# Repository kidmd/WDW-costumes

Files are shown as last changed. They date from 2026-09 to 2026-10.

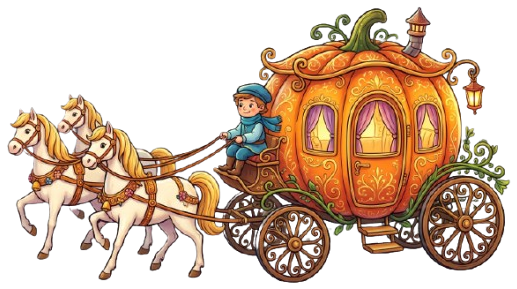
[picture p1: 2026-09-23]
assets/cinderellas_coach.png

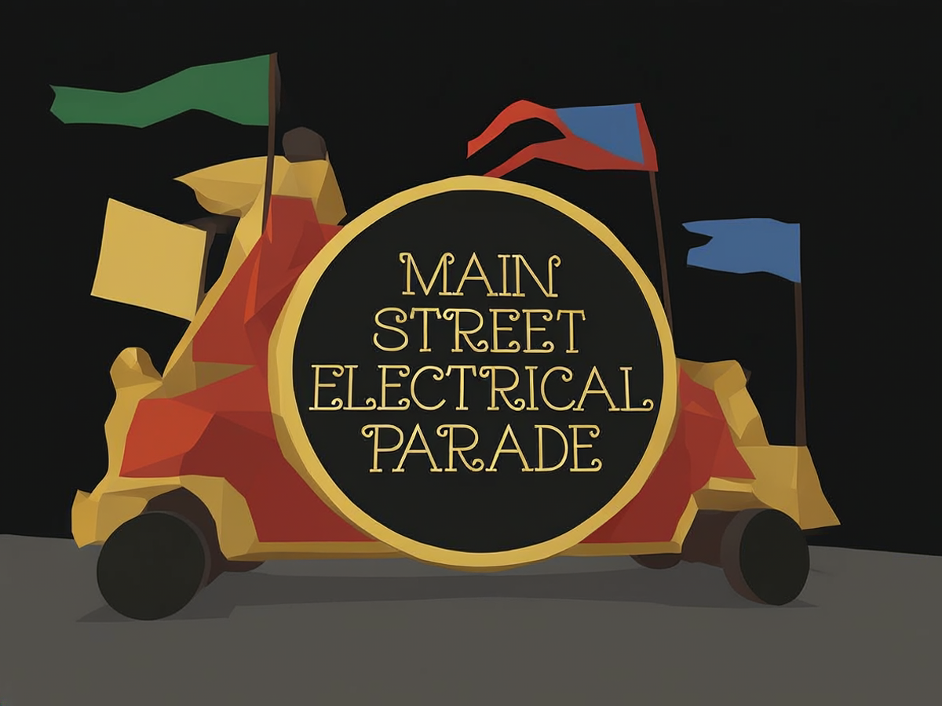
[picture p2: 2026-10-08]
assets/Drum.png

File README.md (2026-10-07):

# Main Street Electrical Parade - Synchronized LED Costumes (WDW 10K)

This project powers synchronized, addressable LED lighting across **7 runner costumes** inspired by Disney's **Main Street Electrical Parade** for the Walt Disney World 10K.

Worn by our **7-member family running team** (2 brothers, 1 sister, 1 brother-in-law, and 3 sisters-in-law) and engineered with love by the **3 brothers** (2 running, 1 supporting behind the scenes).

---

## The Concept

Each runner wears a matte black technical running shirt outlined with glow-in-the-dark paint and illuminated by individually addressable **WS2812B "Seed" / Pebble LEDs** to replicate the vintage incandescent bulbs of the parade floats.

An **ESP32** microcontroller on each runner coordinates lighting patterns wirelessly in real time using **ESP-NOW** (connectionless peer-to-peer 2.4 GHz radio), requiring **no Wi-Fi router or cellular service**.

### The 7 Floats Roster

1. **The Train (Casey Jr.):** Warm white chugging locomotive headlight & steam pulses (parade leader pulling the Title Drum).
2. **The Title Drum:** Golden chasing marquee border, "Disney" electric text accent.
3. **The Turtle:** Whimsical spinning shell spirals, blinking amber eyes, and teal/green shell pattern.
4. **The Snail:** Multi-color rotating rainbow spiral shell wheels and neon antennae glow.
5. **Cinderella's Coach:** Shimmering fairy dust sparkle and midnight pumpkin carriage glow.
6. **Pete's Dragon (Elliott):** Chartreuse/green body scales with orange/red fire breathing effect.
7. **To Honor America (Flag & Eagle):** Patriotic red, white, and blue finale fireworks shimmer with majestic illuminated eagle.

---

## Hardware Specifications

* **Microcontrollers:** ESP32 (e.g. ESP32-WROOM-32D or Seeed XIAO ESP32)
* **LED Strands:** 200 WS2812B / WS2811 Addressable 5V Seed/Pebble Pixels (100 front + 100 back duplicated, black wire, ~1" to 2" spacing)
* **Data Resistor:** 220 Ω to 470 Ω inline on the data line between GPIO 16 and LED Data-In
* **Power Source:** 5V USB portable power bank (5,000–20,000 mAh rating, FastLED hardware limited to 2000 mA / 2.0A) per runner with built-in simulator Battery Life & Power Budget Calculator
* **Costume Simulation:** Visual browser-based layout engine (`python simulator.py` @ `localhost:8000`) with built-in presets (Pete's Dragon, Cinderella's Coach, Carriage No Horses, Casey Jr., Title Drum, Turtle, Snail, Eagle), multi-layer Cricut Heat Transfer Vinyl (HTV) cut file exporter suite (All-in-One master SVG, color-mat-by-color-mat SVGs, and 6×3mm tangent pill cutouts with 4-corner heat press registration marks), Universal Undo / Redo engine (`Ctrl+Z` / `Ctrl+Y`) with 50-step snapshot history and floating toolbar buttons, 7-Shirt Fleet Show Creator Studio featuring a 19-block choreography palette (traveling waves, dual collision shockwaves, butterfly ripples, fairy dust waterfalls, fleet pulses, wig-wags, sparkle storms, baton chases, and grand finales), interactive NLE-grade visual timeline block editor (drag-to-stretch, rolling trim, and drag-and-drop reordering), Animation Group Spatial Suite & Pre-Built Shape Stamp Library (parametric Circles/Wheels, Arches, Waves, Stars/Sparkles, Lines/Rulers, and Fireworks Starbursts with aspect-ratio correction, interactive click-to-place positioning, Cross-Shirt Clipboard, Rotate 90°, Flip H/V, Scale LED Spacing while maintaining exact shape, and auto-rearranging remaining unassigned LEDs), multi-float live Wi-Fi UDP streaming (`Opcode 0x02`), pre-race Corral Roll Call & ESP-NOW Fleet Radar (instant identification strobe, 4s rapid attendance wave, signal RSSI, battery voltage, and lineup readiness), race-day battery life calculator with 7-float power breakdown, double-tap 4-second rapid attendance wave, 300ms debounced one-shot trigger and early stop, "Snap to 30.0s" sequence normalization, JSON show persistence, 1-click & double-click Single View editing from fleet cards, real 700-LED mini-shirt visualizer, multi-mode wireless sync (ESP-NOW Wave, Free-Run, Show Sequence), full-graphic LED re-distribution (maintaining strictly 100 LEDs per shirt), and authentic runDisney 10K Race Bib (#1952) with Chip & Dale and BibBoards fastener clearance.
* **3D-Printable Flexible TPU Armor Plates & Protective Rear Lids (5-Color Multi-Material & Single STL):** High-speed parametric fabrication pipeline (`scripts/compile_clean_tpu_panel.py`) compiling wearable 9.0mm deep-chassis armor trays and matching **2.0mm protective rear cover lids** (`tpu_panel_{front|back}_lid.stl`). Features **5-Color Multi-Material FDM printing** (for Bambu Lab AMS / Snapmaker Dual) with a monolithic black structural chassis (`chassis_black.stl`), 4 zero-overlap jigsaw front color inlays, 3x3mm through-aperture windows for LEDs, and an 8-point M2 perimeter screw fastening system with 1.2mm stepped alignment ridges. Includes 1-click **Bambu 3MF** and **5-Color ZIP bundles** (packaging tray, inlays, and rear lid), selectable plate sizing (Small ~6.5", Medium ~8.0", Large ~10.0"), selectable LED counts (50, 75, 100 LEDs), and an interactive 3D WebGL inspector (`#tpuPreviewModal` & `3d_panels/tpu_panel_preview.html`) with live Tray vs Rear Lid 3D inspection.

---

## Wireless Synchronization (ESP-NOW)

* **Protocol:** ESP-NOW broadcast (Destination MAC `FF:FF:FF:FF:FF:FF`).
* **Architecture:**
  * **Float 1 (Primary Master Leader):** Front locomotive broadcasting timing ticks, BPM tempo, master brightness, show triggers, and photo mode.
  * **Float 7 (Co-Leader / Rear Marshal):** Rear anchor with full co-leader authority to command the rear pack independently if runners split.
  * **Floats 2–6 (Followers):** Listen to broadcast packets, lock to master clock, and execute individual autonomous sequences or synchronized routines.
* **Dual Hardware Button Controls (Button 1: GPIO 4 / BOOT GPIO 0, Button 2: GPIO 33):**
  * **Power-Up (Plug USB):** Boots directly into **🌙 Corral Standby Mode** (12% dim midnight starlight twinkle, < 120mA), saving 80%+ battery during the 60–90 min starting wait.
  * **Button 1 — Single Tap (< 600ms):**
    * 👑 *Leader (Float 1 & 7):* When asleep or in Photo Mode, wakes **ENTIRE FLEET** into **Solo Show Mode** (individual float identities). When running awake, launches the **30s Synchronized Fleet Routine** (or toggles/cancels during active routine).
    * 👥 *Follower (Floats 2–6):* When asleep or in Photo Mode, wakes/exits **THAT RUNNER ONLY** into Solo Show Mode. When running awake, **IGNORED** (keeps parade show running without accidental interruption).
  * **Button 1 — Double Tap (< 400ms):**
    * 👑 *Leader:* Triggers **⚡ 4-Second Rapid Attendance Roll Call** wave across all 7 costumes.
    * 👥 *Follower:* Ignored (roll call reserved for Leader).
  * **Button 1 — Long Hold (5s):**
    * Enter **Float ID Configuration Mode** (1 to 7) with a 1s–4s progressive white LED charging meter and permanent NVS flash auto-save. Releasing before 5s cleanly aborts back to baseline without triggering show routines.
  * **Button 2 — Single Tap (< 600ms):**
    * 👑 *Leader:* Toggles **📸 Castle Photo Mode** (solid, steady, non-flickering full graphic background colors) across the **ENTIRE FLEET**.
    * 👥 *Follower:* Toggles **📸 Castle Photo Mode** **LOCALLY** (solid full graphic background colors) for that runner.
  * **Button 2 — Long Hold (3s):**
    * 👑 *Leader:* Drops **ENTIRE FLEET into Corral Standby (Sleep) Mode**. Stays locked in Standby even if held >3s—requiring an explicit click to enter Photo Mode.
    * 👥 *Follower:* Drops **THAT RUNNER ONLY into Corral Standby Mode**. Stays locked in Standby even if held >3s—waiting for physical release so it never accidentally pops into Photo Mode.

---

## ⚡ Quick Start for Family Runners & Crew (No Git Required!)

You don't need Git, Google Antigravity, or any programming tools:
1. **Download:** Click the green **`<> Code`** button above ➔ **`Download ZIP`** (or [Click Here to Download ZIP](https://github.com/kidmd/WDW-costumes/archive/refs/heads/main.zip)).
2. **Extract:** Right-click the `.zip` file and select **Extract All...** to any folder on your computer.
3. **Plug in & Flash:** Connect your ESP32 via USB and double-click **`flash_firmware.bat`** (Windows) or **`flash_firmware.command`** (Mac).
4. See **[`FLASHING_INSTRUCTIONS.md`](FLASHING_INSTRUCTIONS.md)** for complete hardware wiring and float selection instructions.

---

## Project Structure & Documentation

* [`ESP32_WIRING_PLAN.md`](ESP32_WIRING_PLAN.md): **🔌 ESP32 Hardware Wiring Plan & Electrical Specification** — Complete schematics, pinout tables, tactile button wiring, 4-pin orientation guide, 220–470 Ω data resistor, power bus injection, and computer power isolation rules.
* [`RACE_DAY_BUTTON_GUIDE.md`](RACE_DAY_BUTTON_GUIDE.md): **🏃🏰 Race Day Button Field Guide & Controller Cheat Sheet** — Pocket manual with gesture timings, Leader vs Follower matrices, chronological corral countdown playbook, and state flow diagrams.
* [`RACE_DAY_PACKING_CHECKLIST.md`](RACE_DAY_PACKING_CHECKLIST.md): **🏰 Race Day Packing Checklist & Field Manual** — Pre-race hardware checklist, spare ESP32s, battery survival, repair toolkit, weather kit, and countdown timeline for the 7-runner family team.
* [`CRICUT_MASTER_SVG_USER_GUIDE.md`](CRICUT_MASTER_SVG_USER_GUIDE.md): **✂️ Cricut Master SVG User Guide** — Step-by-step instructions for Cricut Design Space, multi-layer HTV cutting, and heat-press registration.
* [`SIMULATOR_QUICKSTART.md`](SIMULATOR_QUICKSTART.md): **⚡ Simulator Quickstart Guide (TL;DR)** — 2-minute cheat sheet for launching the simulator, moving/trimming timeline clips, testing the fleet show, and streaming to LEDs.
* [`SIMULATOR_USER_GUIDE.md`](SIMULATOR_USER_GUIDE.md): **Complete User Guide & Theatrical Lighting Manual** for the browser simulator, multi-layer timeline, and ESP32 hardware flasher.
* [`FLASHING_INSTRUCTIONS.md`](FLASHING_INSTRUCTIONS.md): **⚡ Quick Flashing Guide for Family Runners & Crew** (Double-click 1-click flasher, Web Browser flasher, and Arduino IDE).
* [`CRICUT_ARTWORK_GUIDE.md`](CRICUT_ARTWORK_GUIDE.md): **🎨 Cricut HTV Costume Artwork Guide** (Layered SVG cut files, color mats, heat press settings, and visual catalog).
* [`PROJECT_PROGRESS.md`](PROJECT_PROGRESS.md): Live project milestones, wiring specifications, and development changelog.
* `start_simulator.bat`: One-click Windows desktop simulator launcher.
* `flash_firmware.bat`: One-click Windows desktop firmware flasher script.
* `flash_firmware.command`: One-click Mac / Linux desktop firmware flasher script.
* `arduino/MSEP_Costume/`: Ready-to-open native Arduino IDE sketch.
* `firmware/`: Pre-compiled ROM binary files (`firmware_float1.bin` through `firmware_float7.bin`, `firmware.bin`, `bootloader.bin`, `partitions.bin`) and Web Serial manifests.
* `src/`: C++ / Arduino firmware source code for ESP32.
* `simulator/`: Web-based visual simulator and theatrical cue director.
* `platformio.ini`: PlatformIO configuration with board targets and library dependencies (FastLED).

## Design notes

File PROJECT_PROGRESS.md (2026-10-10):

# Main Street Electrical Parade (WDW 10K) - LED Control System

## Project Overview
This project coordinates synchronized, addressable LED lighting across **7 runner costumes** styled as the iconic floats of Disney's **Main Street Electrical Parade** for the Walt Disney World 10K.

* **Theme:** Main Street Electrical Parade (7 Floats)
* **GitHub Repository:** [kidmd/WDW-costumes](https://github.com/kidmd/WDW-costumes)
* **Base Shirts:** Black moisture-wicking technical running shirts with glow-in-the-dark graphic outlines
* **Lighting:** 5V WS2812B "Seed / Pebble" RGBIC fairy pixel strings (~1" to 2" spacing for discrete light bulb look)
* **Runners & Engineering Team:** 7 family runners hitting the course together (2 brothers, 1 sister, 1 brother-in-law, and 3 sisters-in-law), supported and engineered by the 3 brothers (2 running, 1 supporting).
* **Controller:** ESP32 Microcontrollers (1 per runner)
* **Wireless Protocol:** ESP-NOW (connectionless 2.4GHz peer-to-peer broadcast; no router/hotspot needed)
* **Power Source:** 5V USB portable power bank per runner

---

## The 7-Runner Roster & Float Assignments

| Float # | Unit / Float Name | Visual Concept & Accent Lights |
| :---: | :--- | :--- |
| **1** | **The Train (Casey Jr.)** | Warm white chugging headlight, locomotive steam pulses (parade leader pulling the Title Drum) |
| **2** | **The Title Drum** | Golden chasing marquee border, "Disney" electric text accent |
| **3** | **The Turtle** | Whimsical spinning shell spirals, blinking amber eyes, teal/green glow |
| **4** | **The Snail** | Rotating rainbow spiral wheels, neon antennae, vibrant spinning motion |
| **5** | **Cinderella's Coach** | Brilliant fairy dust shimmer, pumpkin coach starlight glow |
| **6** | **Pete's Dragon (Elliott)** | Chartreuse/green scales with orange/red fire breathing effect |
| **7** | **To Honor America (Flag & Eagle)** | Cascading patriotic red/white/blue starbursts & majestic illuminated eagle |

---

## Hardware Architecture & Bench Wiring

### 1. Key Components
- **Microcontrollers:** ESP32 development boards (standard DevKit or Seeed Studio XIAO ESP32)
- **LED Strands:** WS2812B 5V Seed/Pebble pixels (black wire, individual encased nodes)
- **Resistor:** 220 Ω to 470 Ω inline on the data line (between ESP32 GPIO and LED Data-In)
- **Power:** 5V USB Battery Pack (2.1A+ output rating)

### 2. Bench Power Isolation Rules
* **USB-C from Computer:** Plugs into the ESP32 USB-C port for code upload and serial debugging.
* **5V Power Brick / Adapter:** Plugs directly into the breadboard +5V rail powering the LEDs.
* **GND (Common Ground):** ESP32 GND and Power Bank GND are connected together.
* **DO NOT** connect the 5V power bank rail to the ESP32 VIN pin while the USB-C cable is connected to the PC.

---

## Roadmap & Milestones

- [x] **Milestone 1: Bench Setup & Single-Strand Validation**
  - [x] Configure toolchain in Antigravity (PlatformIO Core 6.2.0 installed & verified).
  - [x] Create baseline MSEP animation sketch with FastLED current limiting (`src/main.cpp`).
  - [x] Build and compile firmware successfully with FastLED library.
  - [x] Connect ESP-32D via USB and flash test firmware:
    - **Board 1 MAC:** `B0:CB:D8:C8:49:84`
    - **Board 2 MAC:** `A4:F0:0F:64:33:A0`
  - [x] Bench wire ESP32 with isolated 5V power, common ground, and GPIO 16 (pin 8 on right).
  - [x] Verify discrete bulb appearance, color calibration (RGB order established), and animation playback.

- [x] **Milestone 2: ESP-NOW Wireless Synchronization**
  - [x] Build unified firmware with auto-role detection via MAC address (`src/main.cpp`).
  - [x] Flash Board 1 as **Leader (Float 1 - Title Drum)** [`B0:CB:D8:C8:49:84`].
  - [x] Flash Board 2 as **Follower (Float 2 - Casey Jr.)** [`A4:F0:0F:64:33:A0`].
  - [x] Implement synchronized modes: Marquee Chase, Float Sparkle, Starlight Twinkle, and Traveling Parade Wave.
  - [x] Verify bench latency and wireless lockstep synchronization between both strands (SUCCESS).

- [x] **Milestone 3: Python LED Costume Simulator & Visualizer**
  - [x] Lightweight Python local server with zero external dependencies (`simulator.py`).
  - [x] Interactive Single-Shirt view of Pete's Dragon with metallic green reflective styling on black shirt.
  - [x] 50 interactive addressable LEDs with drag-and-drop repositioning and JSON export.
  - [x] Dynamic lighting engine: Green glow with starlight sparkles, fire-breathing snout pulse, marquee chase.
  - [x] Live sliders: Speed (BPM), Sparkle Frequency, Green Hue, Brightness, Glow size.
  - [x] 7-Shirt Fleet Lineup view with animated synchronized Traveling Wave across all 7 floats.
  - [x] One-click FastLED C++ code generator for immediate copy-pasting into ESP32 firmware.

- [ ] **To-Do (Pending Fairy Lights Arrival): Resume Custom Costume Simulator Testing**
  - [ ] Await delivery of WS2812B 5V "Seed / Pebble" RGBIC fairy pixel strings.
  - [x] Implement Real-Time Live Streaming / Tethering (stream pixel colors over Wi-Fi from `simulator.py` directly to ESP32 for instant live-preview without re-flashing).
  - [ ] Resume custom character costume layout and testing with the Web Simulator (`simulator.py`).
  - [ ] Confirm RGB color order on new fairy light hardware and verify power limits.
  - [ ] Test 100-LED Pete's Dragon scatter pattern with starlight diamond sparkles on wearable fairy lights.

- [ ] **Milestone 4: Parade Animation Sequencing**
  - [ ] Implement classic traveling parade chase (running down the line of 7 floats).
  - [ ] Implement float-specific accent animations (fire flickers, clock chime, sparkles).
  - [ ] Optional: Sync tempo to the *Baroque Hoedown* soundtrack.

- [ ] **Next Up / Feature Queue (Imagineering Active Pipeline):**
  - [x] **Interactive Visual Timeline Block Editor:** Directly drag and stretch choreography block edges on the canvas timeline to adjust durations visually; drag-and-drop block reordering on timeline tracks.
  - [x] **Race-Day Battery Life & Power Budget Calculator:** Analytical battery capacity estimator (5,000 mAh / 10,000 mAh packs) modeling running pace (60–90 min 10K), average mA draw per runner, and 30s fleet show trigger frequency.
  - [x] **"Corral Roll Call" / ESP-NOW Fleet Radar Diagnostic:** Pre-race bench & corral RF sniffer verifying that Floats 1 through 7 are powered, connected, and responding on the sync channel before race start.

---

## Progress Log

### 2026-10-10 06:10 - Workbench Mirrored Back View for LED Placement & Assembly Guide
- **Implemented Mirrored Back View in Placement Guide Mode (`simulator/app.js` & `simulator/index.html`):**
  - Horizontally mirrored the placement guide canvas layout, chest graphic artwork (`activeImg`), race bib, LED coordinates (`1.0 - x`), wire routing traces, optical 3×3mm apertures, and interactive mouse drag/click hit-testing when in Placement Guide mode (`graphicVersion === 'assembly_guide'`).
  - Added dedicated UI orientation toggle controls (`[🪞 Mirrored Back]` / `[👕 Normal Front]`) in the Placement Guide options card (`#assemblyGuideOptionsCard`).
  - Ensures workbench builders looking at the physical BACK of the garment while mounting LEDs and routing wires see a 1:1 matching left/right spatial orientation on screen.
  - Text labels (LED numbers `#1`–`#100`, distance tags `cm`, title badge) remain rendered left-to-right for effortless legibility.
  - Updated `printAssemblyGuide()` printable HTML document and PNG exporter to label the perspective as `🪞 Workbench Back View (Mirrored)`.
- **Documentation & User Guide Sync:**
  - Updated `SIMULATOR_USER_GUIDE.md` section on Placement Guide Mode detailing the new `🪞 Mirrored Back View` workbench assembly features and print controls.
- **Verification:**
  - Validated clean execution of `python simulator.py --test` (HTTP API verified, status 200).

### 2026-10-09 01:28 - Browser LocalStorage Quota Overflow Recovery & Resilient Preset Disk Saving
- **Resolved QuotaExceededError on Preset Saving (`simulator/app.js`):**
  - Diagnosed browser screenshot showing `Save error: Failed to execute 'setItem' on 'Storage': Setting the value of 'msep_custom_presets' exceeded the quota.`
  - Wrapped `localStorage.setItem('msep_custom_presets', ...)` in a fail-safe try/catch block with automatic LRU pruning (keeping the 3 most recent entries in browser storage).
  - Ensured server disk saving via `/api/save_preset` executes reliably and writes `.json` files to `presets/` regardless of browser storage constraints.
- **Verification:**
  - Syntax validated clean with `node --check simulator/app.js`.

### 2026-10-09 01:25 - Dynamic Timestamped Float Revision Saves & Filename Updates
- **Automatic Fresh Timestamp Generation on Save Float (`simulator/app.js`):**
  - Resolved issue where saving a float whose name already contained an older date/time string would not update the timestamp or name in the UI.
  - Implemented regex stripping (`/\s+\d{4}-\d{2}-\d{2}(?:[ _-]\d{2}[-:]\d{2}(?:[-:]\d{2})?)?.*$/i`) across `#saveProfileBtn`, `exportCurrentProfileJson()`, and `openSavePresetModal()`.
  - Every click of **💾 Save Float** now strips previous timestamp artifacts, dynamically creates a new date/time tag (e.g. `Pete's Dragon 2026-10-09 01-25`), immediately updates the `#profileNameInput` text field, saves the new `.json` preset to `presets/` on disk, and synchronizes the preset dropdown.
- **Verification:**
  - Syntax validated clean with `node --check simulator/app.js`.

### 2026-10-09 00:28 - 3D Modal Live Layout Canvas Synchronization & Instant Recompile Button
- **Resolved Live Canvas vs. Cached 3D STL Discrepancy:**
  - Diagnosed screenshot evidence where LED #37 on the 2D layout canvas had #52 adjacent to it with clearance, while the 3D preview showed an older compiled STL where #38 was adjacent and touching #37.
  - **3D Modal Live Recompile Action (`simulator/index.html` & `simulator/app.js`):**
    - Added a dedicated `⚡ Recompile 3D Model` action button directly in the top header toolbar of `#tpuPreviewModal`.
    - Users can now re-trigger Manifold C++ / Python CAD compilation directly from within the 3D preview without needing to close the modal.
  - **Enhanced Auto-Recompile Detection (`simulator/app.js`):**
    - Strengthened `openTpuPreviewModal()` stale-STL detection to directly compare in-memory canvas `leds` count and layout coordinates against `sp.ordered_leds`.
    - Guarantees that any LED movement or re-ordering on the 2D canvas automatically recompiles fresh Front & Back STLs before opening the 3D WebGL scene.

### 2026-10-08 23:55 - Circle Aperture Selection Carry-Over Fix for 3D Preview & 3D STL/3MF Exports
- **Seamless Aperture Shape Carry-Over from Layout Page to 3D Previews & Files:**
  - Diagnosed and resolved the root causes preventing aperture shape selections (🔘 **Ø 3.4mm Round**, ⚪ **Ø 3.0mm Round**, 🔲 **3x3mm Square**) from carrying over from the Layout page to the 3D preview and 3D files:
    1. **Layout Page Aperture Reactivity (`simulator/app.js`):**
       - Updated `setTpuWindowShape()` to automatically enable `params.showTpuWindows = true` (and synchronize `#showTpuWindowsToggle`), making the chosen circular aperture instantly visible on the 2D canvas upon clicking.
       - Synchronized both Layout toolbar buttons (`#tpuShapeRound34Btn`, `#tpuShapeRound30Btn`, `#tpuShapeSquareBtn`) and 3D Modal buttons (`#tpuModalShapeRound34Btn`, etc.) seamlessly.
    2. **Stale Check & Normalized Shape Detection (`simulator/app.js`):**
       - Normalized shape comparison in `openTpuPreviewModal()` (`normCompiledShape !== normCurrentShape`) to robustly compare legacy/alias shape strings (`round` / `circle` $\to$ `round_34`) and check variant-level specs (`sp.window_shape` / `sp.front.window_shape`).
       - If a shape mismatch is detected, `openTpuPreviewModal()` automatically initiates a clean re-compilation with the exact chosen aperture before rendering.
    3. **Preset Persistence & Float Switch Restoration (`simulator/app.js`):**
       - Added `tpuWindowShape`, `tpuWellOrientation`, `tpuIncludeLedNumbers`, `tpuIncludeClipGrooves`, and `tpuIncludeTopNubs` to `buildCompletePresetData()`.
       - Added full restoration of all TPU features in `applyProfileData()`, guaranteeing that switching float presets or importing files preserves the runner's circular aperture selection.
    4. **Clean STL Cutter Geometry (`scripts/compile_clean_tpu_panel.py`):**
       - Upgraded aperture boolean cylinder and box cutters with generous height (`FRONT_THICK_GENERAL + 2.0 = 4.0mm`), guaranteeing clean, watertight circular punch-through without coplanar boundary artifacts.
       - Added explicit `window_shape` and `well_orientation` metadata into `specs['front']` and `specs['back']` dictionaries.
       - Updated `README_BAMBU_STUDIO.txt` inside generated ZIP bundles to dynamically describe the active aperture geometry (e.g. `Ø 3.4mm round optical apertures (Default)`).
    5. **Standalone 3D Model Viewer Support (`3d_panels/tpu_panel_preview.html`):**
       - Updated the standalone WebGL viewer (`createGraphicCutoutMesh` and `createLedPixels`) to dynamically read `specsData.window_shape`, punching circular apertures via `ctx.arc()` and rendering circular pixel geometries (`THREE.CircleGeometry`) when round apertures are chosen.
    6. **Cache-Busted Direct Downloads (`simulator/app.js`):**
       - Added timestamped query strings (`?t=${Date.now()}`) to `downloadBothTpuStls()` preventing browser caching of stale STL files.
- **Verification:**
  - Tested compilation across `--window-shape round_34` (Ø 3.4mm), `--window-shape round_30` (Ø 3.0mm), and `--window-shape square` (3x3mm); verified 28-vertex circular boundary on front face ($Z=10.0$) in `tpu_panel_front.stl` and `tpu_panel_front_chassis_black.stl`.
  - Verified JavaScript syntax with `node --check simulator/app.js`.

### 2026-10-08 23:40 - Guaranteed Exit-Adjacent Terminal LED Placement & Pinned Wiring Route
- **Exit-Adjacent Terminal LED Seeding & Routing Assurance:**
  - Guaranteed that upon LED distribution (`scatterLedsOnGraphic`, `rearrangeRemainingLedsOnGraphic`, `sampleRemainingGraphicLeds`), the final LED (#100 or #N) is strictly placed directly adjacent to the **Lateral Exit Strain Relief Bridge** on the right flank:
    1. **Exit Seeding in `selectClearanceAwareFpsIndices` (`simulator/led_clearance.js`):**
       - The initial candidate sampling pass automatically picks the unblocked candidate closest to the **Entrance Bridge** as Seed 1, and the unblocked candidate closest to the **Lateral Exit Bridge** as Seed 2 (or first remaining unassigned pick if no group anchor exists near the exit).
       - This guarantees high-density spatial coverage directly adjacent to both the entrance and exit conduits before Farthest Point Sampling fills out the rest of the body.
    2. **Pinned Terminal Endpoint Routing in `optimizeLedWiringOrder` (`simulator/app.js`):**
       - Linked `entrancePos` and `exitPos` directly to `getTpuBridgeLocationsNorm()` CAD coordinates rather than generic bounding-box estimates.
       - Fixed a critical 2-Opt uncrossing bug: restricted 2-Opt edge swapping to internal segments (`j < n - 1`), preventing the final exit node (`path[n - 1]`) from being accidentally swapped out into the middle of the shirt during segment reversals.
       - Both the first LED (`path[0]`) and last LED (`path[n - 1]`) remain permanently pinned at the Entrance and Exit bridges respectively.
    3. **Bumped Cache Busters:** Updated `simulator/index.html` to `led_clearance.js?v=2` and `app.js?v=102`.
- **Verification:**
  - `node --check simulator/led_clearance.js` and `node --check simulator/app.js` passed with zero errors.

### 2026-10-08 23:30 - Strict Clearance-Aware Initial Placement & Relaxation Engine (Zero 2mm/2.5mm Warnings)
- **Clearance-Aware Farthest Point Sampling (FPS) & Solver Architecture (`simulator/led_clearance.js`):**
  - Eliminated recurring 2mm / 2.5mm wire corridor and collar collision warnings (`checkLedClearanceStatus`) across initial LED placement (`scatterLedsOnGraphic`), remaining LED redistribution (`rearrangeRemainingLedsOnGraphic`), and fireworks/group generation (`sampleRemainingGraphicLeds`).
  - **Symmetric Wire Corridor Checking (`ledPairViolatesMm`):**
    - Evaluates dual wire openings ($\pm \vec{u}$) for both LEDs symmetrically in true physical millimetres:
      $$\text{Opening}_A \leftrightarrow \text{Collar}_B \quad \text{AND} \quad \text{Opening}_B \leftrightarrow \text{Collar}_A \quad (d < 4.3\text{mm} + \text{margin})$$
    - Checks spine-to-spine distance ($< 8.65\text{mm} + \text{margin}$) and 10mm strain relief keep-out exclusion zones.
  - **Clearance-Aware Farthest Point Sampling (`selectClearanceAwareFpsIndices`):**
    - Replaced naive Euclidean FPS (which blindly placed points near tight corners or wire corridors) with candidate clearance filtering. Evaluates candidate points with a $+1.0\text{mm} \to +0.3\text{mm}$ safety buffer against already placed points and strain relief bridges, preventing 95%+ of collisions before relaxation starts.
  - **Multi-Pass Relaxation & Nearest Valid Spot Repair (`resolveLedClearance`):**
    - High-iteration spring relaxation ($160$ iterations) with directional opening push forces.
    - Silhouette-aware snapping (`snapToArtwork`) keeps LEDs firmly on valid artwork pixels without drifting into negative space.
    - Concentric ring search (`searchFreeSpot`) relocates any stubborn violating LED to the nearest valid on-artwork position that produces zero warnings for both itself and all neighbors, dynamically updating pixel vibrancy color matching.
  - **Integrated with `app.js` & `index.html`:**
    - Loaded `led_clearance.js?v=1` ahead of `app.js` in `simulator/index.html`.
    - Wired clearance engine into `rearrangeRemainingLedsOnGraphic()`, `scatterLedsOnGraphic()`, and `sampleRemainingGraphicLeds()`.
- **Verification:**
  - `node --check simulator/led_clearance.js` and `node --check simulator/app.js` passed with zero errors.

### 2026-10-08 23:18 - Exact 3D STL Strain Relief Bridge Alignment & Outside Icon Clutter Removal
- **1:1 Geometric Alignment with 3D Manifold CAD Coordinates:**
  - Diagnosed root cause of strain reliefs appearing as icons outside the graphic area:
    1. `getTpuBridgeLocationsNorm()` had previously estimated positions using bounding box extremes (`gb.normX + gb.normW * 0.5` and `gb.normX + gb.normW - 10mm`), pushing the exit bridge out to the empty edge of the rectangular bounding box instead of the organic dragon contour.
    2. Fallback text badges in `renderSingleShirtView()` had rendered huge external badge boxes (`pExit.x + 35`, `pEnt.y + 19.5`) floating outside the costume shirt area.
  - Linked `getTpuBridgeLocationsNorm()` directly to compiled 3D STL plate specs (`entrance_portal`, `entrance_bridge`, `exit_portal`, `exit_bridge`):
    - Converted 3D Manifold CAD coordinates ($x_{\text{mm}}, y_{\text{mm}}$) to normalized canvas coordinates:
      $$x_{\text{shirt}} = gb.\text{normX} + \frac{x_{\text{mm}}}{W_{\text{img}}} \cdot gb.\text{normW}$$
      $$y_{\text{shirt}} = gb.\text{normY} + \left(1.0 - \frac{y_{\text{mm}}}{H_{\text{img}}}\right) \cdot gb.\text{normH}$$
    - Bottom Entrance Bridge: Positioned directly on the bottom foot contour of Elliott ($x_{\text{rel}} = 0.3880, y_{\text{rel}} = 0.8250$), matching 3D coordinates `[88.33, 47.82]`.
    - Lateral Exit Bridge: Positioned directly on the right flank contour of Elliott ($x_{\text{rel}} = 0.6277, y_{\text{rel}} = 0.7175$), matching 3D coordinates `[142.91, 77.19]`.
  - Removed all external floating icon boxes (`⚡ IN (P1)` and `OUT ➔` floating 35px outside the graphic).
  - Streamlined `drawStrainReliefBridgesOverlay(ctx)` to draw compact, neat technical annotations (`⚓ IN BRIDGE` and `⚓ OUT BRIDGE` with `10mm KEEP-OUT`) directly at the physical bridge footprints inside the character silhouette.
  - Bumped script cache buster in `simulator/index.html` to `app.js?v=101`.
- **Verification:**
  - `python scripts/compile_clean_tpu_panel.py --orientation horizontal` compiled both plates and verified `entrance_bridge` and `exit_bridge` coordinate exports.
  - `node --check simulator/app.js` passed with zero errors.
- **Independent Canvas Overlay Rendering:**
  - Resolved issue where strain relief bridges were hidden when `showWireTension` or `showWiring` were unselected by moving `drawStrainReliefBridgesOverlay(ctx)` completely outside the conditional wiring block in `renderSingleShirtView()`.
  - Defaulted `params.showStrainReliefs` to `true` and updated `#showStrainReliefsToggle` with `checked` attribute so strain relief bridge locations and 10mm keep-out circles are immediately visible on initial load.
  - Enhanced overlay visuals with:
    1. Dotted leader lines connecting from the IN bridge tunnel directly to LED 0 and from the last LED to the OUT bridge tunnel.
    2. Perimeter rim U-notch marker dots and solid through-conduit paths.
    3. Glowing high-contrast badges for `⚓ IN STRAIN RELIEF` and `⚓ OUT STRAIN RELIEF` with `10mm KEEP-OUT` tags.
  - Bumped script cache buster in `simulator/index.html` to `app.js?v=100`.
- **Verification:**
  - `node --check simulator/app.js` passed with zero errors.
- **Window Shape Parameter Precedence & Specs Cache Override:**
  - Diagnosed root cause why 3D preview kept reverting to square apertures when round windows were selected:
    1. In `simulator/app.js` (`loadTpuModalData`, `createTpuGraphicCutoutMesh`, and `createTpuLedPixels`), the code evaluated `specs.window_shape || params.tpuWindowShape || 'round_34'`. If an older `tpu_panel_specs.json` on disk contained `"window_shape": "square"`, it took precedence over the active UI selection `params.tpuWindowShape`.
    2. Fixed parameter precedence across all 3D generation functions to strictly prioritize active user intent: `params.tpuWindowShape || specs.window_shape || 'round_34'`.
    3. Recompiled both Front and Back plate STLs with `--window-shape round_34 --orientation horizontal` and updated `3d_panels/tpu_panel_specs.json` and `3d_panels/petes_dragon_specs.json` with `"window_shape": "round_34"`.
    4. Bumped script cache buster in `simulator/index.html` to `app.js?v=98`.
- **Verification:**
  - Recompilation executed in 8.05s with `window_shape: round_34` (Ø 3.4mm circular window cutters).
  - `node --check simulator/app.js` passed with zero errors.

### 2026-10-08 22:47 - End-to-End Horizontal Collar Orientation 3D Preview Fix
- **Complete Pipeline Parameter Unification:**
  - Resolved root cause where 3D preview collars remained tangent even when horizontal alignment was selected on the layout canvas:
    1. In `scripts/compile_clean_tpu_panel.py`, `compile_plate_variant` function signature was missing the `well_orientation` parameter and was reading from global specs with a default of `'tangent'`, ignoring the passed `--orientation horizontal` flag for internal plate compilations.
    2. Updated `compile_plate_variant(..., well_orientation='horizontal')` signature and passed `well_orientation` explicitly to both Front and Back plate compilations.
    3. Updated `simulator/simulator.py` and `simulator/app.js` payload builders to strictly default `wellOrientation: params.tpuWellOrientation || 'horizontal'`.
    4. Updated Three.js optical cutout mask (`createTpuGraphicCutoutMesh`) and simulated LED pixel groups (`createTpuLedPixels`) in `simulator/app.js` to strictly enforce `rotDeg = 0` when horizontal mode is active unless an LED is explicitly marked with `is_custom_rotation: true`.
  - Recompiled both Front and Back plate STLs and updated `3d_panels/tpu_panel_specs.json` with all un-rotated LEDs at $0.0^\circ$ baseline.
- **Verification:**
  - `python scripts/compile_clean_tpu_panel.py --orientation horizontal` ran successfully in 7.35s with `orientation: horizontal` for all 65 LEDs.
  - `node --check simulator/app.js` passed with zero errors.

### 2026-10-08 22:40 - TPU Layout Signature ReferenceError & Cache Busting Fix
- **`computeTpuLayoutSignature` Fatal ReferenceError Resolution:**
  - Diagnosed exact runtime crash causing modal loading freeze: `computeTpuLayoutSignature()` referenced undefined variables `src` and `gb`, triggering an uncaught `ReferenceError: src is not defined` immediately upon calling `openTpuPreviewModal()`.
  - Added safe fallbacks for `src`, `gb`, `getActiveGraphicImg()`, `getActiveFloatStlColors()`, and wrapped the entire layout signature generator in a `try ... catch` with fallback timestamp.
  - Wrapped `openTpuPreviewModal()` initialization and auto-recompile sequence in robust `try ... catch` blocks to guarantee control always proceeds to `loadTpuModalData()`.
  - Bumped script cache query in `simulator/index.html` to `app.js?v=96`.
- **Node Syntax Verification:**
  - Ran `node --check simulator/app.js` with zero errors.

### 2026-10-08 22:36 - 3D Preview Modal Loading Hang & Event De-duplication Fix
- **Modal Event Listener & Double-Invocation Resolution:**
  - Diagnosed root cause of the modal getting stuck on `"Loading Binary STL & Compiling Shaders..."`: `#openTpuPreviewModalBtn`, `#closeTpuPreviewModalBtn`, and `#closeTpuPreviewModalBottomBtn` had both inline HTML `onclick` attributes in `simulator/index.html` and JavaScript `addEventListener('click', ...)` bindings in `simulator/app.js`.
  - When the user clicked "Preview 3D TPU Panels", `openTpuPreviewModal()` executed twice simultaneously. Request #1 incremented `tpuLoadRequestId = 1`, and Request #2 incremented it to `2`.
  - When Request #1 finished, it evaluated `reqId !== tpuLoadRequestId` (1 !== 2) and exited early without dismissing `#tpuModalLoading`, leaving the spinner overlay permanently visible over the canvas.
  - Stripped duplicate inline `onclick` handlers from `simulator/index.html` and added a strict re-entrancy guard in `openTpuPreviewModal()`.
- **Three.js STLLoader Timeout & Safe Handling (`loadStlWithTimeout`):**
  - Created `loadStlWithTimeout(stlLoader, url, timeoutMs = 8000)` wrapper that prevents unhandled promise rejections and gracefully falls back or resolves `null` on network/file fetch issues.
  - Refactored `loadTpuModalData()` with a `try ... catch ... finally` block, ensuring `#tpuModalLoading` is guaranteed to be dismissed (`loaderOverlay.style.display = 'none'`) once processing completes.
- **Node Syntax Verification:**
  - Ran `node --check simulator/app.js` with zero errors.

### 2026-10-08 22:28 - Horizontal Channel Orientation & 3D STL Synchronization Fix
- **Global Horizontal Channel Alignment Enforcement:**
  - Diagnosed root cause why horizontal alignment on the Layout tab produced tangent collars in 3D preview: `getTpuWellRotationAngle` in `simulator/app.js` and `compile_clean_tpu_panel.py` were checking `if ('rotation_deg' in leds[i])` before checking the global `well_orientation == 'horizontal'` mode. If an LED had an old tangent angle cached, it overrode the horizontal mode.
  - Added explicit `is_custom_rotation` flag: only LEDs that have been explicitly rotated individually via the Inspector Angle controls retain their custom angle.
  - When Channel Alignment is set to **`[ ↔️ Horizontal ]`**, all un-customized LEDs strictly evaluate to $0.0^\circ$ baseline across the 2D layout canvas, layout signature hash, API payload, and 3D STL compilation engine (`compile_clean_tpu_panel.py`).
  - Verified compilation: running `python scripts/compile_clean_tpu_panel.py --orientation horizontal` produces 100% horizontal ($0.0^\circ$) collar pockets in the 3D meshes and `tpu_panel_specs.json`.

### 2026-10-08 22:10 - Wire Entrance Corridor Clearance Standard & Side Wall Tab Cleanup
- **Wire Entrance / Exit Corridor Focus:**
  - Clarified clearance standard per user requirements: checking is strictly focused on the wire entrance and exit notches at both ends of each LED collar ($\pm \vec{u}_i$), enforcing a $2.5\text{ mm}$ clear corridor in front of each wire notch so wires enter/exit cleanly without kinks or pinching.
  - Side walls of adjacent collars are allowed to sit close to each other without triggering false red warnings, provided they do not physically collide ($d_{\text{physical}} \ge 0.0\text{ mm}$, spine distance $\ge 8.6\text{ mm}$).
- **Removal of Red Side Wall Tabs:**
  - Removed lateral side-wall buffer indicator rectangles that previously rendered red boxes on the long side walls of collars.
  - Retained wire entrance/exit notch indicators at $+X$ and $-X$ collar ends, which outline in red only when an adjacent collar obstructs that specific wire entrance.
- **Dynamic Clamping & Relaxation Synchronization:**
  - Updated `checkLedClearanceStatus`, `clampLedNoCollarOverlap`, and `relaxLedCollarOverlaps` in `simulator/app.js` and `scripts/compile_clean_tpu_panel.py` to enforce zero collar collision (`req_dist = 8.6mm`), $2.5\text{ mm}$ wire entrance clearance, and $10.0\text{ mm}$ bridge clearance.

### 2026-10-08 21:26 - 3D File LED Well Orientation Synchronization & Individual LED Rotation Engine
- **3D File & Slicer Orientation Alignment:**
  - Diagnosed root cause for 3D files exporting horizontal wells: `params.tpuWellOrientation` defaulted to `'horizontal'`, sending `0.0°` rotations to the compiler despite tangent angles appearing on 2D canvas pills.
  - Set default `params.tpuWellOrientation = 'tangent'` across simulator, API endpoint, and compiler scripts.
  - Implemented 2D-to-3D coordinate angle transformation in `scripts/compile_clean_tpu_panel.py`: compensated for inverted-Y coordinate space ($\theta_{\text{3D}} = -\theta_{\text{canvas}} \pmod{360}$), ensuring that in slicers (Bambu Studio, PrusaSlicer, Orca) and 3D preview, every single collar is oriented at the exact angle displayed on the Layout canvas.
- **Individual LED Rotation Controls & Inspector Dock Card:**
  - Added dedicated **🔄 LED Well Angle Card** to `#ledInspectorSection` in `simulator/index.html` and `simulator/app.js`:
    - **Continuous Slider ($0^\circ$ to $360^\circ$):** Live scrubbing updates the rotation of the selected LED(s) in real time on the canvas.
    - **Numeric Degree Input:** Direct degree entry ($0.0^\circ$ to $360.0^\circ$) with live validation.
    - **Mode Badge:** Live indicator showing `[ 〰️ Tangent ]` or `[ 🔒 Custom XX° ]`.
    - **`[ 〰️ Auto ]` Reset Button:** Restores automatic wire-tangent orientation and clears manual lock.
    - **Quick Angle Presets & Nudges:** 1-click angle buttons (`0° Horiz`, `45°`, `90° Vert`, `135°`) plus `⟲ -15°` and `⟳ +15°` step buttons.
    - **Keyboard Shortcuts:** `R` nudges rotation $+15^\circ$ clockwise; `Shift + R` nudges $-15^\circ$ counter-clockwise when LED(s) are selected.
    - **Visual Orientation Axis:** Selected LEDs render a directional green axis arrow showing the orientation angle directly on the garment canvas.
- **Unified Rendering & Cache Invalidation:**
  - Updated `showPillSlots` and `showTpuWindows` in `renderBulb` to use `getTpuWellRotationAngle(index, leds)`.
  - Updated `computeTpuLayoutSignature()` to hash per-LED rotation angles, ensuring rotating an LED automatically invalidates stale STLs and triggers re-compilation.

### 2026-10-08 21:55 - Unified 3.0mm Clearance Standard Across Wire Channels & Collar Flanks
- **Unified 3.0mm Clearance Enforcement & Real-Time Canvas Warnings:**
  - Standardized both the longitudinal wire channel opening corridors and the lateral collar side buffers to **$3.0\text{mm}$** ($16.6\text{mm}$ center-to-center along channel, $11.6\text{mm}$ center-to-center laterally).
  - Updated all canvas drag warnings, blocked corridor overlays, and tooltip badges in `simulator/app.js` (`renderBulb`, `checkLedClearanceStatus`) to explicitly reflect **`⚠️ 3mm Clearance`** and `(<3mm channel clearance)`.
  - Updated `clampLedNoCollarOverlap`, `relaxLedCollarOverlaps`, and `scripts/compile_clean_tpu_panel.py` to enforce the $16.6\text{mm} \times 11.6\text{mm}$ footprint ($3.0\text{mm}$ all-around collar clearance).
- **Python Compiler & 3D Export Verification:**
  - Recompiled front and back plates in 8.40s; verified zero manifold errors.

### 2026-10-08 21:50 - 3mm Side Clearance Refinement & Visual Buffer Indicators
- **3.0mm Side / Lateral Clearance Enforcement:**
  - Updated `checkLedClearanceStatus` in `simulator/app.js` and PBD relaxation solver in `scripts/compile_clean_tpu_panel.py` to enforce a $3.0\text{mm}$ side clearance buffer between adjacent collar side walls (lateral center-to-center distance $\ge 11.6\text{mm}$, calculated as $4.3\text{mm} + 4.3\text{mm} + 3.0\text{mm}$).
  - Updated `clampLedNoCollarOverlap` and `relaxLedCollarOverlaps` to maintain both the $18.6\text{mm}$ channel opening corridor ($5.0\text{mm}$ in front of wire openings) and $11.6\text{mm}$ lateral collar spacing ($3.0\text{mm}$ side clearance).
  - Added dual $3.0\text{mm}$ red lateral buffer indicators in `renderBulb` whenever side clearance is violated.
- **Python Compiler & 3D Export Verification:**
  - Recompiled front and back plates in 8.50s; verified PBD solver convergence with max shift $\le 0.01\text{mm}$.

### 2026-10-08 21:40 - Optical Aperture Carryover, 5mm Channel Clearance & Live Red Drag Feedback, Strain Relief Clearances & Clean Monolithic Bridges
- **Circular & Square Optical Aperture Carry-Over to 3D Preview:**
  - Updated `setTpuWindowShape` and `setTpuWellOrientation` in `simulator/app.js` to automatically display the compilation loading overlay and re-compile/reload the 3D viewer when toggling window shape (`Ø 3.4mm Round`, `Ø 3.0mm Round`, `3x3mm Square`) or well orientation while the 3D Armor Panel modal is open.
  - Aligned default fallback orientation in `openTpuPreviewModal` to `tangent` (`params.tpuWellOrientation || 'tangent'`) to prevent unnecessary recompilation triggers on modal launch.
- **Strain Relief Bridge Clean Monolithic Arch (Misplaced Gusset Removal):**
  - Removed misplaced internal triangular gussets from both entrance and lateral exit zip-tie strain relief bridges in `scripts/compile_clean_tpu_panel.py` (`internal_bridge_m` and `internal_bridge_exit_m`).
  - Both bridges are now clean, robust monolithic arch boxes with unobstructed $3.2\text{mm} \times 2.8\text{mm}$ through-tunnels for zip-tie heads and $4.5\text{mm}$ wire saddle cradles.
- **5mm Channel Opening Clearance Enforcement & Live Red Visual Feedback:**
  - Implemented `checkLedClearanceStatus(index, ledsList)` in `simulator/app.js`: calculates longitudinal unit vector $\vec{u}_i = (\cos\theta_i, \sin\theta_i)$ and perpendicular vector $\vec{v}_i = (-\sin\theta_i, \cos\theta_i)$ for each LED collar in plate millimeter space.
  - Enforced a $5.0\text{mm}$ clearance corridor in front of each channel opening ($p \in [4.5\text{mm}, 18.6\text{mm}]$ with lateral corridor width $8.0\text{mm}$).
  - Enforced a $10.0\text{mm}$ buffer from both entrance and lateral exit strain relief bridges.
  - Updated `renderBulb` in `simulator/app.js`:
    - When clearance is violated, renders the outer TPU collar outline in vibrant red (`#ff3366`, `lineWidth = 2.2`), tints the collar cavity red, highlights the blocked opening corridor in red (`rgba(255, 51, 102, 0.40)` with `#ff3366` border), and turns the selection/hover halo red.
    - When dragging an LED with $<5\text{mm}$ channel clearance, displays a real-time `⚠️ 5mm Clearance` warning badge directly above the LED.
  - Updated `clampLedNoCollarOverlap` and `relaxLedCollarOverlaps` to maintain both the $18.6\text{mm}$ channel opening corridor and $10.0\text{mm}$ bridge buffers.
- **Python Compiler & Multi-Material 3D Verification:**
  - Updated `scripts/compile_clean_tpu_panel.py` PBD relaxation solver with $5.0\text{mm}$ opening corridor and $10.0\text{mm}$ bridge buffers.
  - Verified compilation of 75-LED front and back panels with 5-part multi-material inlays in 8.68s.

### 2026-10-08 21:05 - Proportional LED Pill Shadows & TPU Collar Scaling for Medium/Small Sizes
- **Proportional Physical Scale Factor (`ppm`):**
  - Updated `renderBulb` in `simulator/app.js` to compute the pixels-per-millimeter scale factor against the active plate dimension (`selectedPlateWidthMm`: 165.1mm Small, 203.2mm Medium, 254.0mm Large) and chest graphic bounds (`gb.normW * s.width`), rather than assuming a rigid garment width.
- **Lowered Rigid Floor Minimums:**
  - TPU Outer Collar clamp lowered from $15 \times 9\text{px}$ to $6.0 \times 4.0\text{px}$.
  - TPU Inner Pocket clamp lowered from $11 \times 5.5\text{px}$ to $4.5 \times 2.5\text{px}$.
  - TPU Snap Lip clamp lowered from $16 \times 10\text{px}$ to $7.0 \times 4.8\text{px}$.
  - Optical Window clamp lowered from $4.5\text{px}$ to $2.5\text{px}$.
  - HTV Vinyl Pill cutout clamp lowered from $12 \times 6\text{px}$ to $4.5 \times 2.4\text{px}$.
  - Resin Pebble LED clamp lowered from $8 \times 5.5\text{px}$ to $3.2 \times 2.4\text{px}$.
- **Subtle Visual Styling:**
  - Softened TPU collar drop-shadow opacity from `0.50` to `0.32` and dashed lip guide line from `0.18` to `0.12` alpha, rendering an elegant 3D chassis bevel that preserves full artwork visibility on Small and Medium size plates.

### 2026-10-08 20:58 - Fix LED Distribution on Character Artwork (Re-distribute & Presets)
- **Eliminated Double-Transform & Off-Graphic Displacement:**
  - Fixed offscreen canvas rasterization in `scatterLedsOnGraphic`, `sampleColorAtNorm`, `sampleColorAtNormCoord`, and `resampleAllLedColors`: replaced nested `drawPetesDragon` calls that were double-applying chest bounding box offsets (`gb.normX`, `gb.normY`) with direct 1:1 image rasterization.
  - Removed unconstrained `relaxLedCollarOverlaps(newLeds, 40)` from `scatterLedsOnGraphic`: Farthest Point Sampling (FPS) already guarantees maximal inter-bulb Euclidean spacing while strictly confining 100% of selected LEDs to valid foreground graphic pixels.
- **Explicit SVG Natural Dimensions:**
  - Added explicit pixel `width` and `height` attributes (`800x600` and `600x850`) to all vector files in `assets/cricut_svg/`, preventing `naturalWidth = 0` fallback issues in browser `Image` objects.
- **Regenerated 7-Float Preset Files:**
  - Cleaned and updated all official float presets in `presets/` (`casey_jr_train.json`, `title_drum.json`, `spinning_turtle.json`, `spinning_snail.json`, `cinderellas_coach.json`, `petes_dragon.json`, `petes_dragon_chris.json`):
  - Fixed the 18 stray LEDs in Casey Jr. (previously down at `y = 0.88` under bib) by redistributing all 100 LEDs cleanly across the locomotive body (`y <= 0.55`).
  - Cleared stray margin LEDs across all other float presets, ensuring both initial load and manual re-distribution keep all LEDs 100% on the graphic.

### 2026-10-08 20:34 - Nearby Neighbor LED Ordering, Lateral Exit Portal, and 50–100 LED Slider
- **Nearby Neighbor LED Progression (Default):**
  - Implemented consecutive neighbor-to-neighbor traversal starting at the bottom entrance portal and terminating at the lower-right lateral exit portal.
  - Added a 2-opt uncrossing pass (`doLineSegmentsIntersect`) to eliminate criss-crossing wire segments while preserving designated entrance and exit nodes.
  - Added a selectable toggle in the Layout tab between `[ 🔗 Nearby (Default) ]` and `[ 🔀 Wide Spacing ]` (~6.8 cm jump routing).
- **Lateral Wire Exit Portal & Strain Relief:**
  - Added lower-right lateral wire exit portal ($5.5\text{mm} \times 3.5\text{mm}$ parting line U-notch) matching the bottom entrance portal.
  - Integrated matching internal floor zip-tie strain relief bridge ($2.0\text{mm}$ walls, $2.8\text{mm}$ high tunnel, $4.5\text{mm}$ bridge height, wire saddle cradle, and triangular side gussets).
  - Added matching wire portal clearance on the 2.0mm rear protective lid assembly.
  - Rendered green `⚡ IN (P1)` and red `OUT ➔` visual badges with dotted leader wires to the first and last LEDs on the 2D simulator canvas.
- **50 to 100 LED Count Slider & Manual Re-distribute Button:**
  - Added fine-grained `#ledCountSlider` (50–100, step 1) with real-time target count display.
  - Strictly decoupled slider movement from redistribution so moving the slider updates the target readout without moving placed LEDs.
  - Added adjacent `[ 🔄 Re-distribute ]` button (`#redistributeLedsBtn`) to manually scatter the chosen LED count across the active graphic and re-route with the active sequence mode.
- **Dual-Plate 3D Compilation:** Compiled front and back plates in 8.98s; verified watertight geometry and updated `3d_panels/tpu_panel_specs.json`.

### Entry: Multi-Density (60, 100, 144 LEDs/3.2ft) Strip Modes, Flush Placement & Pitch Matching Presets
* **Date:** 2026-10-08 (Imagineering Session - LED Strip Density & Grid Pitch Matching)
* **Milestone:** Milestone 3 & 4 - Simulator UX Architecture & Physical Lighting Modeling
* **Status:** Complete & Verified (`simulator/index.html`, `simulator/app.js`, `SIMULATOR_USER_GUIDE.md`, `PROJECT_PROGRESS.md`).
* **Implementation Details:**
  1. **Selectable Strip Densities (60, 100, 144 LEDs per 3.2ft / 1m):**
     - Integrated 3-button density selector (`#btfDensity60Btn`, `#btfDensity100Btn`, `#btfDensity144Btn`) with dynamic badges (`#btfLinearPitchBadge`, `#btfStripDensityBadge`).
     - **60 LEDs/3.2ft:** Linear LED pitch $P = 1000 / 60 \approx 16.6667\text{ mm}$ (~0.656").
     - **100 LEDs/3.2ft:** Linear LED pitch $P = 1000 / 100 = 10.0000\text{ mm}$ (~0.394"), identically matching the 10mm silicone strip width.
     - **144 LEDs/3.2ft:** Linear LED pitch $P = 1000 / 144 \approx 6.9444\text{ mm}$ (~0.273"), high-definition silhouette rendering.
     - Strip matrix generator dynamically calculates solder cut marks, total strip length ($L = N_{\text{LED}} \times P$), and 5V current draw using the active density.
  2. **Continuous Spacing Slider with Live Gap Telemetry (`#btfSpacingSlider`):**
     - Expanded slider range from **6.9mm to 40.0mm** (0.1mm precision).
     - Live readout displays center-to-center pitch along with physical clearance between adjacent 10mm silicone sheaths: e.g. `10.0 mm (0.0mm Gap - Flush)` or `16.7 mm (Gap: 6.7mm)`.
  3. **Pitch Matching & Flush Alignment Presets:**
     - **`📐 Match LED Pitch` (`#btfMatchPitchBtn`):** Instantly sets strip-to-strip pitch to match the active linear LED pitch ($16.7\text{mm}$, $10.0\text{mm}$, or $6.9\text{mm}$), producing an isotropic square or hexagonal staggered matrix.
     - **`⚡ Flush (10mm)` (`#btfFlushBtn`):** Places strips directly side-by-side with 0.0mm gap ($10.0\text{mm}$ center-to-center pitch, matching the 10mm silicone sheathing width).
     - **`🎯 Auto-Fit ~100` (`#btfAutoFit100Btn`):** Numerical search algorithm calculates the optimal pitch to fit ~95–105 LEDs for the 2.0A battery envelope across any chosen density or plate size.
     - **`🌿 Relaxed (25mm)` (`#btfSparsePresetBtn`):** Quick-sets 25.0mm ribbon spacing for ultralight, low-current layouts.

### Entry: TPU Chassis 10.0mm (+1mm Wire Room), 1.8mm Sockets (50% Thicker), 3mm Clip Clearance, Tangent Alignment & Ø 3.4mm Default Windows
* **Date:** 2026-10-09 (Imagineering Session - Heavy-Duty TPU Mechanical Reinforcement & Optical Overhaul)
* **Milestone:** Milestone 5 - 3D Printed Armor & Multi-Material Hardware Engineering
* **Status:** Complete & Verified (`scripts/compile_clean_tpu_panel.py`, `simulator/index.html`, `simulator/app.js`, `simulator.py`, `3d_panels/tpu_panel_specs.json`, `SIMULATOR_USER_GUIDE.md`, `PROJECT_PROGRESS.md`).
* **Implementation Details:**
  1. **Chassis Perimeter Rim & Wire Clearance (+1.0mm Vertical Room):**
     - Perimeter rim height increased from $7.0\text{ mm}$ to **$8.0\text{ mm}$** ($Z = 2.0$ to $10.0\text{ mm}$, $2.5\text{ mm}$ wall width), raising overall plate thickness to **$10.0\text{ mm}$**.
     - Provides an extra $+1.0\text{ mm}$ of vertical wire room cavity under the 2.0mm rear lid (8.0mm open wire basin), allowing multi-conductor ribbon wire slack and folds to sit comfortably without binding.
     - Tray screw boss pillars automatically rise to $Z = 10.0\text{ mm}$ ($8.0\text{ mm}$ height) with pre-formed $1.6\text{ mm} \times 5.5\text{ mm}$ M2 pilot holes, meeting the 2.0mm rear lid perfectly flush.
     - Parting-line wire portal U-notch deepened to $3.5\text{ mm}$ tall $\times 5.5\text{ mm}$ wide.
  2. **LED Well Walls Thickened by 50% (1.8mm Walls) & 3.0mm Lateral Clip Clearance:**
     - Collar walls expanded from $1.2\text{ mm}$ to **$1.8\text{ mm}$** ($13.6\text{ mm} \times 8.6\text{ mm}$ outer well footprint; inner socket preserved at $10.0\text{ mm} \times 5.0\text{ mm}$), permanently eliminating thin wall fractures during running vibration.
     - Top retention lip extends $0.70\text{ mm}$ past the new wall face ($15.0\text{ mm} \times 10.0\text{ mm}$ outer lip footprint).
     - Enforced **$3.0\text{ mm}$ lateral clear buffer** on each side of every collar ($14.6\text{ mm}$ minimum center-to-center clearance) in both the Python compiler PBD solver and the browser collision relaxation engine. Ensures 3D-printed retention clips slide over from collar flanks with zero interference.
  3. **Selectable Channel Alignment (Horizontal vs Tangent to Wire):**
     - Added `#tpuOrientationSelectorRow` and 3D preview controls: `[ ↔️ Horizontal (Default) | 〰️ Tangent to Wire ]`.
     - In **Tangent to Wire** mode, each socket dynamically aligns with the chord tangent vector of the incoming and outgoing wire segments, minimizing sharp ribbon wire twists along organic character contours.
     - Propagated across 2D canvas preview, 3D WebGL inspector, and exported 3D STL/3MF models.
  4. **Heavy-Duty Strain Relief Bridge with Side Gussets & 2x Higher Tunnel:**
     - Bridge walls doubled in thickness from $1.0\text{ mm}$ to **$2.0\text{ mm}$**; bridge overall height raised to **$4.5\text{ mm}$**.
     - Under-tunnel height doubled from $1.4\text{ mm}$ to **$2.8\text{ mm}$** ($3.2\text{ mm}$ wide), allowing standard miniature zip-tie heads to pass through effortlessly.
     - Reinforced with solid **triangular side gusset buttresses** anchored into the floor beneath the wire path for maximum mechanical pull-out strength.
  5. **Selectable Optical Apertures (Ø 3.4mm Round Default):**
     - Added 3-way aperture switcher in toolbar and 3D modal: `[ 🔘 Ø 3.4mm Round (Default) | ⚪ Ø 3.0mm Round | 🔲 3×3mm Sq ]`.
     - Set **Ø 3.4mm Round** as the new factory default for maximum light transmission and wide-angle visibility through runner shirts.
     - Fully reflected in 2D canvas bloom, Three.js 3D texture projection, and watertight CSG cylinder cutter subtraction in Python Manifold3D compiler.

### Entry: Proportional Plate Sizing (Small/Medium/Large) & 10mm/5mm Strip LED Calibration
* **Date:** 2026-10-08 (Imagineering Session - Proportional Plate & Strip Calibration)
* **Milestone:** Milestone 3 & 4 - Simulator UX Architecture & Physical Lighting Modeling
* **Status:** Complete & Verified (`simulator/app.js`, `SIMULATOR_USER_GUIDE.md`, `PROJECT_PROGRESS.md`).
* **Implementation Details:**
  1. **Dynamic Plate Sizing & Bounds Scaling (`getGraphicChestBounds`):**
     - Coupled `selectedPlateSize` (`small`, `medium`, `large`) directly into the normalized graphic bounding box engine (`getGraphicChestBounds`).
     - **Small (~6.5" / 165mm):** Scales graphic by $0.8125\times$, generating fewer LEDs in BTF strip mode (~21–26 LEDs on Pete's Dragon).
     - **Medium (~8.0" / 203mm):** Standard reference chest scale ($1.000\times$, ~28–41 LEDs on Pete's Dragon).
     - **Large (~10.0" / 254mm):** Expands graphic across the upper chest ($1.250\times$), generating significantly more LEDs (~50–68 LEDs on Pete's Dragon) while strictly preserving clearance above the race bib ($y \le 0.555$).
     - Preserves exact aspect ratio: $\text{normW} = \text{normH} \times 1.25 \times \text{aspect}$.
  2. **Interactive Plate Size Selection Hook (`selectPlateSizeOption`):**
     - Clicking Small, Medium, or Large now instantly recomputes `computeBtfStripMatrix()` when strip preview is active, updating live telemetry and canvas overlay in real time.
     - Automatically re-scales any existing placed pebble LEDs to keep them anchored to their respective artwork facial and body features.
  3. **Strict 10mm Strip & 5mm LED Proportional Canvas Rendering (`drawBtfStripOverlay`):**
     - Calibrated silicone strip sheathing ribbon width to **strictly 10.0mm physical width** (`STRIP_TUBE_WIDTH_MM = 10.0`).
     - Scaled SMD 5050 packages to **strictly 5.0mm physical width** (`pkgSizePx = 5.0 * mmToPx`), taking up exactly 50% of the 10.0mm strip width with clean 2.5mm silicone margins on each side.
     - Centered circular phosphor emitter lens ($3.2\text{ mm}$ die diameter) with specular highlights.
     - **Canvas Zoom Lock (Eliminated Double Scaling):** Removed extraneous `* zoomScale` from `pkgSizePx` and glow radii. Since `ctx.scale(zoomScale, zoomScale)` already wraps the entire canvas render loop, eliminating the internal zoom multiplier guarantees that LED strips and chest artwork zoom in 100% 1:1 unison without any visual drift or ballooning.

### Entry: BTF-LIGHTING WS2812B (60 LED/m) IP67 Strip Preview with Staggered Rows & Columns
* **Date:** 2026-10-08 (Imagineering Session - LED Strip Alternative Architecture)
* **Milestone:** Milestone 3 & 4 - Simulator UX Architecture & Physical Lighting Modeling
* **Status:** Complete & Verified (`simulator/index.html`, `simulator/app.js`, `SIMULATOR_USER_GUIDE.md`, `PROJECT_PROGRESS.md`).
* **Implementation Details:**
  1. **Non-Destructive Interactive Preview Overlay:**
     - Added `#btfStripPreviewToggle` in Section 3c of the Layout tab. Toggling the preview renders realistic silicone strip ribbons and SMD 5050 packages without modifying the costume's placed pebble LEDs, wiring tour, 3D armor panels, or sequence cues.
     - Pebble wiring lines and slack tension arcs are cleanly suppressed during strip preview.
     - Switching back OFF immediately restores the exact baseline pebble layout.
  2. **Physical Strip Geometry & 50% Brick Stagger Engine:**
     - Calibrated for **BTF-LIGHTING WS2812B IP67 DC5V 60 LEDs/m** (fixed $16.6667\text{ mm}$ linear LED pitch along strips).
     - **Orientation:** Configurable between `↔️ Horizontal Rows` and `↕️ Vertical Columns`.
     - **50% Brick Stagger:** Shifts alternating rows or columns by half a pitch ($8.33\text{ mm}$), yielding an organic hexagonal/honeycomb LED distribution across the costume that eliminates Cartesian grid banding.
     - **Boundary Masking:** Supports dual modes: `✂️ Clip to Float Art` (masks to opaque artwork silhouette alpha $> 35$, color-sampling directly from character pixels) and `🔲 Chest Panel Grid` (fills upper chest trapezoid above race bib).
  3. **Live Hardware Telemetry & Safety Budget:**
     - Computes active LED count, contiguous strip cut count (individual segments $S_1, S_2\dots$ requiring solder jumpers), total linear strip length in meters and feet, and estimated 5V current draw (max full white at $50\text{ mA}$ vs. animated average at $20\text{ mA}$).
     - Features `🟢 100-LED Safe (~2.0A Bank)` vs `⚠️ Over Budget` status badge.
     - **Numerical Auto-Fit Preset (`🎯 Auto-Fit ~100 LEDs`):** Iteratively solves ribbon spacing in mm to target $\sim 95\text{--}105$ LEDs matching the portable power bank safety budget.
  4. **Photorealistic Canvas Visualization:**
     - Renders $12\text{ mm}$ wide IP67 translucent white silicone sheathing ribbons with sealed perimeter borders, copper solder cut tick marks, segment badges (`S1`, `S2`...), square SMD 5050 bodies, circular phosphor emitter lenses with specular highlights, and breathing radial bloom glow.
  5. **Seamless Preset & Artwork Integration:**
     - Hooked into `applyProfileData`, `loadGraphicPreset`, and `artworkUploadInput` so switching floats or uploading custom art automatically re-samples the strip matrix when preview is active.
  6. **Layout Promotion ("Apply Strip Layout"):**
     - Clicking `✅ Apply Strip Layout as Active LEDs` promotes the generated matrix to active costume LEDs upon confirmation, registered in `Ctrl+Z` undo history.

### Entry: Float 4 Spinning Snail Asset Processing (Transparent Background & 5-Color 3D Printable Alternating Stripes)
* **Date:** 2026-10-08 (Imagineering Session - Float 4 Snail Asset Processing)
* **Milestone:** Milestone 5 - 3D Printed Armor & Cricut Vinyl Production Pipeline
* **Status:** Complete & Verified (`assets/snail2.png`, `scripts/process_snail2.py`, `PROJECT_PROGRESS.md`, `SIMULATOR_USER_GUIDE.md`).
* **Implementation Details:**
  1. **Background Removal & Alpha Transparency:**
     - Fully isolated the low-poly 3D spinning snail float from `assets/snail2.png`.
     - Completely eliminated all background elements (dark night sky, spectator crowd silhouettes, road/curb ground, and streetlamp fixtures at top-right).
     - Produced a pristine transparent PNG with 79.3% alpha-transparent pixels (`RGBA [0, 0, 0, 0]`) and crisp edges.
  2. **Harmonized 5-Color Multi-Material Filament Palette:**
     - Strictly restricted every foreground pixel (15,314 px) to the 5 official multi-material 3D printing filaments defined in `FLOAT_STL_COLOR_CONFIG['spinning_snail']`:
       - **Black:** `#11161d` (RGB `[17, 22, 29]`) — Divider stripes & separator bands (4,451 px / 29.1%)
       - **Red:** `#ef4444` (RGB `[239, 68, 68]`) — Snail head, neck, underbelly, and foot (3,302 px / 21.6%)
       - **Gold:** `#facc15` (RGB `[250, 204, 21]`) — Antennae stalks, eye diamond, shell outer rim, and spiral divider track with center curl (3,125 px / 20.4%)
       - **Green:** `#10b981` (RGB `[16, 185, 129]`) — Alternating green radial stripes (2,239 px / 14.6%)
       - **Blue:** `#2563eb` (RGB `[37, 99, 235]`) — Alternating blue radial stripes (2,197 px / 14.3%)
  3. **Alternating Radial Stripe Sequence:**
     - Divided the shell disc and outer hood into 32 angular sectors ($11.25^\circ$ each, phase-aligned at $\theta_0 = 5.0^\circ$ around center `(153.5, 156.5)`), perfectly matching the underlying low-poly 3D mesh facets.
     - Implemented the repeating 4-phase sequence: `Green -> Black -> Blue -> Black -> Green -> Black -> Blue -> Black...` (8 complete cycles).
     - Ensured continuous radial spoke alignment between the outer hood tier and inner wheel.
  4. **Reproducible Pipeline (`scripts/process_snail2.py`):**
     - Authored a fully deterministic, self-contained Python script to reconstruct or regenerate the 5-color asset directly from raw uploads.

### Entry: 30s Fleet Show Timestamped Naming, Interactive Save Modal & Conflict Detection
* **Date:** 2026-10-08 (Imagineering Session - 30s Fleet Show Save Harmonization)
* **Milestone:** Milestone 3 & 4 - Simulator UX Architecture & Choreography Studio
* **Status:** Complete & Verified (`simulator/index.html`, `simulator/app.js`, `simulator.py`, `SIMULATOR_USER_GUIDE.md`, `PROJECT_PROGRESS.md`).
* **Implementation Details:**
  1. **Harmonized Fleet Show Nomenclature:**
     - The 30s Fleet Show Creator now follows the exact same timestamped convention as Floats and Parade Fleets: `<ShowName> <YYYY-MM-DD HH-mm>` (e.g., `Grand Parade 2026-10-08 14-20`, `Fleet Show 2026-10-08 14-20`).
     - `createNewFleetShow()` initializes fresh custom routines with default name `Fleet Show <YYYY-MM-DD HH-mm>` and timestamped ID.
  2. **Interactive Save Fleet Show Modal (`#saveFleetShowModal`):**
     - Clicking **`💾 Save Show`** (`#fleetSaveShowBtn`) launches a dedicated modal with:
       - Real-time overview metrics: total loop duration (e.g. `30.0s Loop`), configured choreography blocks, and ESP-NOW target broadcast indicator.
       - Live filename preview: `presets/fleet_shows/<clean_slug>.json`.
       - Duplicate file collision detection: checks server files via `/api/save_fleet_show`, reveals duplicate warning banner, red border styling, and an `⚠️ Overwrite Existing` button.
  3. **Backend Conflict Protection (`simulator.py`):**
     - `/api/save_fleet_show` now checks for existing files in `presets/fleet_shows/` and returns HTTP 409 Conflict when `overwrite: false`, safely preventing accidental file overwrites.
  4. **Seamless Integration with Parade Fleet Prerequisite Check:**
     - When saving the master parade fleet (`💾 Save Parade Fleet`), if the active show has unsaved edits (`isFleetShowDirty === true`), confirming the prompt cleanly opens `openSaveFleetShowModal()` with the timestamped naming and conflict safeguards before finalizing the master fleet save.

### Entry: Consolidated Single Save Locations, Strict Hierarchy & Two-Step Fleet Prerequisite Check
* **Date:** 2026-10-08 (Imagineering Session - Single Save Location & Fleet Hierarchy Consolidation)
* **Milestone:** Milestone 3 & 4 - Simulator UX Architecture, Preset Pipeline & Fleet Choreography Safety
* **Status:** Complete & Verified (`simulator/index.html`, `simulator/app.js`, `SIMULATOR_USER_GUIDE.md`, `PROJECT_PROGRESS.md`).
* **Implementation Details:**
  1. **Consolidated Single Save Locations (Zero Redundancy):**
     - **Floats (Layout Tab - Section 2):** Authoritative single place to save and export floats is Section 2 (`💾 Save & Export Floats`) via `#saveProfileBtn` (`💾 Save Float`), `#downloadProfileBtn` (`⬇ Export JSON`), `#exportCricutSvgBtn`, and `#importProfileBtn`.
     - **Clean Layout Section 3:** Removed duplicate `#saveLayoutBtn` ("Save Float") and `#exportLayoutJsonBtn` ("Export JSON") from Section 3 (`LED Layout & Wiring Route`); replaced with a clean, full-width `🔄 Reset Layout to Default` button.
     - **Parade Fleet (Fleet Tab - Section 2):** Authoritative single place to save and export the parade fleet is Section 2 (`7-Runner Baseline Presets & Master Fleet Suite`) via `#fleetSaveConfigBtn` (`💾 Save Parade Fleet`) and `#fleetExportBundleBtn` (`📦 Export Fleet Bundle`). Removed duplicate `#layoutExportAllFleetBtn` from Layout tab.
     - **30s Choreography Show (Fleet Tab - Section 1):** Dedicated `#fleetSaveShowBtn` (`💾 Save Show`) in Section 1 for authoring 30-second routines.
  2. **Two-Step Safety Prerequisite Check on `💾 Save Parade Fleet`:**
     - **Step 1 (Unsaved Canvas Float):** Checks `isSingleShirtDirty`. If true, prompts: *"Float X ([Name]) currently has unsaved layout or animation changes on the canvas. Floats must be saved before saving the Parade Fleet suite..."* -> triggers `openSavePresetModal()`.
     - **Step 2 (Unsaved Fleet Show):** Checks `isFleetShowDirty`. If true, prompts: *"Unsaved Fleet Show Detected! '[Show Name]' currently has unsaved choreography changes. The 30s Fleet Show must be saved before saving the Parade Fleet suite..."* -> triggers `saveActiveFleetShow()`.
     - Once both prerequisites pass, proceeds to `#saveFleetModal` with default title `Parade Fleet <YYYY-MM-DD HH-mm>`.
  3. **Fleet Show Dirty State Tracking (`isFleetShowDirty`):**
     - Automatically marked dirty on block duration adjustments (inputs), color dynamic changes (selects), block additions (`addFleetBlock`), reordering (`moveFleetBlock`), duplications (`duplicateFleetBlock`), deletions (`removeFleetBlock`), timeline dragging/resizing, and 30.0s time snaps (`snapFleetShowTo30s`).
     - Reset cleanly to `false` when `saveActiveFleetShow()` completes or a show is loaded via `loadFleetShow()`.
  4. **Nomenclature & Default Naming Harmonization:**
     - Float saving modal `#savePresetModal` dynamically formats base float name with current timestamp `<FloatName> <YYYY-MM-DD HH-mm>` (e.g. `The Drum 2026-10-08 14-10`), updating `profileNameInput`.
     - `#unsavedChangesModal` updated to Float nomenclature (`Unsaved Float Changes`, `Save Float Name:`, `💾 Save Float & Switch`).

### Entry: Nomenclature Refactoring, Timestamped Saving (Floats & Fleet), Unsaved Float Pre-Check & 3D Export Filenames
* **Date:** 2026-10-08 (Imagineering Session - Nomenclature Clarity & Timestamped Workflows)
* **Milestone:** Milestone 3 & 4 - Simulator UX Architecture, Preset Pipeline & 3D Manufacturing Export
* **Status:** Complete & Verified (`simulator/index.html`, `simulator/app.js`, `simulator.py`, `SIMULATOR_USER_GUIDE.md`, `PROJECT_PROGRESS.md`).
* **Implementation Details:**
  1. **Nomenclature Clarification:**
     - Layout tab updated from "Profiles / Presets" to **"Floats"** (`💾 Save Float`, Section 2 "Save & Export Floats", dropdown "Load Saved Float File").
     - Fleet tab updated from "Save Fleet Lineup" to **"💾 Save Parade Fleet"**.
  2. **Timestamped Default Naming:**
     - Float saving defaults dynamically to `<FloatName> <YYYY-MM-DD HH-mm>` (e.g., `Title Drum 2026-10-08 13-45`).
     - Parade Fleet saving defaults dynamically to `Parade Fleet <YYYY-MM-DD HH-mm>` (e.g., `Parade Fleet 2026-10-08 13-45`).
     - Standardized `getFormattedTimestamp(forFilename = false)` helper ensuring consistent format across titles and filenames.
  3. **Unsaved Float Pre-Check Before Fleet Save:**
     - Clicking `💾 Save Parade Fleet` actively verifies whether any float in the lineup has unsaved canvas edits (`isSingleShirtDirty === true`).
     - Prompts user to save that float first, cleanly continuing to the fleet save modal upon float save completion or aborting cleanly on cancel.
  4. **Parade Fleet Suite Saving & Backend Persistence:**
     - Interactive `#saveFleetModal` captures 7-runner lineup linking to saved float files, 30-second fleet choreography show blocks, and ESP-NOW sync parameters.
     - Backend `/api/save_fleet_config` persists to both `fleet_lineup.json` (active startup) and timestamped `presets/parade_fleet_*.json` with HTTP 409 duplicate file conflict protection.
  5. **Timestamped & Float-Named 3D File Exports:**
     - All 3D panel download buttons (`updateTpuDownloadButtons()`) dynamically incorporate the float name, variant, and timestamp into filenames:
       - Multi-Color Bundle ZIP: `<float>_<variant>_<timestamp>_multicolor_bundle.zip`
       - Bambu Studio Project (.3MF): `<float>_<variant>_<timestamp>_multicolor.3mf`
       - Rear Lid STL: `<float>_<variant>_<timestamp>_lid.stl`
       - Individual Inlays: `<float>_<variant>_<timestamp>_<color>.stl`
       - Monolithic STL: `<float>_<variant>_<timestamp>_monolithic.stl`

### Entry: Comprehensive Preset Saving (Canvas Coordinates, Count, Groups, Shows & Duplicate File Protection)
* **Date:** 2026-10-08 (Imagineering Session - Complete Preset State & Duplicate Protection)
* **Milestone:** Milestone 3 & 4 - Float Suite Management & Theatrical Show Sequencing
* **Status:** Complete & Verified (`simulator.py`, `simulator/index.html`, `simulator/app.js`, `SIMULATOR_USER_GUIDE.md`, `PROJECT_PROGRESS.md`).
* **Implementation Details:**
  - **Comprehensive Float State Serialization (`buildCompletePresetData`):**
    - Presets now save the exact normalized $(x, y)$ coordinates and physical count of all LEDs on the canvas (50, 75, 100, or custom).
    - Preserves all float-specific animation groups (wheel rotations, rim chases, fireworks starbursts, dragon crest pulses).
    - Preserves all theatrical show sequence cues (Parade Cue Director 90s loop duration and cues).
    - Preserves float identity (float ID 1–7, name, role, tag, race bib number, accent color).
    - Preserves 3D armor plate parameters (selected plate size, width in mm, and AMS filament color mappings).
  - **Interactive Save Costume Preset Modal (`#savePresetModal`):**
    - Both **`💾 Save`** (Section 2 - Sidebar) and **`💾 Save Preset`** (Section 3 - LED Layout & Wiring Route) launch a streamlined modal with real-time badges (Active Float, Canvas LED Count, Animation Group Count, Theatrical Cue Count).
    - Live filename preview (`Will save as: presets/<clean_name>.json`) updates dynamically as the user types.
  - **Duplicate File Checking & Rename Capability:**
    - Python backend (`/api/save_preset` in `simulator.py`) checks for filename collisions in `presets/` and returns HTTP 409 Conflict if a file already exists without `overwrite: true`.
    - Modal displays an alert banner (`⚠️ File Already Exists`) allowing the user to either edit/rename the preset or click `⚠️ Overwrite Existing` to replace the existing file on disk.
  - **Export JSON & Fleet Sync:**
    - Wired `exportLayoutJsonBtn` alongside `saveLayoutBtn` in Section 3 so users can directly download the complete float JSON bundle.
    - Synchronizes saved presets with the active runner card slot in the 7-Shirt Fleet Lineup and updates all dropdown selectors.

### Entry: Authentic Title Drum 5-Color Sampling & Resampling Fix for All Non-Dragon Floats
* **Date:** 2026-10-08 (Imagineering Session - Color Sampling Engine Correction)
* **Milestone:** Milestone 3 & 6 - Float Suite Integration & Color Fidelity Engine
* **Status:** Complete & Verified (`simulator/app.js`, `SIMULATOR_USER_GUIDE.md`, `PROJECT_PROGRESS.md`).
* **Implementation Details:**
  - **Identified Root Cause of Resampling Failure:**
    - `boostLedVibrancy()` previously used an explicit whitelist that included only `'custom_image'`, `'cinderellas_coach'`, `'carriage_nohorses'`, `'spinning_turtle'`, and `'spinning_snail'`, omitting `'title_drum'`.
    - When switching to the Title Drum and spreading or resampling LEDs, the function fell through into Pete's Dragon color mapping rules, forcing drum face black pixels (`#11161d`) and crimson red pixels (`#ef4444`) to map to Pete's Dragon Pink (`#ff19e6`), and gold pixels (`#facc15`) to orange (`#ff7800`).
  - **Generalization of `boostLedVibrancy()`:**
    - Restricted Pete's Dragon pink crest/spines and dragon green rules exclusively to `currentGraphicType === 'builtin_dragon' || currentGraphicType === 'petes_dragon'`.
    - All non-dragon floats now use authentic graphic color sampling.
  - **Authentic 5-Color Title Drum Palette Engine:**
    - **Marquee Gold (`#facc15` / `[250, 204, 21]`):** High-vibrancy parade golden amber (`{ r: 255, g: 204, b: 21 }`).
    - **Body & Streamers Red (`#ef4444` / `[239, 68, 68]`):** Radiant crimson red (`{ r: 239, g: 68, b: 68 }`).
    - **Lead Pennant Green (`#10b981` / `[16, 185, 129]`):** Electric flag green (`{ r: 16, g: 200, b: 129 }`).
    - **Flags & Pennants Blue (`#2563eb` / `[37, 99, 235]`):** Electric royal blue (`{ r: 37, g: 99, b: 255 }`).
    - **Drum Face & Chassis Black (`#11161d` / `[17, 22, 29]`):** Warm incandescent starlight white (`{ r: 255, g: 245, b: 220 }`), representing the illuminated vintage interior starlight bulbs of the Electrical Parade drum face rather than remaining unlit or falling back to Pete's Dragon pink/green.
  - **Harden Asynchronous Image Decode Checks:**
    - Added `activeImg && activeImg.naturalWidth > 0` validation guards across all sampling routines (`sampleColorAtNormCoord`, `sampleColorAtNorm`, `resampleAllLedColors`, `rearrangeRemainingLedsOnGraphic`, `scatterLedsOnGraphic`, `autoOutlineCurrentGraphic`, `sampleRemainingGraphicLeds`), preventing `NaN` dimensions during rapid float switching or canvas re-rendering.

### Entry: Layout Mode Assembly & Print Placement Guide (Faint Graphic, 3×3mm Square Windows & Compact Numbers Above)
* **Date:** 2026-10-08 (Imagineering Session - LED Placement & Print Reference Mode)
* **Milestone:** Milestone 6 - Wearable 3D Armor Fabrication, Physical Assembly Reference & Workshop Tooling
* **Status:** Complete & Verified (`simulator/index.html`, `simulator/app.js`, `SIMULATOR_USER_GUIDE.md`, `PROJECT_PROGRESS.md`).
* **Implementation Details:**
  - **Graphic View Mode Chooser in Layout Tab & Zoom Toolbar:**
    - Added dedicated Graphic View Mode toggle buttons in Layout Section 1 (`[🎨 Full Color]` vs. `[🖨️ Placement Guide]`) and quick toggle button in the Canvas Zoom Toolbar (`🖨️ Placement Guide`).
    - Works with all 7 float graphics (Casey Jr, Title Drum, Turtle, Snail, Coach, Dragon, Eagle) and custom uploads.
  - **Faint Graphic Watermark Rendering:**
    - Subdues active character artwork to a faint background opacity (default **22%**, customizable 10%–60% via live slider).
    - Ensures high visual contrast so float boundary context is visible while numbers and apertures remain crystal clear.
    - Also softens race bib to 20% opacity so lower chest LEDs and wiring traces are unobstructed.
  - **Physical 3×3 mm Square Windows:**
    - In Placement Guide mode, every LED is rendered as a clean, physical **3.0 mm × 3.0 mm square aperture** ($winSq = \max(5.0, 3.0 \times \text{ppm})$) with high-contrast perimeter borders and a 1px center registration dot, eliminating blinding light flares and bloom.
  - **Compact, Highly Legible Numbers Centered Right Above Windows:**
    - Positioned strand numbers ($0 \to N$) directly above each 3×3 mm square window ($y - winSq/2 - 2$) with `textAlign = 'center'` and `textBaseline = 'bottom'`.
    - Sized compactly at **bold 8px** with a 2.4px dark halo outline (`strokeText`), making numbers easy to read without colliding with adjacent LEDs or obscuring wire traces.
    - Highlighted LED #0 in green (`#00ff88` / `#16a34a`) for strand start and final LED in red (`#ff4d6d` / `#dc2626`) for strand termination.
  - **Theme Styles & 1-Click Print / PNG Export:**
    - Supported **👕 Dark Garment** and **📄 Light Paper** (ink-saving blueprint) modes.
    - Added a **`🖨️ Print / Save Placement Sheet`** button creating a print-ready document with float metadata, strand order, 3×3 mm aperture spec, and continuous wire trace legend.

### Entry: Title Drum Graphic Refinements: Accurate Wheel Centers, Cab Window Cutout, Streamer Flagpole & Gold Detailing
* **Date:** 2026-10-08 (Imagineering Session - Title Drum Artwork Calibration & Markup Implementation)
* **Milestone:** Milestone 6 - Wearable 3D Armor Multi-Material Artwork Assets & Float Lineup Presets
* **Status:** Complete & Verified (`assets/title_drum.png`, `simulator/assets/title_drum.png`, `scripts/process_title_drum.py`).
* **Implementation Details:**
  - **Accurate Wheel Placement & Ghost Wheel Removal:**
    - Re-anchored the two gold-outlined wheels to the exact physical wheel centers of the 3D model render:
      - Front Wheel: Center at $(x = 188, y = 715)$, $R = 70$, with gold outer rim ($R \in [61, 70]$) and gold hubcap ($R \le 16$).
      - Rear Wheel: Center at $(x = 968, y = 706)$, $R = 64$, with gold outer rim ($R \in [55, 64]$) and gold hubcap ($R \le 14$).
    - Re-calibrated ground plane and undercarriage cutoffs ($y > 785$ overall, $y > 715$ between axles), fully eliminating the black ghost circles that previously sat above the synthetic wheel placements.
  - **Cab Window Cutout (Red Square Markup):**
    - Removed interior red horizontal bar and vertical wall artifacts in the driver's cab window opening ($x \in [195, 290], y \in [260, 410]$), converting it into clean transparent negative space ($A = 0$) while preserving the surrounding structural gold pillars.
  - **Middle Streamer Brass Flagpole (Red Arrow Markup):**
    - Added a vertical gold flagpole column at $x = 833$ spanning from the blue pennant streamer tip ($y = 125$) down to the top of the drum marquee ring ($y = 265$), topped with a spherical gold finial ($r = 5$).
  - **Rear Detailing Gold Accents (Yellow Arrow Markups):**
    - Converted the red peak/notch on the rear fender arch shoulder ($x \in [925, 965], y \in [470, 520]$) into solid gold.
    - Converted the red base block at the bottom foot of the rear flagpole ($x \in [1005, 1030], y \in [540, 600]$) into solid gold.
  - **Verification:**
    - Crop dimensions: $1020 \times 789$ px.
    - Palette verification confirmed strictly 5 flat, unshaded colors + transparent background:
      - Transparent: 378,191 px (46.99%)
      - Gold: 166,218 px (20.65%)
      - Black: 162,131 px (20.15%)
      - Red: 79,727 px (9.91%)
      - Green: 13,516 px (1.68%)
      - Blue: 4,997 px (0.62%)
      - Zero unquantized colors or artifacts.

### Entry: Float 2 (The Title Drum) 5-Color Multi-Material Graphic Isolation & Default Float Integration
* **Date:** 2026-10-08 (Imagineering Session - Title Drum 5-Color Transparent Graphic Asset & Float Preset Integration)
* **Milestone:** Milestone 6 - Wearable 3D Armor Multi-Material Artwork Assets & Float Lineup Presets
* **Status:** Complete & Verified (`assets/title_drum.png`, `simulator/assets/title_drum.png`, `presets/title_drum.json`, `simulator/app.js`, `scripts/compile_clean_tpu_panel.py`).
* **Implementation Details:**
  - **Foreground & Background Isolation from `assets/Drum.png`:**
    - Performed high-precision background extraction on the 1200x900 3D render:
      - Flooded dark sky background (`gray < 28`, $S < 35$) from outer corners, ensuring drum face interior is 100% shielded.
      - Removed open air pocket between upper streamer ribbon arch and drum top (Component 2: 12,159 px), ribbon sliver (370 px), and driver's cab open window (Component 24: 1,440 px) as 100% transparent negative space ($A = 0$).
      - Flooded grey ground plane ($y \ge 650, 55 < gray < 120, S < 35$) and shaved bottom floor shadow between wheels ($y > 735$), preserving the full circular disks of all three wheels down to $y = 853$ (Front $R = 73$), $y = 831$ (Rear $R = 66$), and $y = 816$ (Mid $R = 46$).
  - **Flat 5-Color Unshaded Simplification (Bambu AMS 3D Multi-Material):**
    - Simplified all shading, specular highlights, and gradients into strictly 5 flat, unshaded colors:
      - **Black (`#11161d` / RGB `[17, 22, 29]`):** Chassis undercarriage, drum face backdrop, wheel tire bodies, cab interior frame.
      - **Gold (`#facc15` / RGB `[250, 204, 21]`):** Outer drum marquee ring, curved typography "MAIN STREET ELECTRICAL PARADE" (with letter counters intact), two wheel rims & center hubs, flagpoles & finials, square rear flag, cab canopy dome & scrollwork, front crest signboard.
      - **Red (`#ef4444` / RGB `[239, 68, 68]`):** Sculptural cab body panels, drum cradle arches, upper streamer ribbon.
      - **Blue (`#2563eb` / RGB `[37, 99, 235]`):** Streamer pennant tip (top arch).
      - **Green (`#10b981` / RGB `[16, 185, 129]`):** Lead forward flag on flagpole 1 ($x \approx 344$).
    - Zero intermediate antialiasing or gradient pixels—100% of non-transparent pixels belong strictly to one of the 5 colors.
  - **Wheel & Detailing Refinements (Visual Contrast & Feature Polish):**
    - **Reduced to Exactly 2 Wheels with Gold Outlines:** Eliminated the extra middle wheel ($x \approx 838$) to match the authentic 2-axle wagon profile with clear floor clearance between wheels. Outlined both the Front Wheel ($R = 73$) and Rear Wheel ($R = 66$) with crisp 8px gold rims and solid gold center hubcaps, establishing high-contrast visual pop against the black chassis floor.
    - **Cleaned Flagpoles (100% Solid Gold):** Cleared floating black noise specks to the right of the front pole ($x \approx 344$) and red border slivers along the rear pole ($x \approx 1018$). Flagpoles now stand as continuous, solid gold columns topped with gold spherical finials.
    - **Removed Extra Red Strip next to Square Gold Flag:** Eradicated the hanging ribbon tail/vertical red artifact ($x \in [800, 860], y \in [200, 450]$) between the drum ring and the square flag, opening up clean negative space. Set the square flag to 100% solid gold.
    - **Made Cab Canopy Roof Dome Gold:** Converted the black section on top of the main gold canopy near the green flag ($x \in [330, 425], y \in [150, 220]$) to solid gold, harmonizing the entire ornate cab roof structure.
  - **Repository & Tooling Synchronization:**
    - Saved transparent production asset to `assets/title_drum.png` (1020x827) and mirrored to `simulator/assets/title_drum.png`.
    - Created deterministic conversion pipeline in `scripts/process_title_drum.py`.
    - Updated `presets/title_drum.json` with `"graphicType": "title_drum"`, `"artwork_file": "assets/title_drum.png"`, and `stlColors` 5-color dictionary.
    - Updated `simulator/app.js` with `titleDrumImg` loading `assets/title_drum.png` as the default graphic for Float 2 (Title Drum).
    - Updated `scripts/compile_clean_tpu_panel.py` with `is_drum` check to default to the 5-color Title Drum AMS palette.
  - **Verification:**
    - Pixel palette analysis confirmed exactly 6 unique RGBA tuples: Transparent ($45.85\%$), Black ($22.68\%$), Gold ($17.59\%$), Red ($10.52\%$), Blue ($1.72\%$), Green ($1.65\%$).

### Entry: Deep Eyelet Gusset Wall Anchors & LED Well Overhang Removal (Physical Print Refinements)
* **Date:** 2026-10-07 (Imagineering Session - Eyelet Gusset Attachment Fix & Wire Notch Overhang Removal)
* **Milestone:** Milestone 6 - Wearable 3D Armor Fabrication & Mechanical Mating Refinements
* **Status:** Complete & Verified (`scripts/compile_clean_tpu_panel.py`, `3d_panels/`, `SIMULATOR_USER_GUIDE.md`, `PROJECT_PROGRESS.md`).
* **Implementation Details:**
  - **Deep Eyelet Gusset Wall Anchors (Eliminated Air Gaps at Dragon Feet):**
    - Analysis of physical prints showed several 45° eyelet braces (notably Tabs 8, 10, 11 around the dragon's feet) did not touch the outer rim wall due to perimeter curvature retreating up to 1.11mm behind the nominal tangent.
    - Redesigned the triangular gusset profile with a 4.5mm deep anchor extending in the negative normal direction into the 2.5mm solid rim wall (`x = -4.5mm` to `-1.0mm` at full 3.0mm height $Z = 4.0\text{ mm}$), then sloping at 45° down to the tab shoulder (`x = +2.0mm` at $Z = 7.0\text{ mm}$).
    - Integrated an automated Manifold3D inner basin cutter (`inner_plate_2d`) to cleanly shave any portion extending past the inner 2.5mm rim wall, guaranteeing zero intrusion into the tray cavity.
    - Boolean intersection analysis confirmed all 32 gussets (16 tabs x 2 shoulders) have solid intersection volume with the rim wall (5.3 to 16.5 mm³). The entire chassis is verified as 1 single continuous solid in Manifold3D (`decompose() len == 1`, `Error.NoError`).
  - **Removed 0.5mm LED Well Wire Notch Overhang:**
    - Eliminated `roofs_solid_m` over the wire pass-through notches.
    - Wire notches are now completely open, vertical 4.0mm drop-in channels from top to bottom ($Z = 1.0\text{ to }4.0\text{ mm}$ in raw space, $Z = 5.0\text{ to }8.0\text{ mm}$ in exported space).
    - Allows seed LED nodes and 3-strand enamel wires to seat 100% flat and flush against the pocket floor shelf with zero thumb binding, catching, or pinching.
    - Preserved external $0.70\text{ mm}$ top collar retention nubs (`nub_ring_2d`) on the outer collar perimeter for upcoming snap-on clip designs.
  - **Watertight Manifold3D Recompilation:**
    - Recompiled both Front Plate ($209.38\text{ mm} \times 186.66\text{ mm} \times 9.0\text{ mm}$) and Back Plate in 6.36 seconds.
    - Verified all STLs (`tpu_panel_front_chassis_black.stl`, `tpu_panel_back_chassis_black.stl`, lids, 3MF multi-material project, and ZIP bundles).

### Entry: Flush Lid Screw Boss Landings & Alignment Ridge Pillar Relief (Physical Test Print Fit Fix)
* **Date:** 2026-10-07 (Imagineering Session - Lid Screw Boss Flush Landing & Alignment Ridge Relief)
* **Milestone:** Milestone 6 - Wearable 3D Armor Fabrication & Mechanical Mating Refinements
* **Status:** Complete & Verified (`scripts/compile_clean_tpu_panel.py`, `3d_panels/`, `SIMULATOR_USER_GUIDE.md`, `PROJECT_PROGRESS.md`).
* **Implementation Details:**
  - **Eliminated Raised Inner Boss Pads (`lid_pads_m`):**
    - Analysis of physical test print photo revealed that 1.2mm raised cylindrical pads around the screw holes on the inner face of the lid collided with the top of the chassis tray boss pillars (which already rise to the rim top at $Z = 9.0\text{ mm}$).
    - Lowered all 8 screw cylinder top surfaces to be completely flush with the lid mating surface at $Z = 2.0\text{ mm}$ (as requested by the user).
  - **Added Alignment Ridge Relief Cutters (`boss_relief_m`):**
    - Added $5.6\text{ mm}$ diameter ($R = 2.8\text{ mm}$) cylindrical relief cutters centered at each of the 8 screw boss coordinates.
    - Clears away the $1.2\text{ mm}$ downward alignment ridge around each boss location, providing $0.3\text{ mm}$ radial clearance around the $5.0\text{ mm}$ diameter chassis pillars.
    - Guarantees the chassis boss pillars seat 100% flush and flat against the lid mating surface with zero interference.
  - **Preserved Outer Counterbores & Clearances:**
    - Maintained outer $\varnothing 3.8\text{ mm} \times 0.8\text{ mm}$ flush screw head counterbores on the shirt-facing surface ($Z = 0.0$ to $0.8\text{ mm}$).
    - Kept $\varnothing 2.0\text{ mm}$ clearance through-holes ($Z = 0.0$ to $2.0\text{ mm}$) for standard M2 self-tapping screws.
  - **Verification:**
    - Recompiled both Front and Back panels and lids via Manifold3D in 6.69s.
    - Verified all 8 screw locations in `tpu_panel_front_lid.stl` and `tpu_panel_back_lid.stl` have max $Z = 2.000\text{ mm}$ within $r \le 2.6\text{ mm}$ (zero raised pads).
    - Verified all 8 screw locations have $\ge 2.79\text{ mm}$ distance to the alignment ridge. Mesh is 100% watertight.

### Entry: Upgraded Multi-Material Inlays to 0.80mm (4 Solid Layers) for 100% Rich Color Opacity
* **Date:** 2026-10-07 (Imagineering Session - 0.80mm Inlay Thickness Implementation)
* **Milestone:** Milestone 6 - Wearable 3D Armor Fabrication & Multi-Material 3D Printing
* **Status:** Complete & Verified (`scripts/compile_clean_tpu_panel.py`, `3d_panels/`, `SIMULATOR_USER_GUIDE.md`, `PROJECT_PROGRESS.md`).
* **Implementation Details:**
  - **Implemented Recommendation A (0.80mm / 4 Solid Layers):**
    - Increased `COLOR_INLAY_THICK` from $0.60\text{ mm}$ (3 layers) to **$0.80\text{ mm}$ (4 solid layers @ 0.20mm)** across all color inlays (`yellow`, `green`, `magenta`, `white`, etc.).
    - Added support for `--inlay-thick <val>` CLI flag and `color_inlay_thick` JSON parameter in `scripts/compile_clean_tpu_panel.py`.
    - Inlays now extrude from $Z_{exported} = 8.20\text{ to }9.00\text{ mm}$.
    - Automatic boolean subtraction in the black chassis cuts $0.80\text{ mm}$ deep pockets, leaving a sturdy $1.20\text{ mm}$ of solid black backing floor.
  - **Zero Translucency & Solid Color Saturation:**
    - Cures the thin/mottled yellow belly issue observed in initial test prints. Even with a $0.28\text{ mm}$ first layer, at least 3 to 4 full solid passes of color print before any black chassis filament is deposited behind them.
    - Yellow volume increased from $1,128.7\text{ mm}^3$ to $1,504.9\text{ mm}^3$ (+33.3%).
  - **Watertight Manifold3D Verification:**
    - Recompiled both Front and Back plates in 6.69s.
    - Verified all STLs (`tpu_panel_front_color_*.stl`), multi-part 3MF project, and slicer ZIP bundle.
    - Documentation synchronized in `SIMULATOR_USER_GUIDE.md` and [`3d_panels/YELLOW_LAYER_LEVEL_PLAN.md`](3d_panels/YELLOW_LAYER_LEVEL_PLAN.md).

### Entry: 3D Armor Physical Fit Refinements: Parting-Line Wire Slot, Internal Floor Zip-Tie Bridge, 0.5mm Collar Lip, and Eyelet Tab Braces
* **Date:** 2026-10-07 (Imagineering Session - 3D Armor Mechanical Refinements from Physical Test Prints)
* **Milestone:** Milestone 6 - Wearable 3D Armor Fabrication & Mechanical Refinements
* **Status:** Complete & Verified (`scripts/compile_clean_tpu_panel.py`, `3d_panels/`, `SIMULATOR_USER_GUIDE.md`, `PROJECT_PROGRESS.md`).
* **Implementation Details:**
  - **Parting-Line Wire Exit Drop-In Slot (Image 1 Inspection):**
    - Moved the wire exit notch directly to the top edge where the outer rim wall meets the rear cover lid ($Z = 0.0$ to $3.0\text{ mm}$ in exported underside space).
    - Reduced Z height from 9.0mm to a clean 3.0mm drop-in U-slot ($5.5\text{ mm}$ wide $\times 3.0\text{ mm}$ tall in Z) matching the LED cable trunk thickness.
    - Wire harness lays directly into the slot without having to be threaded through an enclosed tunnel.
    - Lower 4.0mm of the rim wall ($Z = 3.0$ to $7.0\text{ mm}$) remains 100% solid, providing mechanical rigidity and moisture protection.
  - **Internal Strain Relief Bridge (90° Perpendicular Cross-Tunnel with Wire Saddle):**
    - Eliminated the two through-holes from the front plate floor, leaving the front shirt-facing graphic surface pristine, continuous, and puncture-free.
    - Reoriented the internal bridge 90° so its open under-tunnel passes along the $X$ axis ($10.0\text{ mm}$ long in X $\times 3.0\text{ mm}$ wide in Y $\times 1.4\text{ mm}$ tall in Z), completely perpendicular to the incoming $Y$-axis wire path.
    - Added a shallow $0.6\text{ mm}$ concave wire saddle on top of the bridge ($4.5\text{ mm}$ wide in X $\times 7.0\text{ mm}$ long in Y), centered in line with the outer wire notch.
    - Standard $2.5\text{ mm}$ micro nylon zip-tie slides easily under the bridge from left to right, loops up over the wire nestled in the top saddle, and cinches firmly down to anchor the cable trunk against race-day strides.
  - **0.5mm Collar Wire Notch Lip (Image 2 Inspection):**
    - Reduced the LED collar wire notch overhang from 2.0mm down to a sleek 0.5mm cantilever lip ($Y = 2.0$ down to $1.5\text{ mm}$) with a 45° chamfer support.
    - Opened up a generous $3.5\text{ mm}$ clear drop-in gap across the 4.0mm wire notch, allowing 3-conductor ribbon wire to seat effortlessly while the 0.5mm catch lip prevents vertical pop-out.
    - Retained the $0.70\text{ mm}$ collar perimeter retention beads for rigid snap caps.
  - **Dual 45° Triangular Eyelet Braces (Image 3 Inspection):**
    - Added dual 45° triangular gussets ($1.2\text{ mm}$ wide, rising $3.0\text{ mm}$ up the vertical outer rim wall from $Z = 2.0$ to $5.0\text{ mm}$) flanking both shoulders of all 16 outer tabs.
    - Fuses each tab directly into the outer chassis wall, preventing peel and tear-out when under tension or safety-pinned during the 10K.
    - Preserved full unobstructed clearance for the $\varnothing 2.7\text{ mm}$ center through-hole.
  - **Watertight Manifold3D Recompilation:**
    - Recompiled Front Plate ($205.85\text{ mm} \times 169.40\text{ mm} \times 9.0\text{ mm}$) and Back Plate in 8.34 seconds.
    - Generated pristine STLs (`tpu_panel_front_chassis_black.stl`, `tpu_panel_front_lid.stl`, color inlays, 3MF multi-material project, and ZIP bundle).

### Entry: High-Detail 1:1 Original Snail Artwork Recolored to 5-Color Multi-Material 3D Armor
* **Date:** 2026-10-06 (Imagineering Session - Float 04 Original Snail 1:1 Recoloring for 3D Printing)
* **Milestone:** Milestone 6 - Wearable 3D Armor Fabrication & Multi-Material 3D Printing
* **Status:** Complete & Verified (`assets/spinning_snail.png`, `assets/spinning_snail_simplified.png`, `assets/spinning_snail_5color_183.png`, `3d_panels/`, `PROJECT_PROGRESS.md`).
* **Implementation Details:**
  - **Zero Geometry Distortion / 100% Detail Preservation:**
    - Performed a direct, lossless 1:1 recoloring directly from the original authentic parade float picture (`assets/spinning_snail.png`), preserving all original pixel art, light bulb nodes, facial expressions, smile crease, neck folds, and spiral nuances without modifying any underlying drawing geometry.
    - Mapped every single pixel directly into the aligned 5-color palette:
      1. **Chassis Black (`#11161d`):** Inter-spoke dark shell framework, eye crease, smiling mouth line, and neck fold linework.
      2. **Race Red (`#ef4444`):** Snail head, face, cheeks, neck skin, and lower undulating foot/trail.
      3. **Parade Gold (`#facc15`):** Antennae stalks and bulbs ($Y < 52, X < 65$), outer shell rim, and central spiral whorl ($R_{norm} \le 0.22$).
      4. **Emerald Green (`#10b981`):** Green radial spokes and converted former gold radial lines.
      5. **Electric Blue (`#2563eb`):** Blue radial spokes and bulb highlights.
    - Saved native $183 \times 183$ recolored image (`assets/spinning_snail_5color_183.png`) and clean $4\times$ nearest-neighbor block-scaled ($732 \times 732$) version (`assets/spinning_snail_simplified.png`, `3d_panels/active_artwork.png`).
  - **Watertight Manifold3D Recompilation:**
    - Recompiled Front Plate ($205.85\text{ mm} \times 169.40\text{ mm} \times 9.0\text{ mm}$) and Back Plate in 8.02 seconds:
      - `tpu_panel_front_chassis_black.stl` (4.37 MB) with precision jigsaw pockets
      - `tpu_panel_front_color_red.stl` (245 KB, 2,512 vertices, 3,547.8 mm²)
      - `tpu_panel_front_color_gold.stl` (151 KB, 1,478 vertices, 5,548.2 mm²)
      - `tpu_panel_front_color_green.stl` (211 KB, 2,094 vertices, 2,957.9 mm²)
      - `tpu_panel_front_color_blue.stl` (222 KB, 2,368 vertices, 1,330.7 mm²)
      - `tpu_panel_front_lid.stl` (411 KB) with counterbored M2 screw clearance
      - `tpu_panel_front_multicolor.3mf` (1.13 MB) and `bundle.zip` (2.20 MB)

### Entry: 5-Color Multi-Material 3D Armor Tray & Snail (Float 04) STL Generation
* **Date:** 2026-10-06 (Imagineering Session - Float 04 Snail 5-Color Multi-Material 3D Fabrication)
* **Milestone:** Milestone 6 - Wearable 3D Armor Fabrication & Multi-Material 3D Printing
* **Status:** Complete & Verified (`assets/spinning_snail_simplified.png`, `simulator/assets/spinning_snail_simplified.png`, `presets/spinning_snail_simplified.json`, `scripts/compile_clean_tpu_panel.py`, `simulator/app.js`, `3d_panels/`, `SIMULATOR_USER_GUIDE.md`, `PROJECT_PROGRESS.md`).
* **Implementation Details:**
  - **High-Fidelity 5-Color Segmentation & Artwork Asset:**
    - Segmented and recolored `assets/spinning_snail_simplified.png` (732×732) to match exact runner race-day specifications:
      1. **Chassis & Shell Background (`#11161d`, 119,648 px):** Solid black shell disk background, dark structural borders, and neck linework folds.
      2. **Head, Neck, Face & Lower Foot/Trail (`#ef4444`, 47,536 px):** Race red cartoon body, face, smiling mouth, and crawling trail.
      3. **Antennae, Outer Rim & Center Spiral (`#facc15`, 28,225 px):** Parade gold eye stalks, round antenna bulbs, outer circular shell rim, and central spiral whorl.
      4. **Emerald Green Radial Stripes (`#10b981`, 18,959 px):** Half the alternating shell spokes, including conversion of previous gold radial lines.
      5. **Electric Blue Radial Stripes (`#2563eb`, 44,080 px):** The other half of the alternating shell spokes.
  - **Preset & Slicer Metadata Synchronization:**
    - Updated `presets/spinning_snail_simplified.json` with 5 AMS color slots: `black` (chassis), `red` (inlay), `gold` (inlay), `green` (inlay), `blue` (inlay).
    - Updated `FLOAT_STL_COLOR_CONFIG` in `simulator/app.js` and fallback mappings in `scripts/compile_clean_tpu_panel.py`.
  - **Manifold3D Watertight Compilation:**
    - Compiled Front Plate ($218.21\text{ mm} \times 178.70\text{ mm} \times 9.0\text{ mm}$) and Back Plate ($218.21\text{ mm} \times 178.70\text{ mm} \times 9.0\text{ mm}$) with:
      - Black chassis tray (`tpu_panel_front_chassis_black.stl`, 2.82 MB)
      - Red body inlay (`tpu_panel_front_color_red.stl`, 284 KB)
      - Gold antennae/spiral inlay (`tpu_panel_front_color_gold.stl`, 158 KB)
      - Green radial stripe inlay (`tpu_panel_front_color_green.stl`, 54 KB)
      - Blue radial stripe inlay (`tpu_panel_front_color_blue.stl`, 509 KB)
      - Monolithic single-color tray (`tpu_panel_front.stl`, 1.81 MB)
      - Rear cover lid with alignment ridge and counterbored M2 screw holes (`tpu_panel_front_lid.stl`, 416 KB)
      - Native multi-part 3MF package (`tpu_panel_front_multicolor.3mf`, 814 KB)
      - Complete Bambu Studio bundle ZIP (`tpu_panel_front_multicolor_bundle.zip`, 1.60 MB) with readme instructions.
    - Verified all meshes in Manifold3D with positive volumes and zero non-manifold defects.

### Entry: Restored Original Snail Artwork as Default & Fixed Layout Dropdown Switching
* **Date:** 2026-10-06 (Imagineering Session - Float 04 Snail Original Artwork Restoration)
* **Milestone:** Milestone 6 - Wearable 3D Armor Fabrication & Multi-Material 3D Printing
* **Status:** Complete & Verified (`presets/spinning_snail.json`, `assets/spinning_snail.png`, `3d_panels/active_artwork.png`, `simulator/app.js`, `simulator/index.html`, `PROJECT_PROGRESS.md`).
* **Implementation Details:**
  - **Reverted Default Snail Artwork to Original:**
    - Fully restored `presets/spinning_snail.json` to the original vibrant version with `graphicType: "spinning_snail"`.
    - Set `spinningSnailImg` and `floatArtworkImgs['spinning_snail']` back to `assets/spinning_snail.png`.
    - Restored `3d_panels/active_artwork.png` to `assets/spinning_snail.png`.
  - **Fixed Layout Dropdown Switching:**
    - Resolved the dropdown selection mismatch where choosing the original snail failed to trigger properly.
    - Updated `presetFileMap` and `getGraphicImgForType` so selecting `spinning_snail` cleanly loads `spinning_snail.json` and renders `assets/spinning_snail.png` on the canvas.
    - Maintained the simplified experiment as an optional choice (`spinning_snail_simplified`) under `Float 04: The Spinning Snail (Simplified 3D Print Test)`.

### Entry: Simplified 5-Color Snail (Float 04) Preset & Artwork for Bambu AMS Multi-Material 3D Printing
* **Date:** 2026-10-06 (Imagineering Session - Float 04 Snail 3D Print Color Segmentation)
* **Milestone:** Milestone 6 - Wearable 3D Armor Fabrication & Multi-Material 3D Printing
* **Status:** Complete & Verified (`assets/spinning_snail_simplified.png`, `presets/spinning_snail.json`, `presets/spinning_snail_simplified.json`, `presets/spinning_snail_original.json`, `scripts/compile_clean_tpu_panel.py`, `simulator/app.js`, `simulator/index.html`, `PROJECT_PROGRESS.md`).
* **Implementation Details:**
  - **Preserved Original Snail Artwork & Configuration:**
    - Archived exact original preset as `presets/spinning_snail_original.json`.
    - Preserved original artwork `assets/spinning_snail.png` and created `spinning_snail_original` dropdown option in the simulator so runners can toggle back to the original graphic at any time.
  - **Engineered Simplified 5-Color Snail Artwork (`assets/spinning_snail_simplified.png`):**
    - High-contrast, clean 5-color segmentation matching user specifications for Bambu AMS multi-material printing:
      1. **Body, Face, Lips, Antennae, and Foot:** Uniform vibrant pink (`#ec4899`, RGB `236, 72, 153`).
      2. **Shell Body:** One uniform emerald green (`#10b981`, RGB `16, 185, 129`).
      3. **Radial Shell Lines:** All radial spokes recolored to uniform electric blue (`#2563eb`, RGB `37, 99, 235`), replacing previous mixed green/blue/gold bulbs.
      4. **Shell Edge & Central Spiral:** Uniform parade gold (`#facc15`, RGB `250, 204, 21`), forming a solid continuous ribbon.
      5. **Neck Lines:** Chassis black linework (`#11161d`, RGB `17, 22, 29`) running along the neck contours for crisp mechanical definition.
    - Upscaled to 732×732 with nearest-neighbor interpolation to ensure sub-millimeter edge precision and zero color-bleeding during slicer tessellation.
  - **Configured Float 04 `stlColors` Metadata:**
    - Updated `presets/spinning_snail.json` and created `presets/spinning_snail_simplified.json` with the 5 AMS color slots: `black` (chassis/neck lines), `pink` (body/face/lips), `green` (shell body), `blue` (radial lines), and `gold` (shell edge and spiral).
    - Added fallback entries in `scripts/compile_clean_tpu_panel.py` and `simulator/app.js` (`FLOAT_STL_COLOR_CONFIG`).
  - **Watertight 3D Compilation Verified:**
    - Compiled `scripts/compile_clean_tpu_panel.py` on the simplified snail artwork:
      - Front Plate: 219.71mm × 140.93mm × 9.0mm, with 4 separate watertight color inlays (`color_pink.stl`, `color_green.stl`, `color_blue.stl`, `color_gold.stl`), black chassis tray (`tpu_panel_front_chassis_black.stl`), and matching 2mm rear cover lid (`tpu_panel_front_lid.stl`).
      - Back Plate: 204.96mm × 132.42mm × 9.0mm, with identical 5-color AMS part division and rear cover lid.
      - Generated native multi-color 3MF packages (`tpu_panel_front_multicolor.3mf` and `tpu_panel_back_multicolor.3mf`) ready for Bambu Studio / OrcaSlicer.

### Entry: Pure Concentric Eyelets Geometry Bugfix (Eliminated Bounding Box Corner Artifacts) & Dual-Anchor Design Confirmation
* **Date:** 2026-10-06 (Imagineering Session - Wearable Armor Eyelet Precision & Sandwiched Attachment)
* **Milestone:** Milestone 6 - Wearable 3D Armor Fabrication & Multi-Material 3D Printing
* **Status:** Complete & Verified (`scripts/compile_clean_tpu_panel.py`, `3d_panels/`, `SIMULATOR_USER_GUIDE.md`, `PROJECT_PROGRESS.md`).
* **Implementation Details:**
  - **Identified & Eliminated Pointy Bits on Eyelets:**
    - Root cause analysis: In `manifold3d`'s native nanobind implementation, `Manifold.cylinder()` contains an internal corner vertex artifact at $(R, R)$ in the first quadrant, extending vertices out to $\sqrt{2} \times R \approx 4.60\text{ mm}$ (beyond the target $3.25\text{ mm}$ outer radius) and resulting in a thin curved tangent "fin" or "horn" protruding from cylindrical tabs.
    - Engineered `make_clean_cylinder()` via `CrossSection.circle(radius, segments).extrude(height)`, which generates mathematically pure $360^\circ$ concentric circles with exact $R = 3.25\text{ mm}$ outer radius, $R = 1.25\text{ mm}$ inner through-hole, and zero corner artifacts.
    - Recompiled all Front and Back plates and verified: `Outward protruding vertices beyond r=3.25: 0`. All 16 eyelets on both trays and lids are now completely smooth and circular with zero pointy edges.
  - **Eyelets on Both Tray and Lid (Design Rationale Confirmed):**
    - Having 16 matching eyelets on BOTH the tray perimeter wall and the rear cover lid is intentional: when the lid is screwed down to the tray via the 8 M2 perimeter screws, the 16 lid eyelets align hole-for-hole with the tray eyelets to create a reinforced 4.0mm solid stack.
    - Runners can pass heavy-duty safety pins, tagging barbs, or miniature zip-ties through both the tray and lid simultaneously, firmly anchoring the entire costume armor to the running shirt/mesh vest so the mechanical load is shared and cannot pull the lid away from the tray during the 10K race.
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

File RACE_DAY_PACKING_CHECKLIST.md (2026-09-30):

# 🏰 MSEP Synchronized LED Costumes — Race Day Packing Checklist & Field Manual
### Walt Disney World 10K — The 7-Runner Family Expedition
**Engineered with Imagineering Precision by the 3 Brothers | Worn by the 7 Family Runners**  
*(2 Brothers, 1 Sister, 1 Brother-in-Law, 3 Sisters-in-Law)*

---

## 🎯 Mission Overview & Event Parameters
* **Event:** runDisney Walt Disney World 10K (Theme: *Main Street Electrical Parade*)
* **Course Distance:** 6.2 Miles (10.0 Kilometers) through Epcot and Disney resort roadways
* **Race Fleet:** 7 Synchronized Floats (Floats 1 through 7, 200 LEDs each: 100 Front + 100 Back duplicated)
* **Wireless Sync:** Peer-to-Peer ESP-NOW (2.4 GHz connectionless radio, no cell service or router needed)
* **Power Standard:** 5V USB Power Bank per runner (FastLED hardware power limited to 2000 mA / 2.0A max)
* **Corral Call Time:** 03:30 AM in Epcot outer parking lot corrals (Sunrise ~07:15 AM; Race starts ~05:00 AM in staggered waves)

---

## 📋 The Master Packing Checklist

### 1. ⚡ Microcontrollers & Electronics (Pre-Flashed & Tested)
- [ ] **7 Primary ESP32 Boards (Floats 1 to 7):**
  - [ ] 🚂 **Float 1 (Leader - The Train / Casey Jr.):** MAC pre-configured or flashed via `manifest_float1.json`.
  - [ ] 🥁 **Float 2 (Follower - The Title Drum):** Flashed via `manifest_float2.json`.
  - [ ] 🐢 **Float 3 (Follower - The Spinning Turtle):** Flashed via `manifest_float3.json`.
  - [ ] 🐌 **Float 4 (Follower - The Spinning Snail):** Flashed via `manifest_float4.json`.
  - [ ] 🩵 **Float 5 (Follower - Cinderella's Coach):** Flashed via `manifest_float5.json`.
  - [ ] 🐉 **Float 6 (Follower - Pete's Dragon):** Flashed via `manifest_float6.json`.
  - [ ] 🦅 **Float 7 (Follower - To Honor America):** Flashed via `manifest_float7.json`.
- [ ] **3 Spare / Backup ESP32 Boards:**
  - [ ] 1 Dedicated Spare Leader Board (Float 1).
  - [ ] 2 Generic Boards (Auto / Hotel Boot Selectable by holding BOOT for 5 seconds).
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

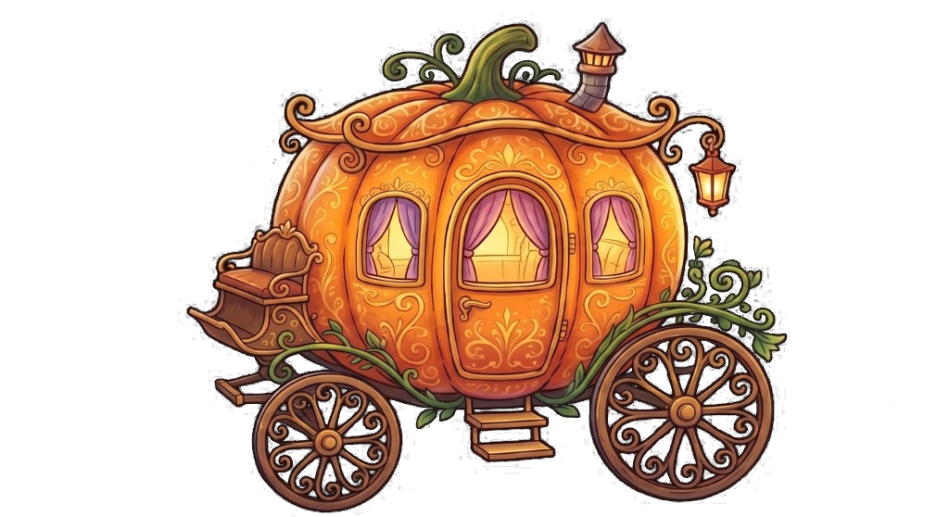
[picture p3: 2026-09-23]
assets/Carriage_nohorses.png

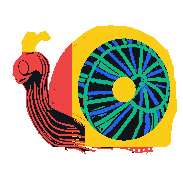
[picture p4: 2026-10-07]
assets/spinning_snail_5color_183.png

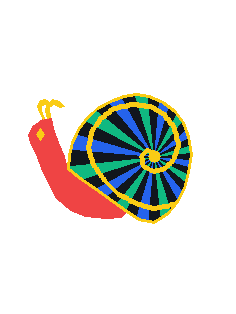
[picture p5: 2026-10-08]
assets/snail2.png

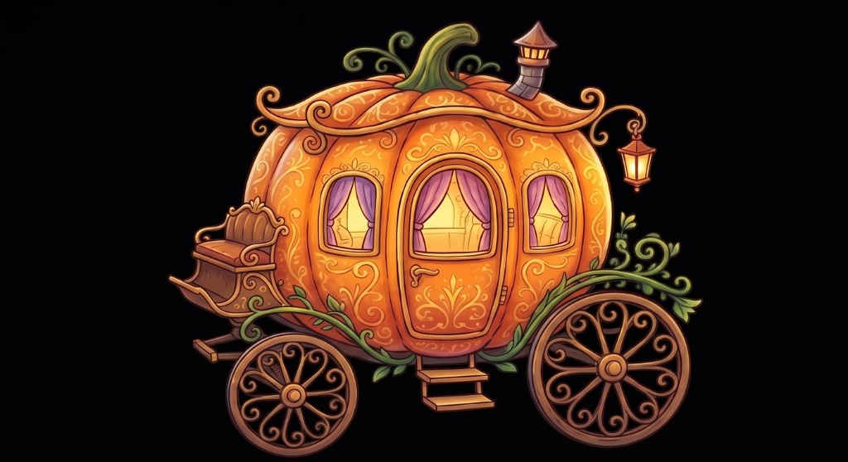
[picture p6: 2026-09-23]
assets/Carriage_nohorses.jpg

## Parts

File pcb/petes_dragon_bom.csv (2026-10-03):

Comment | Designator | Footprint | LCSC Part #
WS2812B-2020 Addressable RGB LED | LED1 LED2 LED3 LED4 LED5 LED6 LED7 LED8 LED9 LED10 LED11 LED12 LED13 LED14 LED15 LED16 LED17 LED18 LED19 LED20 LED21 LED22 LED23 LED24 LED25 LED26 LED27 LED28 LED29 LED30 LED31 LED32 LED33 LED34 LED35 LED36 LED37 LED38 LED39 LED40 LED41 LED42 LED43 LED44 LED45 LED46 LED47 LED48 LED49 LED50 LED51 LED52 LED53 LED54 LED55 LED56 LED57 LED58 LED59 LED60 LED61 LED62 LED63 LED64 LED65 LED66 LED67 LED68 LED69 LED70 LED71 LED72 LED73 LED74 LED75 LED76 LED77 LED78 LED79 LED80 LED81 LED82 LED83 LED84 LED85 LED86 LED87 LED88 LED89 LED90 LED91 LED92 LED93 LED94 LED95 LED96 LED97 LED98 LED99 LED100 | LED-SMD_4P-L2.0-W2.0-TL | C2843818
100nF (0.1uF) 50V 0402 Capacitor | C1 C2 C3 C4 C5 C6 C7 C8 C9 C10 C11 C12 C13 C14 C15 C16 C17 C18 C19 C20 C21 C22 C23 C24 C25 C26 C27 C28 C29 C30 C31 C32 C33 C34 C35 C36 C37 C38 C39 C40 C41 C42 C43 C44 C45 C46 C47 C48 C49 C50 C51 C52 C53 C54 C55 C56 C57 C58 C59 C60 C61 C62 C63 C64 C65 C66 C67 C68 C69 C70 C71 C72 C73 C74 C75 C76 C77 C78 C79 C80 C81 C82 C83 C84 C85 C86 C87 C88 C89 C90 C91 C92 C93 C94 C95 C96 C97 C98 C99 C100 | C0402 | C1525
JST-PH-3P SMT 2.0mm Header | J1 | JST_PH_S3B-PH-SM4-TB | C145946

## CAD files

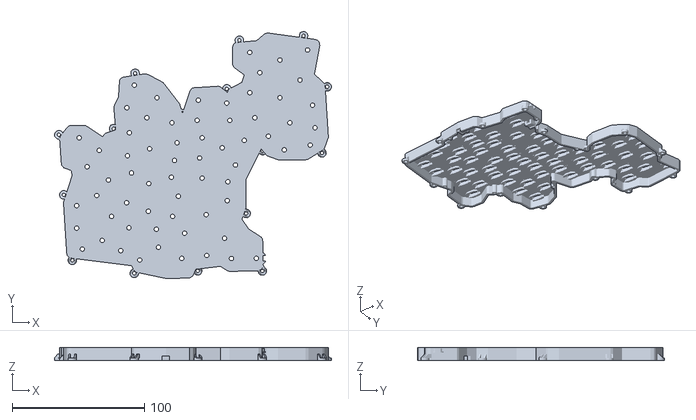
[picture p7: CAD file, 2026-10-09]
3d_panels/tpu_panel.stl
209.4 x 186.7 x 10.0

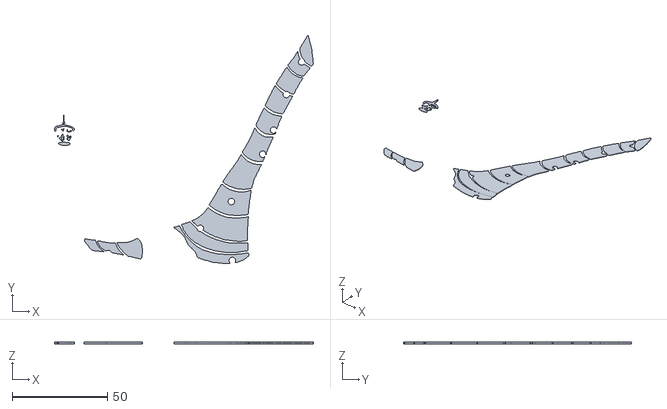
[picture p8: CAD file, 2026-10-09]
3d_panels/tpu_panel_front_color_yellow.stl
135.8 x 119.6 x 0.8

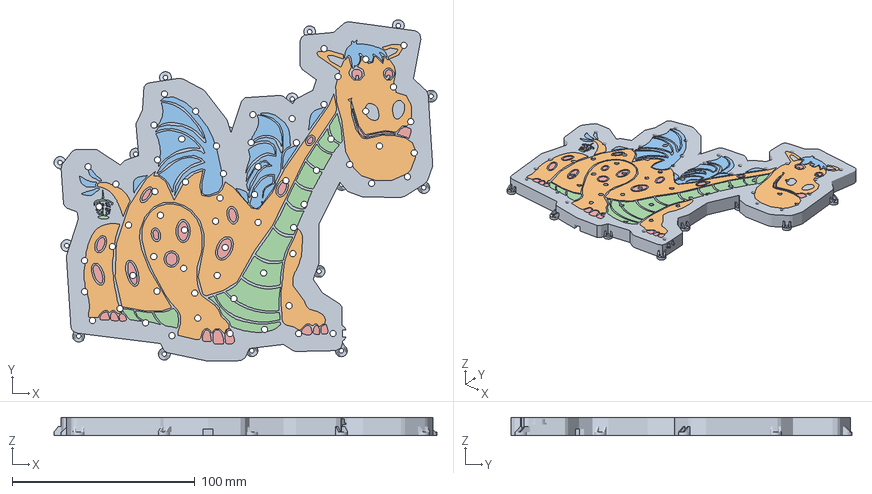
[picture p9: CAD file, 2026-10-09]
3d_panels/tpu_panel_back_multicolor.3mf
209.4 x 186.7 x 10.0 mm
1_Chassis_Black
2_Dragon_Body
3_Wings_and_Crest
4_Belly_and_Horns
5_Eyes_and_Teeth

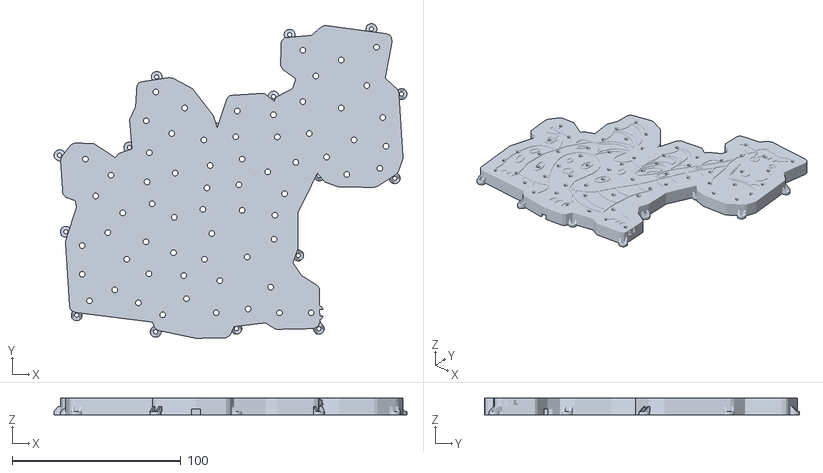
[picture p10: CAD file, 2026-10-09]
3d_panels/tpu_panel_front_chassis_black.stl
209.4 x 186.7 x 10.0

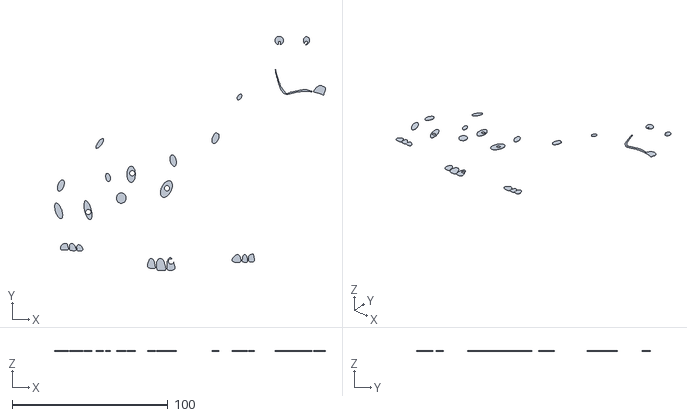
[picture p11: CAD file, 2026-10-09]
3d_panels/tpu_panel_back_color_white.stl
173.9 x 150.3 x 0.8

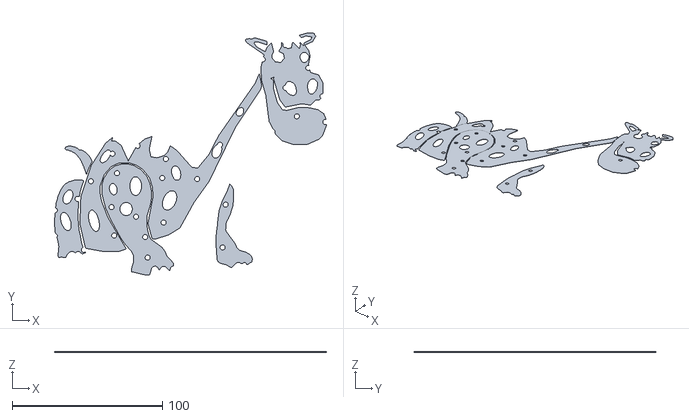
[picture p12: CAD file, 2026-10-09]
3d_panels/tpu_panel_back_color_green.stl
181.2 x 161.2 x 0.8

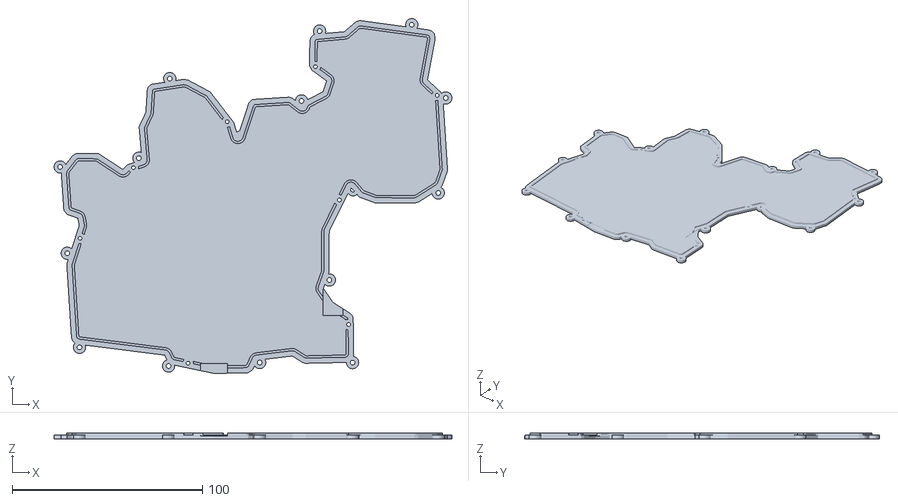
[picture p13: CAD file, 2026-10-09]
3d_panels/petes_dragon_tpu_panel_lid.stl
209.3 x 186.7 x 3.20

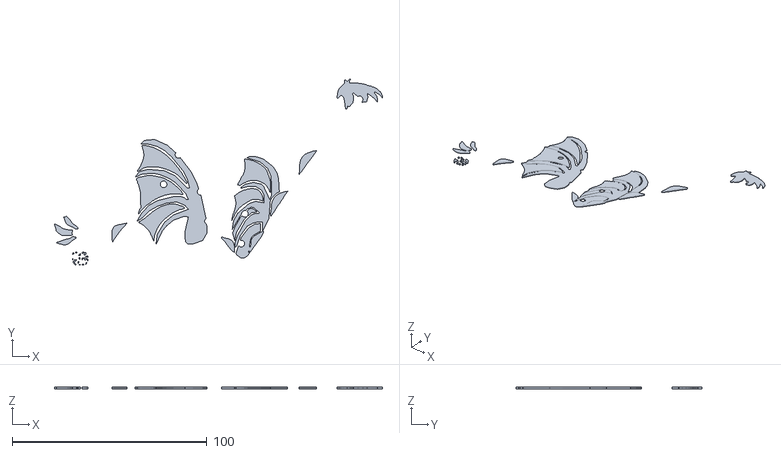
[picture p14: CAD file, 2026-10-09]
3d_panels/tpu_panel_back_color_magenta.stl
168.3 x 95.6 x 0.8

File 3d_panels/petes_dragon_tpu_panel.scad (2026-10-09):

// ============================================================================
// 🏰 Main Street Electrical Parade (WDW 10K) - 3D TPU Armor Plate (FRONT)
// Dimensions: 203.19mm x 185.62mm x 10.0mm
// Sized for Snapmaker U1 & Bambu Lab | Material: 95A TPU
// Aperture: Ø 3.4mm round optical apertures (Default) | Orientation: horizontal
// ============================================================================
$fn = 24;
front_thickness = 2.0;
total_thickness = 10.0;
contour_pts = [[100.91, 164.66], [106.61, 181.93], [108.52, 183.91], [128.0, 185.15], [129.52, 184.58], [134.78, 180.49], [135.38, 182.04], [136.53, 183.2], [145.68, 188.0], [147.57, 193.69], [139.86, 199.33], [138.57, 201.63], [138.76, 215.02], [139.45, 216.84], [140.93, 218.12], [156.91, 219.56], [162.87, 224.7], [164.98, 225.43], [201.3, 220.51], [203.16, 219.75], [204.22, 218.55], [204.69, 215.81], [200.65, 194.2], [207.74, 187.65], [208.71, 185.61], [211.21, 146.57], [208.35, 138.53], [206.9, 136.91], [196.01, 130.02], [193.87, 129.4], [173.05, 129.54], [164.7, 132.62], [160.39, 137.7], [148.96, 114.67], [148.94, 93.24], [145.87, 84.58], [150.91, 77.19], [160.33, 71.17], [161.53, 69.59], [161.85, 49.58], [160.97, 47.07], [158.32, 45.61], [136.42, 45.14], [134.91, 45.57], [129.55, 49.0], [110.99, 46.77], [108.66, 41.73], [106.18, 40.1], [88.33, 39.82], [65.83, 44.55], [64.09, 45.94], [62.42, 49.45], [16.84, 55.17], [14.71, 56.13], [13.75, 57.37], [13.35, 58.88], [10.9, 97.29], [17.45, 117.66], [16.73, 121.48], [11.1, 123.5], [9.37, 125.56], [8.02, 145.16], [8.62, 147.53], [13.75, 154.1], [14.97, 155.13], [16.5, 155.61], [27.63, 155.46], [40.43, 147.06], [42.69, 149.53], [50.42, 152.19], [48.93, 169.59], [52.51, 177.12], [53.29, 189.77], [54.52, 191.29], [55.93, 191.97], [72.32, 194.48], [74.74, 194.09], [86.31, 187.91], [98.77, 171.77], [100.91, 164.66]];
ordered_leds = [[100.36, 55.0], [82.73, 63.37], [68.62, 53.77], [54.23, 60.82], [40.2, 68.57], [47.25, 86.73], [25.18, 62.05], [20.87, 77.83], [20.87, 94.84], [36.04, 102.51], [44.92, 114.23], [28.84, 124.28], [22.78, 146.14], [37.94, 136.62], [60.72, 149.93], [73.98, 161.3], [58.82, 168.88], [64.53, 185.98], [81.6, 176.46], [92.95, 157.51], [96.76, 142.35], [94.86, 129.04], [76.03, 137.85], [59.31, 132.57], [62.34, 119.61], [58.68, 97.04], [60.44, 78.09], [81.1, 77.04], [75.04, 90.61], [75.46, 111.59], [92.46, 116.35], [97.75, 101.98], [115.73, 115.73], [113.83, 130.89], [115.73, 146.14], [111.93, 159.36], [112.84, 174.61], [134.35, 172.41], [151.77, 180.25], [159.39, 195.41], [151.77, 210.66], [174.56, 204.93], [195.43, 212.51], [189.72, 189.77], [174.56, 176.46], [182.1, 157.51], [199.17, 170.82], [201.07, 153.72], [197.41, 140.67], [177.8, 137.06], [165.81, 147.37], [155.58, 161.3], [136.68, 159.27], [147.61, 144.2], [130.9, 138.56], [140.91, 125.6], [135.2, 112.91], [134.71, 98.63], [118.77, 88.05], [93.38, 86.73], [102.47, 74.04], [119.26, 57.2], [137.88, 54.91], [156.71, 55.0], [132.66, 70.16]];
fastener_tabs = [[102.33, 164.19], [134.38, 183.16], [143.91, 219.9], [192.4, 223.23], [210.27, 184.7], [206.29, 134.75], [161.44, 136.45], [149.02, 88.97], [161.24, 45.51], [112.36, 45.58], [64.44, 43.74], [17.62, 53.56], [11.17, 103.03], [7.44, 148.44], [48.84, 153.04], [65.07, 194.89]];

linear_extrude(front_thickness) polygon(contour_pts);

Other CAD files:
3d_panels/tpu_panel_front_multicolor.3mf
3d_panels/tpu_panel_back.scad

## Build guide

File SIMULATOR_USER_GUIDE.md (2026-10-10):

# 🏰 Main Street Electrical Parade Costume Simulator
## Complete User Guide & Theatrical Lighting Manual

Welcome to the **Main Street Electrical Parade (MSEP) Costume Simulator** — a comprehensive browser-based theatrical lighting design console and hardware integration engine for synchronized, wearable addressable LED floats.

This guide walks you through every feature of the simulator, from placing and wiring your physical LEDs to orchestrating multi-layer 90-second parade show routines, live streaming to your ESP32, and compiling standalone firmware.

> ⚡ **Short on time?** Check out the 2-minute [**Simulator Quickstart Guide (TL;DR)**](SIMULATOR_QUICKSTART.md) for quick-reference shortcuts, clip dragging/trimming, and flasher workflows!

---

## Table of Contents
1. [Introduction & System Architecture](#1-introduction--system-architecture)
2. [Launching the Simulator](#2-launching-the-simulator)
3. [Canvas Navigation & Interactive Controls](#3-canvas-navigation--interactive-controls)
4. [Thoroughbred Workspace: 6 Task Tabs & Contextual Inspector Dock](#4-thoroughbred-workspace-6-task-tabs--contextual-inspector-dock)
5. [LED Placement, Inspection & Color Tuning](#5-led-placement-inspection--color-tuning)
6. [Multi-LED Selection & Animation Groups](#6-multi-led-selection--animation-groups)
7. [Physical Wiring Route Optimization & BTF-LIGHTING Strip Preview](#btf-lighting-ws2812b-60-ledm-strip-preview--staggered-matrix-engine)
8. [Artwork & Graphic Management](#8-artwork--graphic-management)
9. [Master Timeline Scrubber & Multi-Layer Tracks](#9-master-timeline-scrubber--multi-layer-tracks)
10. [Parade Cue Director (90-Second Theatrical Sequences)](#10-parade-cue-director-90-second-theatrical-sequences)
11. [Lighting Patterns & Effects Library](#11-lighting-patterns--effects-library)
12. [Profile Management, Saving & JSON Import/Export](#12-profile-management-saving--json-importexport)
13. [7-Shirt Fleet Show Creator, Preset Manager & Corral Radar](#13-7-shirt-fleet-show-creator--preset-manager)
14. [Hardware Integration: Live Wi-Fi Streaming, Standalone USB Flashing & Battery Power Budget](#14-hardware-integration-live-wi-fi-streaming-standalone-usb-flashing--battery-power-budget)
15. [ESP32 Firmware: Debounced Button Control, Fleet Routine Trigger & Early Stop](#15-esp32-firmware-debounced-button-control-fleet-routine-trigger--early-stop)
16. [3D-Printable Flexible Wearable TPU Panels (Snapmaker U1 / Bambu Lab / 95A TPU)](#16-3d-printable-flexible-wearable-tpu-panels-snapmaker-u1--bambu-lab--95a-tpu)
17. [Keyboard Shortcuts & Quick Reference Cheat Sheet](#17-keyboard-shortcuts--quick-reference-cheat-sheet)

---

## 1. Introduction & System Architecture

The simulator acts as a virtual workbench and lighting console for your WS2812B addressable LED costumes:
- **Design in the Browser:** Visually position up to 100 LEDs on any costume shirt graphic, match colors from the artwork pixels, organize LEDs into zone animation groups (e.g. carriage wheels, lanterns, dragon crest), and sequence rich multi-layered theatrical cues along a 90-second timeline.
- **Preview with 60 FPS Fidelity:** The canvas simulates the optical diffusion, bloom, and incandescent decay of vintage parade light bulbs.
- **Direct Hardware Link (Zero-Latency Wi-Fi UDP):** Stream the exact animation frames from the browser directly to an ESP32 over local Wi-Fi at 30 FPS.
- **Standalone FastLED Firmware:** Generate standalone C++ code and flash your ESP32 with one click. In the theme park, the ESP32 runs autonomously off a USB battery pack, controlling **200 LEDs (100 Front + 100 Back Duplicated)** with an onboard button to toggle between your individual float show and wireless ESP-NOW fleet synchronization.

```
┌────────────────────────────────────────────────────────┐
│                   BROWSER SIMULATOR                    │
│  - Multi-Layer Timeline & 90s Parade Cue Director     │
│  - Zone Groups (Wheels, Lanterns, Flame Crest)         │
│  - Continuous Wiring Route Optimizer                   │
│  - runDisney 10K Race Bib (#1952) & BibBoards Overlay  │
└──────────────────────────┬─────────────────────────────┘
                           │
             ┌─────────────┴─────────────┐
             ▼                           ▼
┌──────────────────────────┐   ┌──────────────────────────┐
│   LIVE WI-FI UDP STREAM  │   │  STANDALONE USB FLASH    │
│   (Port 4210 @ 30 FPS)   │   │  (PlatformIO / FastLED)  │
│   100 Front LEDs Live    │   │  200 LEDs (Front + Back) │
└────────────┬─────────────┘   └─────────────┬────────────┘
             │                               │
             └───────────────┬───────────────┘
                             ▼
               ┌───────────────────────────┐
               │    ESP32 COSTUME NODE     │
               │  - Mode 0: 90s Show Seq   │
               │  - Mode 1: ESP-NOW Sync   │
               │  - Output: 200 LEDs (G16) │
               │  - Button: GPIO 0 (BOOT)  │
               └───────────────────────────┘
```

---

## 2. Launching the Simulator

1. **Start the Local Server:**
   Open a terminal in the project directory and run:
   ```bash
   python simulator.py
   ```
   *(Or double-click `start_simulator.bat` on Windows or `start_simulator.command` on macOS).*
2. **Open Your Browser:**
   Navigate to:
   ```
   http://localhost:8000
   ```
3. The simulator will load with default artwork, pre-configured palettes, and an active transport control bar.

---

## 3. Canvas Navigation & Interactive Controls

The central workspace renders an interactive, hardware-accelerated preview of your shirt and LEDs.

### Pan & Zoom
- **Zoom In / Out:** Scroll your mouse wheel anywhere over the canvas. You can also press the `+` / `-` keys on your keyboard, or click the **Zoom In (+)** and **Zoom Out (-)** buttons in the top-left toolbar.
- **Reset Zoom:** Click the **⟲ 100%** button or press the `0` key to restore the default centered view.
- **Panning:**
  - **Right-Click Drag:** Hold down the right mouse button and drag across the canvas.
  - **Spacebar + Drag:** Hold the `Spacebar` (the cursor turns into a grab hand ✋) and drag with the left mouse button.
  - *Note:* A quick tap and release of the `Spacebar` (without dragging) toggles **Play / Pause** on the timeline!

### Universal Undo / Redo Engine (`Ctrl+Z` / `Ctrl+Y`)
- **50-Step Historical Memory Stack:** A non-destructive snapshot buffer records every garment modification across single LED drags, whole-group moves, 90° rotations, horizontal/vertical flips, spatial scaling, group pasting, group deletions, drawn paths, and automatic unassigned pool redistributions.
- **Toolbar Buttons:** Dedicated **`↩️ Undo`** and **`↪️ Redo`** buttons in the floating canvas toolbar dynamically display the next action to be reversed or restored in their hover tooltip.
- **Keyboard Shortcuts:**
  - **Undo:** `Ctrl + Z` (Windows/Linux) or `Cmd + Z` (macOS).
  - **Redo:** `Ctrl + Y` or `Ctrl + Shift + Z` (Windows/Linux) or `Cmd + Shift + Z` (macOS).
- **Smart Drag Batching:** Moving an LED or an entire group captures the baseline at click-down and commits a single clean undo step only on mouseup if actual movement took place, preventing accidental clicks from creating blank undo steps.

---

## 4. Thoroughbred Workspace: 6 Task Tabs & Contextual Inspector Dock

The simulator features a streamlined, modern workspace inspired by creative suites (After Effects, Figma, Blender), replacing long vertical scrolling with **6 task-oriented tabs** and an **intelligent contextual inspector dock**:

### The 6 Sidebar Tabs (2-Row Grid Layout)
The sidebar navigation is organized into a clean **2-row × 3-column grid** that guarantees all 6 task buttons fit comfortably inside the 410px sidebar without any button clipping or horizontal scrolling:
- **Row 1:** `🎨 Layout` | `✨ Ambient` | `👥 Groups`
- **Row 2:** `🎬 Float Show` | `🏃 Fleet` | `⚡ Deploy`

1. **🎨 Tab 1: Layout ("The Canvas Studio"):**
   - **🎭 Active Parade Float Banner & 7-Shirt Quick Switcher:** Unmistakable banner at the very top of the Layout tab showing exactly which float is being edited: Float number (#01 to #07), character name, parade role (`👑 Fleet Leader (Broadcast)` / `📡 Follower Float`), signature accent color, and lineup tag.
   - **⚡ 7-Button Float Switcher Grid:** Direct 1-click switcher buttons (`[ 1 ]` through `[ 7 ]`) featuring live glowing indicator dots in each float's signature color. Seamlessly switch between Casey Jr., Title Drum, Turtle, Snail, Cinderella's Coach, Pete's Dragon, and To Honor America with unsaved-change protection!
   - **🏷️ Top Navigation & Canvas Watermark Badge:** The top navigation tab updates dynamically (`👕 Single Shirt (#6 Elliott)`), while a translucent floating watermark badge in the top-left canvas corner keeps the active float number and name clearly visible while positioning LEDs.
   - **Float / Character Artwork Picker:** Unified dropdown allowing quick selection between the 7 official parade floats or uploading custom graphics (PNG/SVG/JPG), with a one-click `🔄 Restore Preset Defaults` button when custom artwork is active.
   - **runDisney 10K Race Bib (#1952):** Toggle overlay, height, and scale sliders to verify physical clearance.
   - **💾 Save & Export Custom Profiles:** Dedicated section for naming and saving custom design tweaks to browser cache, exporting standalone JSON costume files, or importing existing configurations.
    - **🎛️ LED Count Slider (50–100 LEDs) & Manual Re-distribute Button:**
      - **Target LED Count Slider (`50` to `100` LEDs):** Continuous slider allowing runners to select any target count from 50 to 100 LEDs. Moving the slider updates the target count badge without unexpectedly modifying or scattering placed LEDs.
      - **`[ 🔄 Re-distribute ]` Button:** Dedicated re-distribution button placed directly adjacent to the slider. Clicking it scatters the selected LED count across the active graphic with color matching and re-routes the strand.
      - **Wiring Sequence Selector (`[ 🔗 Nearby (Default) | 🔀 Wide Spacing ]`):**
        - **🔗 Nearby (Default):** Starts at an LED adjacent to the bottom entrance portal, visits consecutive near neighbors without skipping, eliminates link crossovers with 2-opt uncrossing, and terminates at an LED adjacent to the lower-right lateral wire exit portal.
        - **🔀 Wide Spacing:** Dispersed jump routing targeting ~6.8 cm inter-bulb spacing with slack optimization.
      - **Plate Sizing Selector (`Small ~6.5"` / `Medium ~8.0"` / `Large ~10.0"`):** Sizing directly sets the target width for the flexible TPU armor plate (Small = 165.1mm / 6.5", Medium = 203.2mm / 8.0", Large = 254.0mm / 10.0"). Both Front and Back plates dynamically scale to the selected width and recompile.
    - **🔌 LED Placement & Wiring Route:** Consolidated toolbar uniting all bulb generation and routing in one dedicated location:
      - `🌈 100 Scatter`: Evenly disperses 100 LEDs across the character with color matching.
      - `✨ 50 Auto-Outline`: Traces the outer silhouette contour with 50 LEDs.
      - `🎨 Sample`: Samples colors from the underlying artwork for each bulb.
      - `🔄 Fill Graphic with Remaining LEDs`: Redistributes non-grouped LEDs to fill open space without moving any grouped LEDs.
      - `🔌 Optimize Wiring Route`: Renumbers LEDs along the continuous physical route using the active sequence mode (`Nearby` or `Wide Spacing`).
      - `Show Wiring Trace` and `Show Bulb Numbers` inspection toggles. When active, displays green `⚡ IN (P1)` bottom entrance and red `OUT ➔` lateral exit badges with dotted leader wires to the first and last LEDs.
     - **🧵 Show Vinyl Pill Slots (6×3mm) & Tangent Pebble LEDs:** Toggles ultra-realistic fabrication view modeling the physical mesh pinnie vest. Renders the exact $6.0\,\text{mm} \times 3.0\,\text{mm}$ HTV vinyl pill cutout exposing the dark mesh weave, with tangent-aligned $4.0\,\text{mm} \times 3.0\,\text{mm}$ clear epoxy resin pebble LEDs oriented along the natural flow of the wire to minimize wire bending and solder fatigue.
     - **✂️ Export Cut SVG (with 6×3mm Pill Slots):** 1-Click button in Section 2 opening the **Cricut HTV Cut File Exporter Modal**. Allows instant download of the complete multi-layer artwork with pre-punched tangent pill slots, mat-by-mat SVGs for each color vinyl sheet with 4-corner heat press registration marks, or standalone cutout templates.
      - **🧵 Wire Tension & Physical Spacing Heatmap (in cm) & Single-LED Wire Isolation:** Real-time physical distance validation between consecutive LEDs ($18" \times 24"$ garment model) displayed in centimeters (`cm`) and meters (`m`). Color-codes segments as 🔵 Fold (`<4.5 cm`), 🟢 Optimal Slack (`4.5–8.5 cm`), 🟡 Snug (`8.5–9.2 cm`), or 🔴 Taut Alert (`>9.2 cm`), displays strand metrics (total length, average pitch, max span), and includes a `🔍 Inspect Max Span` tool to immediately locate tight spans. Selecting any single LED on canvas automatically isolates and displays only its incoming ($i-1 \rightarrow i$) and outgoing ($i \rightarrow i+1$) wire segments, eliminating visual clutter!
   - **🪞 Bilateral Symmetry & Mirror Tool:**
     - `Show Centerline Axis (x = 50%)`: Dashed purple/cyan vertical guide with illuminated badges for precise centering.
     - `Live Mirror Drag (Sync Paired LEDs)`: Dragging any bulb automatically mirrors the movement of its symmetrical partner across the centerline in real time.
     - `⇄ Mirror Left → Right` / `⇆ Mirror Right → Left`: 1-click reflection that clones coordinates, preserves animation groups, auto-samples colors, and commits to Undo history.
   - **Quick-Link to Groups:** Fast-jump button to the Groups Tab for drawing paths or stamping fireworks.

2. **✨ Tab 2: Ambient ("Garment Baseline Atmosphere"):**
   - **Baseline Concept Clarity:** Clarifies the core architecture: these patterns, speeds, and sparkle dynamics set the continuous default look for all LEDs not assigned to a specialized 👥 Animation Group (such as spinning wheels, eyes, scales, or fireworks). Specialized groups overlay their own animations on top of this background canvas.
   - **Real-Time Baseline Allocation Badge:** Displays live coverage metrics (e.g. `100 of 100 LEDs (100% Baseline)` or `64 of 100 LEDs (64% Baseline)` when groups exist).
   - **Baseline Lighting Pattern & Direction:** Select from continuous background patterns (Steady Sparkle, Color Match, Fire Breath, Traveling Wave, Marquee, Fireworks, Photo Mode, Comet, Scanner, Color Wipe, Pixie Dust, etc.) with selectable **Travel Direction** (`Forward ➡️ Head to Tail` or `Reverse ⬅️ Tail to Head`) matching the animation direction conventions of Tabs 3 and 4.
   - **Microcontroller Firmware Dynamics (ESP32 Flash):**
     - **Speed / Tempo BPM with Quick Chips:** Adjust continuous animation tempo via slider or one-touch speed chips: `🚶 90 BPM` (Parade Walk), `🏃 120 BPM` (MSEP Cadence), `⚡ 144 BPM` (Upbeat Swing), `🚀 180 BPM` (Theatrical Sprint).
     - **Sparkle Frequency with Quick Chips:** Regulate random starlight frequency from 0% to 10% via slider or instant chips: `🌑 0%` (Static/Clean), `✨ 0.5%` (Subtle Starlight), `🌟 1.5%` (Classic Main Street), `💫 3.5%` (Enchanted Swarm).
     - **Sparkle Appearance & Color Temperature:** Selectable filament starlight styles:
       - `✨ Warm 2700K Filament (Soft Golden White)`: Replicates vintage Edison filament light bulbs.
       - `💎 Diamond Cool White (Pure Starlight)`: High-energy crisp white starlight.
       - `🌟 Pixie Dust Golden Amber`: Rich fantasy amber-gold starlight.
     - **Ambient Color Palette Mode:** Switch between 4 palette engines:
       - `🎨 Sampled Artwork Colors`: Default multi-color palette sampled directly from character artwork pixels.
       - `🏰 Float Signature Theme Color`: Automatically tint the garment baseline to the float's official theme color (Casey Jr. Locomotive Red, Drum Gold, Turtle Shell Teal, Snail Magenta, Cinderella Sky Blue, Pete's Dragon Emerald, America Patriot Red/White/Blue).
       - `💡 Vintage Incandescent`: 2700K warm-white uniform wash replicating classical parade bulb strings.
       - `🎯 Custom Uniform Color`: User-selected uniform tint with live color picker.
     - **Hardware LED Output:** Hardware brightness slider strictly governed by FastLED hardware power limits (5V, 2000mA max).
     - *(Note: Legacy single-float green hue slider has been retired in favor of the full 4-mode color palette system; the 140° emerald hue is retained silently as a procedural fallback for Pete's Dragon).*
   - **Simulator Display Optics (Browser Canvas Only):** Visually separated preview control for **LED Bloom / Glow Radius** (8px to 40px) to simulate optical light diffusion on fabric without affecting compiled ESP32 firmware.

3. **👥 Tab 3: Groups ("Group Creation Hub & Manager"):**
   - **LED Allocation Overview Box:** Real-time visual progress bar tracking how many LEDs are assigned to animation groups versus unassigned baseline.
   - **Unified Group Creation Hub:** 3 dedicated creation modes with full 16+ effect parity and one-touch tempo quick chips (`🚶 90`, `🏃 120`, `⚡ 144`, `🚀 180 BPM`):
     - 📦 **From Selection:** Save or update groups directly from canvas marquee box selections with 12 Disney palette swatches plus a native **Custom Hex Color Picker**.
     - ✏️ **Click-to-Draw Path:** Sequentially place LEDs directly on the shirt with full effect selection, speed chips, and a checkable option to auto-rearrange remaining unassigned LEDs to fill the graphic.
     - 🎆 **Fireworks Stamper:** Radial starburst generator with serpentine wiring, radius scale, and color themes.
   - **Docked Group Inspector Parity:** Selecting any group or member LED exposes identical 16+ animation effects, one-touch tempo chips, directional controls, palette swatches, and a dedicated **Custom Hex Color Picker** directly in the docked Inspector card.
   - **Active Groups Browser:** Card list of all configured groups with instant selection, badge metrics, and deletion controls.

4. **🎬 Tab 4: Float Show ("Individual Float Routine & Cue Timeline"):**
   - **Individual Standby Routine Scope:** Explicitly scripts theatrical animation sequences for **this specific float only** (e.g., carriage wheels spinning, dragon breath bursts, locomotive chuffing) while running autonomously between fleet shows.
   - **Fleet Routine Priority & Override:** When a synchronized **Fleet Show** triggers (from Tab 5 or a physical ESP32 button press), the fleet routine temporarily overrides all 7 costumes. As soon as the fleet routine concludes, this float seamlessly resumes its individual show sequence or baseline pattern!
   - **Active Float Banner & Fleet Quick-Jump:** An illuminated header displays the active float currently being sequenced (with signature accent styling) and includes a one-click jump button (`🏃 Fleet Tab ➔`) to transition directly to the 7-shirt fleet coordinator.
   - **Parade Cue Director & Per-Cue Customization:**
     - **90-Second Sequence Loop:** Sequence ON/OFF toggle, loop duration input, and expanded library of 6 float-themed example routines.
     - **Per-Cue Direction Control:** Independent travel direction selector (`➡️ Forward` / `⬅️ Reverse`) per cue card, allowing traveling waves, sweeps, or comets to reverse on cue.
     - **One-Touch Quick Chips:** Instant duration chips (`5s`, `10s`, `15s`, `30s`) and tempo BPM chips (`90`, `120`, `144`, `180`) right inside each cue card.
   - **Active Cue List:** Clean, scrollable cue cards displaying start time, duration, target layer/group, effect, direction, BPM, and quick delete.
   - **Quick Cue Insertion:** `➕ Add Cue at Playhead`, `⚡ Auto-Schedule Bursts`.

5. **🏃 Tab 5: Fleet ("7-Shirt Fleet Lineup & Routine Director"):**
   - **👑 30s Choreographed Parade Routine:**
     - Fully customizable multi-phase fleet routine coordinating all 7 costumes.
     - One-shot activation (`[Space]` / `[F]` hotkeys or button) with automatic return to baseline float programs upon completion.
     - Early return / emergency cancel support.
   - **Corral Radar & Roll Call:** Live ping monitoring of all 7 ESP32 nodes in the starting corral.
   - **Battery Life & Power Budget Calculator:** Real-time milliamp consumption modeling for 10K race endurance on portable 2.0A USB banks.
   - **7 Runner Slot Cards (Bib #01 to #07):** Assign presets to each runner, view live LED counts and pattern pills.
   - **1-Click Bidirectional Editing:** Jump any runner's preset directly into the Single Shirt editor (`✏️ Edit in Single View`), or copy the active single-shirt editor design to any runner or all 7 runners (`📥 Assign Editor`).

6. **⚡ Tab 6: Deploy ("The Workshop & Hardware Hub"):**
   - **USB Standalone Flashing:** Auto-detected COM port, connection status badge, 1-Click Flash firmware, View/Copy C++ code modal.
   - **📡 Real-Time Wi-Fi Live Stream:** Stream live colors & animations directly to physical LEDs over Wi-Fi without flashing ROM. Wi-Fi credentials modal.
   - **Web Serial Flasher:** Quick launch button for zero-install browser-based flashing.

### 💡 Contextual Inspector Dock (Docked at Bottom of Sidebar)
Instead of taking up vertical space in the middle of your workflow:
- **Standby State (No Selection or Draw Mode):** When no bulbs are selected, or while actively drawing a path on the shirt (`✏️ Click-to-Draw`), the Inspector rests as a quiet, compact status chip (`👆 Click an LED or drag on canvas to inspect`). It stays collapsed during drawing so you can place sequential points on the garment without distracting UI jumps or unwanted dock expansions.
- **Active State (Selected LED or Group):** When 1 or more LEDs are selected (or when editing a saved group), the Inspector automatically expands with an illuminated gold accent border:
  - LED number stepper (`◀ Prev`, `Next ▶`, `⌖ Focus`).
  - Color preview swatch, Hex & RGB badges, and RGB sliders.
  - **🔄 LED Well & Channel Rotation Card:**
    - **Live Angle & Mode Badge:** Displays exact rotation in degrees (e.g. `45.0°`) and badge status (`[ 〰️ Tangent ]` or `[ 🔒 Custom XX° ]`).
    - **Continuous Rotation Slider ($0^\circ$ to $360^\circ$):** Smoothly scrub to rotate the selected LED(s) in real time on the canvas.
    - **`[ 〰️ Auto ]` Reset Button:** Clears manual angle override and restores the natural wire path tangent.
    - **Quick Angle Presets & Nudges:** Instant angle buttons (`0° Horiz`, `45°`, `90° Vert`, `135°`) plus `⟲ -15°` (`Shift+R`) and `⟳ +15°` (`R`) precision nudges.
    - **Visual Orientation Axis:** Selected LEDs display a directional green axis arrow showing the socket orientation in real time.
  - Quick Disney Palette Swatches (12 signature theme park colors).
  - Group Animation Effect creator (Zone Name, Effect Pattern, Speed BPM, Direction, Resting Baseline, and Firework Burst Radius slider).
  - One-click deselect button (`✖`).

### ⤢ Collapsible Master Timeline
- Click **`⤢ Minimize`** in the transport bar to collapse the multi-layer cue tracks into a slim transport bar, giving the canvas full vertical workspace.
- Click **`⤢ Expand`** to restore the full multi-layer cue tracks and ruler when arranging show sequences.

### 🛡️ Zero-Risk Rollback System
The pre-overhaul UI state is permanently tagged and archived:
- Git Tag: `v1.0-pre-ui-overhaul` (`git checkout v1.0-pre-ui-overhaul -- simulator/`)
- Backup Archive: `simulator/archive_v1/` containing exact copies of `index.html`, `style.css`, and `app.js`.

---

## 5. Multi-LED Selection, Group Creation Hub & Click-to-Draw Path Tool

To create localized zone animations (like carriage wheels spinning, lanterns pulsing, spinal ridges glowing, or radiating starburst fireworks), you can organize LEDs into **Animation Groups**.

### Selecting Multiple LEDs
1. **Marquee Box Select:**
   - Click the **⬚ Box Select** button in the top toolbar, then click and drag a rectangular bounding box across any area of the canvas.
   - *Quick Shortcut:* Hold down the `Shift` key and drag anywhere on the canvas to draw a selection box immediately!
2. **Select All:** Click the **All** button or press `Ctrl + A` (`Cmd + A` on Mac) to select all LEDs on the float.
3. **Clear Selection:** Click **Clear** or press `Escape` to deselect all LEDs.

---

### ➕ The Unified Group Creation Hub (`👥 Groups` Tab)

The Group Creation Hub provides 3 dedicated, purpose-built workflows under unified tabs:

#### 1. 📦 Mode 1: From Selection
- Select 2 or more LEDs using **⬚ Box Select** or `Shift + Click`.
- The Hub automatically displays the number of selected LEDs and their index range (e.g. `✨ 16 LEDs Selected · Indices: #12–27`).
- If the selection matches an existing group, fields automatically populate and the button reflects **`💾 Update Group "[Name]"`**.
- Otherwise, configure Group Name, Effect Pattern, Direction (➡️ Forward / ⬅️ Reverse), Speed (BPM), and Resting Baseline, then click **`💾 Save Selection as Group`**.

#### 2. ✏️ Mode 2: Click-to-Draw Sequential Path Tool
The **Click-to-Draw Path Tool** lets you place sequential LEDs one-by-one directly onto the shirt canvas by simply clicking where you want each light:
- **Activation:**
  - Click the **`[✏️ Draw Group]`** button in the top canvas toolbar, OR
  - Click **`[✏️ Start Drawing on Shirt]`** in the Group Creation Hub (Draw mode), OR
  - Switch to the Groups tab and click **`✏️ Click-to-Draw`**.
- **Distraction-Free Drawing Experience:**
  - While drawing points on the shirt, the docked Inspector is automatically held in collapsed standby (`dock-empty`). Placed points are tracked cleanly without triggering premature dock expansions, button shifts, or field flashing, keeping your view on the canvas completely unobstructed.
- **Visual In-Progress Guide:**
  - A prominent floating **Canvas Drawing Banner** appears above the shirt with an active pulse indicator and placed LED count.
  - A glowing gold dashed line connects your clicks in real time.
  - Each placed point is highlighted with a gold circular badge displaying its sequence step number (`1`, `2`, `3`...).
- **Contiguous LED Allocation Algorithm:**
  - Each click takes from the available costume LEDs while preserving the strict **100-LED invariant**.
  - LED indices are allocated contiguously (#24, #25, #26...) whenever possible. This ensures directional animations like **Chase**, **Write-On / Wipe**, and **Traveling Waves** flow smoothly in the exact chronological order of your clicks!
- **Color Auto-Sampling:**
  - Each placed point automatically samples the pixel color from the underlying character graphic (Pete's Dragon, Cinderella's Coach, or custom artwork).
- **Finishing & Saving with Auto-Rearrange:**
  - Press `Enter` on your keyboard, click **`✅ Done`** on the canvas floating banner, or click **`✅ Finish & Save`** in the sidebar.
  - The newly created group is saved, immediately selected, and opened in the editor for fine-tuning.
  - **Auto-Rearrange Option (Checkable):** By default, the `🔄 Auto-rearrange remaining LEDs` checkbox is enabled (available in both the Click-to-Draw panel and the canvas floating banner). When saved, all non-grouped LEDs are automatically redistributed across open spaces of the graphic using Farthest-Point Sampling. The existing grouped LEDs serve as fixed distance anchors so remaining lights never collide with or crowd your custom path.
- **Safe Cancellation:**
  - Press `Escape` or click **`❌ Cancel`** on the canvas banner to exit draw mode without saving. All LED positions are instantly restored to their exact pre-draw coordinates.
- **Manual "Fill Graphic with Remaining LEDs" Button (Layout Tab):**
  - Located on the Layout Tab (`🎨 Layout`) under both Shirt Artwork and LED Layout (`🔄 Fill Graphic with Remaining LEDs`).
  - At any time, clicking this button scans all currently assigned groups and evenly redistributes all remaining non-grouped LEDs across the open areas of the character graphic without modifying any grouped LEDs or changing total LED count (always 100). Perfect for refreshing the background layout if points ever become uneven or after editing groups!

#### 3. 🌟 Mode 3: Shape & Flourish Stamp Library
The **Stamp Library** combines our **Fireworks Starburst Generator** with a full suite of parametric geometric shape stamps:
- **Shape Selection Grid:**
  - 💥 **Fireworks Starburst:** Multi-ray radial explosion with serpentine wiring, customizable burst radius, uniform/custom ray colors, and timeline cue auto-scheduling.
  - ⭕ **Circle / Wheel:** Perfect for Cinderella's carriage wheels, Casey Jr.'s locomotive drivers, and turtle shell rings (configurable radius, LED count 4–30, and full $360^\circ$ vs. arc span).
  - 🌈 **Arch / Canopy:** Parabolic and catenary arches for carriage roofs, dragon brows, and turtle shell domes (upright vs. inverted curvature).
  - 🌊 **Wave / Serpentine:** Sine wave puffs for locomotive steam trails, Elliott's dragon fire breath, and water ripples (configurable amplitude, length, and 1–5 cycle count).
  - ⭐ **Star / Sparkle:** 4-point sparkles and 5-point starbursts for Disney starlight flourishes.
  - ▬ **Straight Line / Ruler:** Evenly-spaced horizontal, vertical, or diagonal line bars for marquee borders, flag stripes, and cowcatcher slats.
- **Position Placement Options:**
  - Quick Presets: `↖ Top-Left`, `↗ Top-Right`, `⏺ Center`.
  - Precision Sliders: Move X% and Move Y% sliders.
  - **`🎯 Click Canvas to Place`**: Click anywhere on the garment canvas to drop the stamp centroid $(\bar{x}, \bar{y})$ directly at your cursor location!
- **Automatic Budget & Unused Pool Management:**
  - Every stamped shape verifies available unassigned LEDs to enforce the **100-LED invariant**.
  - Automatically resamples underlying graphic pixel colors and redistributes remaining unassigned LEDs across open graphic space.
  - Fully integrated with the **Universal Undo / Redo Engine (`Ctrl+Z`)**.

#### 4. 🛠️ Mode 4: Group Transformations Suite & Clipboard (Copy, Paste, Rotate, Flip, Scale)
The Animation Groups editor includes full spatial transformations and cross-shirt group clipboard support:
- **📋 Copy & Paste Group (Within & Between Shirt Designs):**
  - Click **`📋 Copy`** on any group card or in the docked Inspector dock, or press `Ctrl + C` (`Cmd + C`).
  - Switch to any runner slot or shirt design (Float 1 through Float 7) and click **`📋 Paste Group`** (in the section header, Inspector, or press `Ctrl + V`).
  - **100-LED Unused Pool Budget Guard:** Pasted LEDs are automatically allocated from the target shirt's unused LED pool. If the target shirt has fewer unused LEDs available than required, a toast warning blocks the action to maintain our 100-LED invariant.
  - **Relative Coordinate Mapping & Artwork Color Sampling:** Member LEDs map relative to the target shirt's chest graphic area ($\text{relX}, \text{relY}$) and dynamically resample artwork pixel colors for a crisp visual match!
- **🔄 Rotate Group (90° Quick Action & Continuous Angle):**
  - Click **`🔄 Rotate 90°`** (or press `Ctrl + R`), or use card action **`🔄 90°`** to rotate member LEDs around the group's centroid $(\bar{x}, \bar{y})$.
- **↔️ Flip Horizontal & ↕️ Flip Vertical:**
  - Mirror groups across their bounding centroid to adapt left-shoulder or right-shoulder flourishes across paired costumes.
- **🔍 Scale LED Spacing (Expanding / Contracting Size):**
  - Click **`🔍+ 110%`** (Expand) or **`🔍- 90%`** (Contract), or use the continuous **Scale LED Spacing Slider (50% to 200%)** to adjust spacing between LEDs around the centroid while maintaining the exact geometric shape!
- **🖱️ Group Canvas Dragging (Click & Drag Entire Group):**
  - Simply click and drag **any LED** belonging to an animation group on the canvas. The entire group automatically selects and moves together as a unified cluster, preserving internal LED spacing while resampling underlying graphic colors upon release.
- **Auto-Rearrange Integration:**
  - After pasting or transforming a group, remaining unassigned LEDs ($100 - \text{total assigned}$) are **automatically redistributed** evenly across open graphic space using Farthest-Point Sampling.

---

### 👥 LED Allocation Overview & Active Groups Browser
- **Allocation Progress Bar:** Real-time visual progress bar tracking how many LEDs are assigned to animation groups versus unassigned. Displays total assigned percentage and count (e.g. `24 / 100 LEDs (24%) assigned to groups`).
- **Quick Selection Actions:**
  - **`👥 Select All Grouped`**: Instantly selects all LEDs currently belonging to any group across the entire costume for bulk review.
  - **`⚡ Select Unassigned`**: Immediately highlights all ungrouped LEDs so you can quickly bundle remaining costume LEDs into a new zone with one click!
- **Rich Interactive Group Cards (`#activeGroupsList`):**
  - **Header:** Group emoji icon (e.g., 🎆 for fireworks, 🎡 for chase, 🎪 for marquee), bold group name, and total LED count badge.
  - **Badges:** Effect pill (`🎡 Chase @ 140 BPM`), Starburst geometry details (for fireworks: ray count and burst radius), Resting Baseline pill (`Idle: Off / Unlit`), and physical LED index ranges (`LEDs: #0–15`).
  - **Action Buttons:** `🎯 Select`, `📋 Copy`, `🔄 90°`, `➕ Cue`, `🗑️ Delete`.
  - **Instant Selection & Canvas Focus:** Clicking anywhere on a group card or clicking **`🎯 Select`** highlights all member LEDs on the canvas, opens their properties in the docked Inspector, and marks the card with a glowing active border.
  - **1-Click Show Cue Shortcut:** Click the **`➕ Cue`** button directly on any card to create a synchronized Show Cue on the Master Timeline—pre-configured with the group's effect and tempo—and immediately jump to the Parade Cue Director tab!
  - **One-Click Deletion:** Click the red **🗑️** button to delete a group, return its LEDs to the global baseline, and clean up associated timeline cues.

### 🎨 Group Color Palette Override & Multi-LED Color Control
When a group is selected (or when editing an existing group), changing its color applies cleanly across all member LEDs while maintaining group selection:
- **Dedicated Palette Swatches in Group Hub & Docked Inspector:** Click any of the 12 signature Disney parade color swatches (Dragon Green, Flame Orange, Electric Pink, Cinderella Blue, Belle Gold, Starlight White, Cheshire Violet, Mickey Red, Electric Lime, Alice Cyan, Coral Rose, Deep Indigo) or use the native color picker and RGB sliders.
- **Bulk Multi-LED Application:** The selected color updates every individual LED in the group, sets `activeGrp.colorMode = 'custom'` and `activeGrp.customColor`, and dynamically colors the group's animation routine on the canvas without collapsing the multi-LED selection.
- **Use Artwork Colors Reset Button:** Click **`Use Artwork Colors`** in the Group Hub to instantly restore the original sampled costume artwork colors for all member LEDs and reset `activeGrp.colorMode = 'original'`.

### 💡 Contextual Inspector Workflow: Explicit "Save Group" & Reliable In-Place Editing
Creating and editing groups is seamlessly integrated into both the Group Creation Hub (`From Selection` panel) and the docked Inspector at the bottom of the sidebar:
1. **Clear Empty State with Quick Group Chips:** When 0 LEDs are selected, the Inspector displays clickable group chips (e.g. `[🎆 Fireworks 1 (20)]`, `[🎡 Front Wheel (16)]`). Clicking any chip immediately selects that group from anywhere in the application!
2. **Dynamic Action Button & State Tracking:**
   - **New Group Creation:** When new LEDs are selected, the primary action button clearly reads **`💾 Save Selection as Group`** (green accent).
   - **Reliable In-Place Editing:** Clicking **`🎯 Select & Edit`** on any group card sets the active edit context (`selectedGroupId`). All form fields in both the Groups Hub and the docked Inspector automatically populate with that group's settings. The button dynamically shifts to **`💾 Update Group "[Name]"`** (blue accent).
   - **Bidirectional Two-Way Form Sync:** Modifying the Name, Effect, Speed (BPM), Direction, Resting Baseline, or Fireworks Burst Radius in either the Hub or the docked Inspector instantly syncs to the other.
   - **Immutable ID Preservation:** Clicking **`💾 Update Group`** saves changes directly to the existing group in-place using its unique group ID. Renaming a group updates its name immediately without creating unwanted duplicates or losing member LED assignments.
3. **Group Configuration Parameters:**
   - **Direction:** Select **Forward (➡️)** or **Reverse (⬅️)** for directional chase animations (crucial for ensuring left and right carriage wheels appear to roll forward!).
    - **🔄 Phase Offset ($0^\circ \dots 360^\circ$) & Dual-Wheel Anti-Phase:**
      - Adjust the **Phase Offset Slider ($0^\circ \dots 360^\circ$)** to control the exact rotational or wave timing of the group relative to the global beat clock ($\text{effectiveTimeMs} = \text{timeMs} + \frac{\text{deg}}{360} \cdot T_{\text{beat}}$).
      - **Quick Preset Badges:** One-click presets for `0° (Synced)`, `90° (Quarter Phase)`, `180° (Anti-Phase)`, and `270° (3/4 Phase)`.
      - **Dual Wheel Anti-Phase Simulation:** Set the front carriage wheel to $0^\circ$ and the rear carriage wheel to $180^\circ$ so that as one wheel's spoke crests at 12 o'clock, the other crests at 6 o'clock—creating mesmerizing organic mechanical realism!
    - **🔗 Sync Speed With (Master-Follower Tempo Coupling):**
      - Link any child group to a master group (e.g., link *Rear Wheel* to *Front Wheel*). Whenever you modify the master group's BPM slider, all follower groups dynamically inherit the new tempo in real time while maintaining their independent phase offsets!
    - **🔀 Auto-Stagger Phase Button:**
      - In the Active Groups section header, click **`🔀 Auto-Stagger Phase`** to automatically divide and distribute full $360^\circ$ phase cycles evenly across all active groups ($360^\circ / N$). Perfect for multi-tier turtle/snail whorls or starburst cascades. Fully undoable via `Ctrl+Z`.
   - **Group Effect:** Choose an effect from the dropdown:
     - *🎡 Chase / Wheel Spin:* Chases illuminated heads around the ring.
     - *💓 Breathing Glow Pulse:* Pulses the group in sync or out of phase with the baseline.
     - *💡 Slow Flashing / Blink:* Theatrical blinking.
     - *✍️ Write-On / Write-Off:* Successively illuminates the group in sequence.
     - *✨ Sparkle Storm:* High-energy glitter and sparkle storm.
     - *🎪 Theater Marquee:* 3-phase theatrical marquee chase.
     - *🌈 Rainbow Color Wave:* Smooth cycling rainbow wave across the group.
     - *🎆 Fireworks (Radiating Starburst):* 4-phase pyrotechnic explosion with center ignition flash, outward expanding spark trails with decaying ember tails, starlight tip crackles, and dark sky resets. Uses serpentine wiring geometry for maximum solder efficiency.
     - *🌑 Off / Completely Unlit:* Keeps the group unlit.
   - **Dedicated Firework Burst Scale / Radius Controls:** When an inspected group is set to `fireworks`, an interactive **Firework Burst Scale / Radius** panel automatically appears directly inside the Group Inspector card:
     - *Dynamic Radius Slider:* Continuously scale the explosion radius from **5%** (tight, compact burst) to **28%** (wide, theatrical starburst across the entire upper torso).
     - *Quick Preset Buttons:* Instant one-click size presets: **S (8%)**, **M (13% - Default)**, **L (18%)**, and **XL (24%)** with visual active-state highlighting.
     - *Bidirectional Live Sync:* Adjusting size in the Group Inspector instantly synchronizes the Section 5a Fireworks Generator card, updates LED positions on the canvas, recalculates wiring lengths, and reflects across all inspector coordinate readouts.
   - **Resting Baseline Effect (When Idle / No Cue):** Configure what the group does when resting outside active timeline cues in Sequence Mode (100% option parity with Tab 2 Ambient patterns):
     - *🌐 Follow Overall Baseline (Default):* The group seamlessly follows the overall float background pattern/cue (e.g. `steady_sparkle`), matching all non-grouped float LEDs.
     - *🌑 Off / Completely Unlit:* The group stays 100% dark (pitch black) outside active cues. Default for fireworks, and ideal for theatrical accents like carriage lanterns, Elliott's dragon fire breathing, or Casey Jr.'s headlight until detonated/triggered on the timeline!
     - *✨ Steady Colors + Occasional Sparkle:* Calm starlight twinkling on group pixels.
     - *🌬️ Slo-Glo Breath (Color-Matched Glow):* Gentle ~30–45 BPM breathing glow preserving sampled artwork hues.
     - *☄️ Meteor / Comet Trail:* Continuous looping comet head with a glowing exponential tail circling group perimeters.
     - *🛸 Larson Scanner (Ping-Pong Sweep):* Dynamic back-and-forth beam sweep with smooth turnaround wakes.
     - *✍️ Color Wipe / Progressive Fill:* 4-phase write-on fill, radiant hold, wipe-off, and rest.
     - *💫 Pixie Dust Drift:* Drifting starlight shimmer cascade rolling across the group.
     - *⚡ Vintage 1972 Filament:* Micro-voltage analog warmth mimicking Walt Disney World's original incandescent parade bulbs.
     - *🕯️ Candle / Lantern Flame:* Warm amber/gold organic flame flicker with random multi-harmonic micro-jitter.
     - *🌊 Tidal Ripple:* Radial wavefront expanding and contracting from group centroid.
     - *🚂 Locomotive Piston Chug:* 4-stroke mechanical cadence pulse with sharp power stroke and exhaust.
     - *🎪 Classic Marquee Chase:* 3-phase chasing incandescent border.
     - *🎆 Fireworks (Radiating Starburst):* Full pyrotechnic explosion sequence.
     - *🌈 Rainbow Wave:* Flowing chromatic wave across the group.
     - *📸 Castle Photo Mode:* 100% solid maximum radiance for photo stops.
     - *🔦 Flashlight / Searchlight Roam:* 2D roaming light pool wandering smoothly across the garment with a soft Gaussian beam wake.
     - *🐭 Scurrying Mouse (Single Dot + Tail):* Single ultra-bright point (1 LED) with a long trailing glowing tail (~20 LEDs) that races and scampers along the strand in non-linear bursts with quick direction reversals.
     - *Cue Crossfading:* When an active cue on that group fires, the show engine smoothly crossfades from the group's configured resting baseline into the active cue effect, and seamlessly returns to baseline when the cue ends.

---

## 6. Physical Wiring Route Optimization (10cm Wire Pitch & Slack-Aware Tour)

Attaching LEDs to a shirt by hand can easily result in tangled wire spaghetti or severe wire bunching if the layout ignores physical wire pitch. The simulator solves this with an advanced **10cm physical wire slack-targeted routing optimizer**.

### How It Works
1. **10cm Physical Wire Pitch Calibration:** Wearable WS2812B pebble/fairy light strands have a fixed **10.0 cm (100 mm / ~3.94") wire pitch** between consecutive nodes.
2. **Slack-Targeted Cost Function:** Instead of blindly connecting to the closest spatial neighbor (which averages only 1.6 cm apart and forces 8+ cm of excess wire to be accordion-folded on every step!), the router targets an optimal **6.0 cm to 8.0 cm (2.4" to 3.15") straight-line span**.
3. **Gentle Natural Slack (Zero Accordion Folding):** This leaves **2.0 cm to 4.0 cm (20% to 40%) of relaxed, comfortable wire slack** behind the mesh. The wire hangs in a natural, flat curve that flexes with the runner's body over the 10K course without requiring any folding, looping, or tape bundles!
4. **Hard Physical Reach Constraints:** Strictly bounds every span to $\le 9.2\text{ cm}$, guaranteeing no wire segment is pulled taut or strained.
5. **Interactive Controls:**
   - Click **`🔌 Optimize Wiring Route (10cm Slack)`** in Tab 1 to re-route all LEDs with this slack optimization.
   - Toggle **`🧵 Wire Tension Heatmap`** to view color-coded segments:
      - 🔵 **Blue (`<4.5 cm`):** Excess Slack / Folding Warning.
      - 🟢 **Green (`4.5–8.5 cm`):** Optimal Slack Sweet Spot (Flat, zero-fold fit).
      - 🟡 **Yellow (`8.5–9.2 cm`):** Snug (minimal slack).
      - 🔴 **Red (`>9.2 cm`):** Overstretched Alert (Taut).
   - Toggle **`⚓ Show Strain Relief Bridges (10mm Keep-Out)`**:
      - Renders the exact physical 3D bridge footprints directly on the 2D layout canvas positioned 1:1 with the 3D STL chassis geometry inside the character silhouette:
        - **Bottom IN Bridge:** Sits on the bottom foot contour floor ($8.0\text{ mm W} \times 7.2\text{ mm H}$, Accent Emerald `#00ff88`) with its $3.2\text{ mm} \times 2.8\text{ mm}$ zip-tie tunnel, rim U-notch, and direct leader wire to LED #0.
        - **Lateral Right OUT Bridge:** Sits on the right flank contour floor ($7.2\text{ mm W} \times 8.0\text{ mm H}$, Accent Coral `#ff4d6d`) with its zip-tie tunnel, rim U-notch, and direct leader wire from LED #(N-1).
      - Projects a **$10.0\text{ mm}$ safety clearance keep-out halo** (dashed perimeter border with translucent fill) around both strain relief locations to prevent LED sockets from encroaching on the zip-tie anchor points.
      - Displays compact technical labels directly at the bridge blocks with zero external floating badge clutter.
   - **Single LED Selection Isolation:** Selecting any individual LED automatically isolates the wiring visualization to only the segment arriving at the LED ($i-1 \rightarrow i$) and the segment departing from it ($i \rightarrow i+1$), removing background wire clutter for focused alignment.

### 🎆 Fireworks Starburst Generator, Multi-Burst Stamping, & Scaling
Creating radial fireworks bursts requires clean geometry, flexible placement, and predictable physical wiring:
1. **Multi-Burst Stamping & Smart Offset Positioning:**
   - Click **"🎆 Stamp Fireworks Burst (+ Add Another)"** to stamp one or more firework bursts onto the costume.
   - **Smart Offset Placement:** The first burst defaults to the upper corner (**↖ Top-Left corner** at $x = 28\%, y = 22\%$, above the race bib clearance zone). Subsequent bursts are automatically positioned with a distinct visual offset (Firework #2 at $x = 58\%, y = 26\%$, Firework #3 at $x = 38\%, y = 40\%$, etc.) so you can immediately see multiple fireworks side-by-side without any overlap.
   - **Active Firework Group Selector:** When multiple fireworks exist, an **Active Firework Group** dropdown appears directly in the controls card. Selecting any firework instantly syncs the Move X/Y sliders, radius slider, and color controls to that specific cluster, and highlights its LEDs on the canvas.
   - **One-Click Group Deletion:** Click **"🗑️ Remove"** next to the active firework selector to cleanly delete that specific firework group, remove its timeline cues, and automatically re-distribute the reclaimed LEDs back to the character graphic.
   - **Direct Canvas Selection:** Clicking or dragging any LED of a firework cluster on canvas automatically selects that firework in the Active Group dropdown and updates all sliders in real time!
2. **Move & Scale Controls (Geometry Box & Quick Presets):**
   - **Consolidated Position & Scale Geometry Box:** Section 5a groups Move X, Move Y, and Scale / Burst Radius together in a dedicated high-contrast dark panel (`📐 Position & Scale (Size)`) right above the color controls.
   - **Move X & Move Y Sliders:** Fine-tune position horizontally ($15\% - 85\%$) and vertically ($15\% - 55\%$) with live badge percentage feedback.
   - **Scale / Burst Radius Slider & Quick Presets:** Dynamically expand or contract the burst diameter ($5\% - 28\%$, default $13\%$) with live slider feedback or click any of the 4 quick preset buttons:
     - **S (8%):** Tight, compact accent burst.
     - **M (13%):** Standard balanced Disney fireworks burst (default).
     - **L (18%):** Expanded starburst spanning the upper chest.
     - **XL (24%):** Grand finale burst spanning the entire upper chest width.
   - **Dual-Card Synchronization:** The Scale / Burst Radius slider and S/M/L/XL buttons are available and bidirectional across **both** Section 5a (Fireworks Card) and Section 5b (Group Animation Inspector).
   - **Direct Canvas Multi-Drag:** Simply click and drag any LED belonging to any firework cluster directly on the costume canvas! The entire starburst moves as a unified group, and the Move X/Move Y sliders update synchronously in real-time.
3. **Uniform Color per Firework Group (Presets & Custom Color Picker):**
   - **Uniform Ray Color:** All rays of a firework group share the **exact same uniform color** (e.g. all 5 rays Golden Amber, all 5 rays Alice Cyan, etc.) for a clean, coherent theatrical pyrotechnic burst.
   - **Automatic Palette Rotation:** Stamping additional fireworks automatically assigns a contrasting color from the signature palette (**✨ Golden Amber**, **💠 Alice Cyan**, **💖 Coral Rose**, **⚡ Electric Lime**, **💜 Royal Violet**, **🔥 Blazing Red-Orange**, or **⭐ Starlight White**).
   - Select **🎨 Custom Hex Color...** to open an interactive native color picker and dial in any specific hex color.
   - Changing colors updates all rays of the active cluster in real time while maintaining warm incandescent shifts along the trailing rays.
4. **Persistent Center Trailing Effect & Completely Off (Unlit) Baseline:**
   - In previous iterations, all LEDs dimmed out as the wavefront moved or bled into global background patterns. Now:
     - *Completely Off (Unlit) Baseline:* Outside active explosion cues, all firework LEDs remain **100% off (unlit)**. They do not participate in global background chases or ambient sparkles, keeping the firework location dark and invisible until detonation. Unlit LEDs render realistically on canvas as dark SMD pixel beads (`rgba(22, 26, 33, 0.85)`) without artificial central white filament cores or glow bloom.
     - *Phase 1 (Ignition):* Center flashes with white-hot brilliance while outer unreached LEDs remain completely dark (unlit).
     - *Phase 2 (Expanding Wavefront):* Center LEDs hold at high intensity ($\sim 70\%$) while trailing embers bridge the line out to the spark head, creating a continuous radiating streak of fire. Ahead of the expanding wavefront, outer LEDs stay completely unlit.
     - *Phase 3 (Tip Crackle):* Center stays lit ($\sim 50\%$) as a visual anchor while outer tips crackle; burned-out inner steps turn completely off.
     - *Phase 4 (Rest / Idle):* Burst concludes, all firework LEDs fade out completely to **0% intensity (black/unlit)** until the next scheduled burst.
5. **Master Timeline Scheduling & Explosion Cue Director:**
   - **Automatic Timeline Auto-Placement:** Stamping a fireworks cluster automatically creates and schedules fireworks explosion cues on the Master Timeline in the Parade Cue Director and turns Sequence Mode ON.
   - **Orchestrated Multi-Firework Staggering:** When stamping multiple fireworks, burst cues are automatically staggered by $+2.5\,\text{s}$ per group index (e.g. Firework #1 detonates at 6.0s, Firework #2 detonates at 8.5s) to produce an orchestrated, multi-stage fireworks show across your costume!
   - **Auto-Schedule Bursts:** Click **"⚡ Auto-Schedule Bursts"** in the Fireworks card to re-populate recurring explosion bursts evenly spaced across the full loop duration.
   - **Single Cue at Playhead:** Click **"⏱️ Add at Playhead"** to drop a burst cue for the active firework right at the current scrubber playhead position.
   - **Cue-Relative Phase Sync:** The firework explosion phase automatically synchronizes with the cue's start time ($t = \text{startTime}$ triggers Phase 0 ignition), ensuring the starburst explodes precisely on the theatrical cue!
   - You can schedule multiple fireworks cues throughout your parade loop, adjust BPM, and customize crossfade in/out times.
6. **Rays & Length Customization:**
   - Choose between **4, 5, or 6 Rays** radiating from the explosion origin.
   - Choose between **3, 4, or 5 LEDs per Ray** (e.g. 5 rays $\times$ 4 LEDs = 20 LEDs; $100 - 20 = 80$ other LEDs).
7. **Serpentine Wiring Geometry:**
   - To eliminate long, messy return wires from outer spoke tips back to the center hub, the generator utilizes **continuous serpentine routing**:
     - *Even Rays (0, 2, 4):* Wire travels outward (**Center $\to$ Tip**).
     - *Odd Rays (1, 3, 5):* Wire travels inward (**Tip $\to$ Center**), with a short 1-inch jump between adjacent spoke tips.
   - The animation engine automatically compensates for reversed rays, ensuring all lines visually radiate outward from the center simultaneously!
8. **Strict 100-LED Invariant & Full-Graphic Re-Distribution:**
   - Placing firework clusters claims LEDs from the float pool, preserving exactly **100 LEDs on screen** at all times ($N_{\text{float}} + \sum N_{\text{fw}} = 100$).
   - Click **"🔄 Re-distribute Other LEDs (Full Graphic)"** to re-distribute non-firework LEDs across the **entire character graphic** (without any exclusion zone) while keeping all existing firework clusters intact at their configured coordinates.
9. **Canvas Numbering & Identification:**
   - With **Show Numbers** active or when inspecting bulbs, each firework LED displays its exact ray and step badge: e.g. `R1:1 (CTR)`, `R1:4 (TIP)`, `R2:1 (CTR)`, `R2:4 (TIP)`.
   - The LED Inspector displays the full role breakdown: e.g. `Ray 2 of 5 • Trail Step 3 (Mid-Trail)`.

---

### BTF-LIGHTING WS2812B Strip Preview & Staggered Matrix Engine (60 / 100 / 144 LEDs per 3.2ft)

To explore alternatives to discrete individual pebble/seed pixels, the Layout tab features a dedicated **BTF-LIGHTING WS2812B IP67 LED Strip Preview Panel** (Section 3c: `#btfStripPreviewToggle`).

This feature models the exact optical geometry, silicone sheathing, solder cut intervals, and electrical current draw of **BTF-LIGHTING WS2812B IC RGB LED Strips (UL Listed, DC 5V IP67)** with selectable densities of **60, 100, or 144 LEDs per 3.2ft (1 meter)** arranged across the runner's chest in staggered rows or columns.

#### 1. Non-Destructive Canvas Overlay
- **Zero Impact on Baseline Design:** Toggling the strip preview **ON** (`#btfStripPreviewToggle`) temporarily replaces the canvas pebble rendering with a high-fidelity strip visualizer without modifying or deleting your placed LEDs, animation groups, wiring paths, or 3D TPU panel definitions.
- **Instant Toggling:** Switching the preview toggle **OFF** immediately restores your exact pebble LED layout and wiring tour.
- **Suppressed Background Wires:** When strip preview is active, discrete pebble wiring lines and slack tension arcs are automatically hidden to maintain visual clarity.

#### 2. Selectable Strip Densities (60, 100, 144 LEDs per 3.2ft / 1m)
Three quick-toggle density options are available (`#btfDensity60Btn`, `#btfDensity100Btn`, `#btfDensity144Btn`):
- **60 LEDs / 3.2ft (16.7mm pitch):** Standard density, linear pitch $P = \frac{1000\text{ mm}}{60} \approx 16.6667\text{ mm}$ (~0.656"). Lower overall LED count, low power draw.
- **100 LEDs / 3.2ft (10.0mm pitch):** Medium density, linear pitch $P = \frac{1000\text{ mm}}{100} = 10.0000\text{ mm}$ (~0.394"). Perfectly matches the 10mm width of the silicone ribbon sheath.
- **144 LEDs / 3.2ft (6.9mm pitch):** High density, linear pitch $P = \frac{1000\text{ mm}}{144} \approx 6.9444\text{ mm}$ (~0.273"). Ultra-high resolution matrix for crisp character silhouettes.

#### 3. Orientation, Staggering & Boundary Masking
- **Orientation Modes:**
  - **`↔️ Rows`:** Horizontal strip ribbons spanning across the chest.
  - **`↕️ Columns`:** Vertical strip ribbons running down the torso.
- **Stagger Alignments:**
  - **`🧱 50% Brick Stagger` (Recommended):** Shifts alternating rows/columns by half a pixel pitch ($\Delta = P_{\text{linear}} / 2$), creating an organic hexagonal/honeycomb LED packing density that eliminates rigid grid artifacts.
  - **`▦ Aligned`:** Standard orthogonal Cartesian matrix grid.
- **Boundary Masking Modes:**
  - **`✂️ Float Artwork`:** Only illuminates strip LEDs whose centers fall within the opaque silhouette of the active float artwork (alpha $> 35$), sampling vibrant character colors directly from the graphic.
  - **`🔲 Chest Panel`:** Fills the upper chest panel armor trapezoid above the race bib ($y = 0.17$ to $0.555$).

#### 4. Pitch Spacing, Flush Placement & Quick Presets
- **Proportional Plate Size Scaling (Small, Medium, Large):**
  - **📐 Small (~6.5" / 165mm):** Scales the float artwork silhouette down ($0.8125\times$), yielding fewer LEDs (e.g. ~21–26 LEDs on Pete's Dragon at 60/m).
  - **📐 Medium (~8.0" / 203mm):** Standard reference chest scale ($1.000\times$, e.g. ~28–41 LEDs on Pete's Dragon at 60/m).
  - **📐 Large (~10.0" / 254mm):** Expands the artwork silhouette ($1.250\times$) across the upper chest, generating significantly more LEDs (e.g. ~50–68 LEDs on Pete's Dragon at 60/m) while strictly preserving clearance above the race bib ($y \le 0.555$).
- **Strip-to-Strip Pitch Slider (`#btfSpacingSlider`):** Dynamically adjusts center-to-center pitch between adjacent ribbons from **6.9 mm to 40.0 mm** (with 0.1 mm precision). The live readout displays both pitch and physical gap between the 10mm silicone sheaths: e.g. `10.0 mm (0.0mm Gap - Flush)` or `16.7 mm (Gap: 6.7mm)`.
- **Quick Presets:**
  - **`📐 Match LED Pitch` (`#btfMatchPitchBtn`):** Sets the strip-to-strip pitch to exactly match the active linear LED pitch ($16.7\text{ mm}$ for 60/m, $10.0\text{ mm}$ for 100/m, $6.9\text{ mm}$ for 144/m). This forms an isotropic square or hexagonal staggered matrix.
  - **`⚡ Flush (10mm)` (`#btfFlushBtn`):** Places strips immediately side-by-side with zero gap ($10.0\text{ mm}$ center-to-center pitch), modeling solid ribbon panels.
  - **`🎯 Auto-Fit ~100` (`#btfAutoFit100Btn`):** An iterative numerical solver automatically calculates the strip spacing to land on **~95–105 LEDs**, perfectly satisfying the 2.0A portable power bank current envelope.
  - **`🌿 Relaxed (25mm)` (`#btfSparsePresetBtn`):** Sets relaxed 25.0 mm ribbon spacing for ultralight, low-current layouts.

#### 5. Real-Time Telemetry & Hardware Safety Budget
The telemetry card continuously updates as sliders, presets, or plate sizes change:
- **Total LEDs (`#btfTotalLedsVal`):** Current active SMD 5050 LED count across all strip runs.
- **Solder Cut Segments (`#btfTotalCutsVal`):** Number of discrete strip segments requiring cut/solder jumper wires (labeled `S1`, `S2`, `S3`... on canvas).
- **Total Strip Length (`#btfTotalLengthVal`):** Combined linear length in meters and feet (e.g. `1.63 m (5.4 ft)`).
- **5V Current Draw (`#btfEstCurrentVal`):**
  - **Max Current (Full White @ 50mA):** $I_{\max} = N_{\text{LED}} \times 0.050\text{ A}$
  - **Typical Animated Average (@ 20mA):** $I_{\text{avg}} = N_{\text{LED}} \times 0.020\text{ A}$
- **Hardware Safety Badge (`#btfStatusBadge`):**
  - 🟢 **`100-LED Safe (~2.0A Bank)`:** Highlighted in emerald green when $N_{\text{LED}} \le 105$.
  - ⚠️ **`Exceeds 100-LED Budget`:** Highlighted in crimson warning when power draw would overload a 2.0A portable power bank without aggressive FastLED software capping.

#### 6. Photorealistic IP67 Canvas Visualization (10mm Strips / 5mm LEDs)
- **10.0mm Translucent Silicone Tube Ribbons:** Renders strictly calibrated **10.0 mm wide** IP67 translucent white silicone sheathing ribbons with rounded caps, sealed perimeter borders, and copper solder cut tick marks between pixel packages.
- **Proportional 5.0mm SMD 5050 Packages & Radiant Phosphor Glow:** Draws square black SMD 5050 bodies (`#0d1117`) scaled to **strictly 5.0 mm wide** (occupying exactly 50% of the 10.0mm strip width with 2.5mm silicone margins on each side). Features circular phosphor emitter lenses ($3.2\text{ mm}$ die diameter), specular lens highlights, and breathing radial bloom glow.
- **Segment Callout Badges:** At higher zoom levels, each segment displays a high-contrast identifier (`S1`, `S2`...) indicating where physical cuts and 3-pin solder jumpers (5V, Data, GND) will be required.

#### 6. "Apply Strip Layout as Active LEDs"
If you decide to proceed with physical LED strips instead of pebble lights:
- Click **`✅ Apply Strip Layout as Active LEDs`** (`#btfApplyLayoutBtn`).
- The simulator replaces the active costume's pebble LEDs with the exact $(x, y)$ coordinates and sampled colors of the generated strip matrix.
- Recorded into the **Universal Undo History (`Ctrl+Z`)**, enabling instant reversal if needed.
- Once applied, the layout can be utilized immediately across the Wiring Optimizer, Cricut Cut Exporter, 3D TPU Armor Panel Compiler, and ESP32 Firmware Exporters.

---

## 7. Artwork Management & runDisney 10K Race Bib Overlay

You can choose from pre-loaded Disney parade artwork or upload your own high-resolution shirt graphics, complete with realistic race bib collision checking.

### Built-in Graphic Presets
Use the **Costume Graphic** dropdown in the Layout tab (Section 1) to instantly switch between all official parade units with automatic preset loading:
- **🚂 Float 01: Casey Jr. Locomotive (`casey_jr_train`):** Iconic circus engine with spinning drive wheels, illuminated cab, and flashing strobe headlight.
- **🥁 Float 02: The Title Drum (`title_drum`):** Massive illuminated bass drum with amber chase rim and classic marquee lighting. Powered by a high-resolution transparent 5-color multi-material graphic asset (`assets/title_drum.png`) optimized for Bambu AMS 3D printing (Black chassis/drum face, Gold rim & text, Red body panels, Blue flags, and Green lead flag).
- **🐢 Float 03: The Spinning Turtle (`spinning_turtle`):** Whimsical sea turtle with concentric spinning shell spiral and glowing fins.
- **🐌 Float 04: The Spinning Snail (`spinning_snail`):** Colorful garden snail with multi-tier shell whorls and neon antenna bulbs.
- **🎃 Float 05: Cinderella's Coach (`cinderellas_coach`):** Golden carriage outline with dual spinning wheels, pumpkin body, and royal lanterns.
- **🎠 Float 05: Carriage (No Horses) (`carriage_nohorses`):** Focused Cinderella coach design with clean wheel arches, royal carriage frame, and dedicated 100-LED preset.
- **🐉 Float 06: Pete's Dragon (Elliott) (`builtin_dragon`):** Default 100-LED layout with emerald body scales, magenta hair crest, and incandescent starlight sparkles.
- **🦅 Float 07: To Honor America (`honor_america_eagle`):** Grand patriotic eagle finale with sweeping red, white, and blue wing chases.

### 🖨️ Assembly & Print Placement Guide Mode (`🖨️ Placement Guide`)
For physical assembly and workshop workbench printing, the Layout tab features a dedicated **Graphic View Mode** toggle (`[🎨 Full Color]` / `[🖨️ Placement Guide]`), also accessible via the canvas zoom toolbar:
- **🪞 Mirrored Back View (Workbench Assembly):** Flips the placement guide canvas and artwork image horizontally (default **Active**) so that when placing LEDs, TPU panels, and wiring from behind the costume on your workbench, left/right on screen matches your physical perspective looking at the back! Includes a toggle button to switch between `🪞 Mirrored Back` and `👕 Normal Front` as needed.
- **Faint Character Artwork Watermark:** Subdues the float artwork to a faint background opacity (default **22%**, customizable from 10% to 60%) so you can clearly see the float's physical boundaries and features without clashing with the LED indicators.
- **Exact 3×3 mm Square Windows:** Replaces live lighting glow blooms with crisp, physical **3.0 mm × 3.0 mm square apertures** with high-contrast borders and precision center registration marks matching physical 3D TPU armor panel optical pockets.
- **Crisp LED Numbers Right Above Windows:** Automatically renders each LED's strand index ($0 \to N$) directly above its corresponding 3×3 mm square window. Sized compactly at **bold 8px** with a dark contrast halo outline for maximum legibility without cluttering adjacent pixels.
  - **LED #0:** Highlighted in green (`#00ff88` / `#16a34a`) for 5V + DIN strand start.
  - **Last LED (#74 / #99):** Highlighted in red (`#ff4d6d` / `#dc2626`) for strand termination.
- **Sheet Styles (Dark Garment vs. Light Print Paper):** Toggle between **👕 Dark Garment** (black tech shirt backing) and **📄 Light Paper** (crisp blueprint style that saves black printer toner).
- **🖨️ Print / Save Placement Sheet:** One-click button that generates a high-resolution, print-ready document or PNG download featuring float title, view perspective (Mirrored Back View), pixel counts, aperture dimensions, wiring route trace, and a color-coded strand legend.

### 🏷️ runDisney 10K Race Bib (#1952) with Chip & Dale
Section 4 features an authentic runDisney race bib overlay (default **8.0" wide by 7.0" high**, matching physical runDisney bib specs on an 18" x 24" running shirt) on the lower torso to verify physical clearance with your running gear:
- **Mostly Yellow Tyvek Theme:** Official sunny yellow gradient background (`#fef9c3` to `#facc15`), golden amber trim (`#ca8a04`), subtle athletic speed chevrons, and red/blue racing side stripes.
- **Official Chip 'n' Dale Mascots:**
  - **Chip (Left Flank):** Chocolate chip black nose, single centered buck tooth, dark chocolate brown fur, cream muzzle, and red runner's headband.
  - **Dale (Right Flank):** Signature big shiny red nose, messy hair tuft between ears, two separated buck teeth, playful winking eye, and royal blue & gold runner's headband.
  - **Acorn Accents:** Golden acorns (`🌰`) flanking the runner sub-label `MSEP RUNNER`.
- **Top Header Banner:** Royal Disney Navy banner (`#1e1b4b` ➔ `#312e81`) with gold trim, `★ runDisney`, `WALT DISNEY WORLD® 10K`, official `CHIP 'N' DALE 10K` title ribbon, and `CORRAL A` badge.
- **Center Race Number:** High-contrast athletic number **`1952`** with crisp white outline and dark slate fill.
- **PhotoPass Barcode:** Lower barcode window with `DIS-1952-10K`.
- **BibBoards Fasteners:** Accurately renders the snap-and-lock circular pucks at all 4 corners (outer casing, cyan accent ring, center dome button with specular highlight) so you can visually verify clearance before pinning your shirt!
- **Interactive UI Controls (Section 4):**
  - **Toggle Checkbox:** Show/Hide the bib overlay at any time.
  - **Height Slider:** Adjust vertical elevation on the torso (range: 50% to 75%, default **57%**).
  - **Scale Slider:** Dynamically resize the bib from **60% to 140%** (default **100%**) while preserving all internal artwork, character illustrations, and clamp points.

### Custom Artwork Upload
1. In Section 1, choose **"Upload Custom Artwork Image"**.
2. Select any high-resolution transparent PNG or JPEG image from your computer.
3. The simulator immediately renders your artwork in the center of the shirt canvas.
4. Click **"✨ Scatter 100 Color-Matched LEDs"**:
   - The simulator uses a multi-pass Poisson disk scatter to distribute 100 LEDs evenly across your graphic.
   - It samples the true RGB pixel color beneath each LED, automatically creating a color-matched palette!
5. Click **"🔄 Resample Colors from Artwork"** at any time to re-sample pixel values if you change or replace the artwork.

### ✂️ Cricut Heat Transfer Vinyl (HTV) Cut Files & Exporter Suite
Production-ready layered vector SVG files for all 7 floats are included in `assets/cricut_svg/`:
- **The Train / Casey Jr.:** [`assets/cricut_svg/casey_jr_train.svg`](assets/cricut_svg/casey_jr_train.svg) (4 mats: Red, Gold, Cyan, White)
- **The Title Drum:** [`assets/cricut_svg/title_drum.svg`](assets/cricut_svg/title_drum.svg) (4 mats: Navy, Gold, Cyan, White)
- **The Spinning Turtle:** [`assets/cricut_svg/spinning_turtle.svg`](assets/cricut_svg/spinning_turtle.svg) (4 mats: Teal, Yellow, Red, White)
- **The Spinning Snail:** [`assets/cricut_svg/spinning_snail.svg`](assets/cricut_svg/spinning_snail.svg) (4 mats: Yellow, Pink, Cyan, White)
- **Cinderella's Coach:** [`assets/cricut_svg/cinderella_coach.svg`](assets/cricut_svg/cinderella_coach.svg) (3 mats: Cyan, Gold, White)
- **Pete's Dragon (Elliott):** [`assets/cricut_svg/petes_dragon.svg`](assets/cricut_svg/petes_dragon.svg) (4 mats: Green, Pink, Orange, White)
- **To Honor America (Flag & Eagle):** [`assets/cricut_svg/honor_america_eagle.svg`](assets/cricut_svg/honor_america_eagle.svg) (4 mats: Blue, Red, Gold, White)
- **Interactive Visual Catalog:** Double-click [`assets/cricut_svg/cricut_catalog.html`](assets/cricut_svg/cricut_catalog.html) to inspect layers, preview specs, and download files.
- See **[`CRICUT_ARTWORK_GUIDE.md`](CRICUT_ARTWORK_GUIDE.md)** for complete step-by-step Cricut Design Space upload, mat mirroring, multi-layer tack press temps, and LED attachment guides.

#### 🌟 1-Click Cricut Cut Exporter Modal (`✂️ Export Cut SVG`)
Clicking **`✂️ Export Cut SVG`** on Tab 1 (Layout) opens a dedicated production dialog with 3 export workflows:
1. **🌟 Master All-in-One Multi-Layer SVG (Recommended for Cricut):**
   - Combines the full multi-colored vector character artwork with all 100 tangent-oriented $6.0\,\text{mm} \times 3.0\,\text{mm}$ pill slots and 4-corner heat press registration marks into a single SVG file.
   - Cricut Design Space automatically parses the file and sorts each color onto its own cutting mat, with the pill cutouts already positioned in place!
2. **🎨 Mat-by-Mat SVGs (Single Color Mats):**
   - Individual download buttons for each color vinyl sheet (e.g. Green Mat, Pink Mat, Orange Mat, White Mat).
   - Each file isolates one color layer, includes 4-corner registration crosshairs, and embeds only the pill cutouts sitting on that specific color.
   - Includes a **`📦 Download All Mats`** button to download all color sheets in one sequence.
3. **🕳️ Standalone 100-Pill Cutouts Layer:**
   - Isolated $6\times 3\,\text{mm}$ pill cutouts layer with 4 registration crosshairs (ideal for custom templates or manual overlay).

#### 🐲 Pete's Dragon Uniform Pink Crest, Wings & Tail Spines Rule
In both the pixel sampling engine (`boostLedVibrancy`) and the Cricut cut exporter:
- **Strict Green Scale Protection:** Any pixel with a dominant green channel or hue in the yellow-green to cyan-green spectrum (55° to 180°)—including dark green scale shading, contours, and lime underbelly tones—is strictly guarded and guaranteed to resolve to vibrant dragon green (`#00cc66` / `CRGB(15, 255, 35)`). Green scales are never misclassified as pink regardless of spatial bounding boxes.
- **Authentic Dragon Pink Features:** The **Wild Jagged Hair Crest** on the head, the **Dragon Wings**, and the **Dorsal Spine Plates & Tail Spines** are uniformly classified as signature **Disney Dragon Pink** (`CRGB(255, 25, 230)` / `#ff19e6` / `#ff007f`).
- Pixels sampled across these genuine pink zones are protected against dark line art or green shadow misclassification and automatically route to **Mat 2: Pink HTV Vinyl**.

#### 🥁 Float #2: The Title Drum 5-Color Authentic Sampling Rule
When Float #2 (The Title Drum) is selected, `boostLedVibrancy` activates an authentic 5-color mapping engine matching the 3D-printable and vinyl artwork palette:
- **Marquee Gold (`#facc15` / `[250, 204, 21]`):** High-vibrancy parade golden amber (`{ r: 255, g: 204, b: 21 }`).
- **Body & Streamers Red (`#ef4444` / `[239, 68, 68]`):** Radiant crimson red (`{ r: 239, g: 68, b: 68 }`).
- **Lead Pennant Green (`#10b981` / `[16, 185, 129]`):** Electric flag green (`{ r: 16, g: 200, b: 129 }`).
- **Flags & Pennants Blue (`#2563eb` / `[37, 99, 235]`):** Electric royal blue (`{ r: 37, g: 99, b: 255 }`).
- **Drum Face & Chassis Black (`#11161d` / `[17, 22, 29]`):** Warm incandescent starlight white (`{ r: 255, g: 245, b: 220 }`), representing the illuminated vintage interior starlight bulbs of the Electrical Parade drum face rather than remaining unlit or falling back to Pete's Dragon pink/green.
- **Robust Image Guarding:** All sampling routines (`sampleColorAtNorm`, `resampleAllLedColors`, `rearrangeRemainingLedsOnGraphic`, `scatterLedsOnGraphic`) verify that the float artwork image is fully decoded (`naturalWidth > 0`), ensuring crisp instant resampling upon float switching, scattering, or group rearrangement.

---

## 8. Master Timeline Scrubber & Multi-Layer Tracks

The **Master Timeline Bar** is anchored at the bottom of the canvas view and operates like a digital audio workstation (DAW) or non-linear video editor (NLE).

```
┌────────────────────────────────────────────────────────────────────────────────────────┐
│  ▶  ⏹  00:32.4 / 01:30.0   [ 3 Layers ] [ Active: Royal Carriage Glow + Wheels Spin ]  │
├────────────────────────────────────────────────────────────────────────────────────────┤
│  TIMELINE   |00:00        |00:15        |00:30        |00:45        |01:00        |01:30  │
├─────────────┴──────────────────────────────────────────────────────────────────────────┤
│  🌐 Global:  [ Opening Sparkle (25s) ] [ Royal Carriage Glow (40s) ]                  │
│                                                     [ Grand Finale Wave (30s) ]        │
├────────────────────────────────────────────────────────────────────────────────────────┤
│  🎡 Wheels:                [ Carriage Wheels Spin (35s) ]                              │
├────────────────────────────────────────────────────────────────────────────────────────┤
│  💡 Lanterns:                               [ Lanterns Pulse (25s) ]                   │
└────────────────────────────────────────────────────────────────────────────────────────┘
```

### Transport Controls
- **▶ Play / ⏸ Pause:** Starts or pauses continuous 60 FPS theatrical playback. Press the `Spacebar` anywhere on the page to toggle.
- **⏹ Stop / Rewind:** Immediately stops playback and rewinds the playhead to `00:00.0`.
- **Time Readout:** Displays current position down to tenths of a second alongside total loop length (`00:15.5 / 01:30.0`).
- **🔁 Loop Button:** When active (green), playback seamlessly wraps from the end back to `00:00.0`.
- **Unified Master Timeline Engine:** The timeline is always active and looping. When cues are scheduled on the timeline, they execute precisely during their scheduled intervals. When no cues are scheduled (an empty timeline) or during gaps between cues, the costume automatically falls back to its **ambient artwork programming** (the sampled chest graphic colors with rare starlight sparkles), while animation groups execute their resting baseline routines.

### Context-Aware Master Timeline (Single Shirt vs. Fleet Tab Modes)
The Master Timeline dynamically switches display and transport logic depending on whether you are editing a single costume or orchestrating the 7-shirt fleet:

1. **Single Shirt Editing Mode (`Single View` / Tabs 1–5):**
   - **Ruler & Duration:** 0:00 to 01:30.0 (or custom loop duration up to 300s) with formatted MM:SS.S ticks.
   - **Multi-Layer Tracks:** Displays `🌐 Global Float` and all localized `🎡 [Group Name]` lanes with automatic sub-lane stacking for overlapping cues.
   - **Transport Controls:**
     - `▶` Play / `⏸` Pause: Controls playback along the master timeline (`Spacebar`).
     - `⏹` Stop: Rewinds cue sequence to `00:00.0`.
     - `🔁 Loop`: Toggles seamless continuous sequence looping.
     - **Status Badge:** Dynamically reports active cue names or displays `Ambient Program (Fallback)` during intervals without cues.
   - **Interaction:** Clicking cue blocks seeks playhead time and highlights the corresponding cue card in the Parade Cue Director.

2. **Fleet Tab Mode (`Fleet View` / Tab 5):**
   - **Ruler & Duration:** 0.0s to 30.0s (or active fleet show duration) with decimal second ticks.
   - **Fleet Show Choreography Track:** Displays color-coded fleet block bars with block icons (e.g. 🌊 Forward Wave, 💓 Fleet Pulse, ⛈️ Sparkle Storm) spanning all 7 costumes.
   - **Transport Controls:**
     - `👑` / `▶` Activate / `⏸` Stop: Triggers the one-shot 30-second synchronized fleet routine (`Spacebar` or `[F]` hotkey with 300ms debounce protection).
     - `⏹` Stop: Immediately terminates the fleet routine early and returns all 7 shirts to their baseline programs.
     - `👑 Fleet Show: ON / ⚡ Baseline: ON`: Context badge indicating whether the fleet routine is currently firing or running in baseline float program standby.
     - `🔁 Loop`: Hidden during fleet playback to guarantee clean one-shot execution returning to baseline.
   - **Interaction:** Clicking fleet blocks or dragging the scrubber seeks smoothly across the 30-second routine with real-time 7-shirt canvas preview.

### The Multi-Layer Track System (Scenario B Stacking)
- **Dedicated Track Lanes:**
  - **Track 1 (`🌐 Global Float`):** Displays all cues affecting the whole float baseline.
  - **Tracks 2+ (`🎡 [Group Name]`):** Displays cues targeting localized groups (e.g. `Front Wheel`, `Rear Wheel`, `Lanterns`).
- **Automatic Sub-Lane Stacking:** When multiple cues on the same layer overlap in time (e.g., crossfading between two global cues), the track automatically expands into stacked sub-lanes so **both cues remain 100% visible** without overlapping or clipping!
- **Interactive Cue Blocks & NLE Drag-and-Drop Editing:**
  - Displays the cue's title, total duration, and visual fade-in/fade-out gradient indicators.
  - When a cue is actively firing, it lights up with a glowing white/cyan border.
  - **Drag-to-Move (Slip Clip):** Click and drag the central body of any cue block (`cursor: grab` / `cursor: grabbing`) to slide its position earlier or later along the timeline without altering its duration. Snaps to clean 0.1s increments and stays bounded within the timeline loop length.
  - **Left Edge Trimming (`.handle-left`):** Hover over the left border of a clip (`cursor: ew-resize`) and drag left or right to adjust the cue's **Start Time**. The right end time stays firmly locked in place while the start time and duration adjust dynamically (minimum duration clamped to 0.5s).
  - **Right Edge Trimming (`.handle-right`):** Hover over the right border of a clip (`cursor: ew-resize`) and drag left or right to lengthen or shorten the cue's **Duration**. The start time stays locked in place.
  - **Real-Time Floating Tooltip:** While dragging or trimming, an elevated cyan timecode badge floats directly above the cursor displaying live readouts: `Start: 12.4s | End: 28.6s (Dur: 16.2s)`.
  - **Live Sidebar Synchronization:** Dragging or resizing immediately synchronizes the numeric inputs (`.cue-start-input`, `.cue-dur-input`) and time badges on the corresponding card in the Parade Cue Director and flags the shirt configuration as modified (`isSingleShirtDirty = true`).
  - **Smart Click Discrimination:** A 4-pixel movement threshold ensures that short clicks without dragging cleanly jump the playhead to that cue's start time and smoothly scroll the sidebar directly to its editing card without accidental position shifts.
- **Synchronized Playhead Needle:** A vertical cyan line extends across all tracks from top to bottom, moving smoothly with playback to show exactly which cues are active at the current moment.
- **Seek Ruler:** Formatted time ticks (`00:00`, `00:15`, `00:30`, etc.) display along the top. Click or drag anywhere across the ruler or track lanes to scrub in real time.

---

## 9. Parade Cue Director (Individual Float Standby Sequences)

Located in **Tab 4 (`🎬 Show`)** of the left sidebar, the **Parade Cue Director** scripts the theatrical 90-second timeline for the **active individual float** (e.g., Casey Jr.'s locomotive puffing, Cinderella's pumpkin wheels spinning, or Elliott's dragon crest flames).

> [!IMPORTANT]
> **Individual Standby vs. Synchronized Fleet Routine:**
> * **Individual Routine (Tab 4):** Each of the 7 floats runs its own independent 90-second show sequence or continuous baseline pattern while running on the course.
> * **Fleet Takeover (Tab 5):** When a runner single-taps their ESP32 onboard BOOT button or when you trigger the 30-second Fleet Routine in the **🏃 Fleet** tab, ESP-NOW wireless broadcasts immediately take over all 7 shirts to execute the synchronized routine (waves, synchronized pulses, sparkle storms).
> * **Automatic Return:** The moment the 30-second fleet routine finishes, every float seamlessly returns to its individual show sequence or baseline program!

### Structuring a Cue
Click **➕ Add Cue** to create a new cue card with the following settings:
- **Cue Name:** A custom theatrical label (e.g., `Carriage Wheels Spin`, `Snout Fire Breath`, or automatic `[Group Name] Routine`).
- **Target Layer:** Select either `🌐 Global Float` or any active animation group (e.g. `🎡 Group: Front Wheel`).
  - **Group Preset Inheritance:** When an animation group is selected in the Target Layer dropdown (or when clicking **`➕ Add Cue`** while a group is active), the cue automatically inherits the **Pattern / Effect**, **Direction**, and **BPM (Tempo)** configured when the group was created, saving setup time while still allowing you to freely change the effect in the dropdown!
- **Pattern / Effect:** Select from the unified library of 16+ built-in lighting effects (see Section 10).
- **Direction:** Select `➡️ Forward` or `⬅️ Reverse` for traveling animations (comet sweeps, marquee chases, waves, Larson scans).
- **Start Time (s):** Time offset in seconds from the beginning of the show loop (0.5s resolution).
- **Duration (s):** How long the cue runs before fading out (with instant quick chips: `5s`, `10s`, `15s`, `30s`).
- **BPM (Tempo):** The speed of the animation during this specific cue (with instant quick chips: `90`, `120`, `144`, `180 BPM`).
- **Crossfades (Fade In / Fade Out):**
  - **In (s):** Smooth ramp-up blend from baseline color into the effect (`0.0s` for an instant cut, up to `5.0s` for a soft cinematic blend).
  - **Out (s):** Smooth ramp-down blend back into the baseline pattern.

### 1-Click Example Show Routines
Use the **Load Example Routine** dropdown to test fully orchestrated 90-second sequences:
- **🎭 90s Classic Routine (4-Phase Showcase):**
  - `0.0s – 30.0s`: Phase 1: Sampled Starlight Sparkle (Sampled artwork colors with starlight sparkle)
  - `30.0s – 60.0s`: Phase 2: Theatrical Breathing Glow (Gentle breathing pulse)
  - `60.0s – 75.0s`: Phase 3: Dynamic Traveling Chase Beam (8-LED white chasing beam)
  - `75.0s – 90.0s`: Phase 4: Solo Electrical Parade Wave (Traveling wave on dim background)
- **🎃 Cinderella 90s (Wheels & Lanterns):**
  - `0.0s – 25.0s`: Opening Starlight Sparkle (Global baseline)
  - `15.0s – 50.0s`: Carriage Wheels Spin (Group chase overlay)
  - `25.0s – 65.0s`: Royal Carriage Breathing Glow (Warm golden float glow)
  - `35.0s – 60.0s`: Carriage Lanterns Breathing Pulse (Group pulse overlay)
  - `60.0s – 90.0s`: Grand Finale Electrical Wave (Cascading electrical wave)
- **🐉 Pete's Dragon 90s (Crest Flame & Snout):**
  - `0.0s – 30.0s`: Comic Starlight Sparkle
  - `20.0s – 50.0s`: Flame Hair Crest Fire Pulse
  - `30.0s – 65.0s`: Snout Fire-Breathing Pulse
  - `65.0s – 90.0s`: Broadway Electrical Marquee Finale
- **🚂 Casey Jr. 90s (Pistons & Marquee):**
  - `0.0s – 25.0s`: Opening Steam & Sparkle (Sampled starlight)
  - `20.0s – 50.0s`: Piston Chug Acceleration (Locomotive pistons chugging at 144 BPM)
  - `45.0s – 75.0s`: Full Head of Steam Comet Sweep (180 BPM comet trail)
  - `70.0s – 90.0s`: Casey Jr. Circus Marquee Finale (Classic 144 BPM incandescent marquee)
- **🐢 Turtle & Snail 90s (Shell Spin & Ripple):**
  - `0.0s – 30.0s`: Enchanted Garden Pixie Dust (Gentle 90 BPM golden sparkle drift)
  - `25.0s – 60.0s`: Rotating Shell Spin (120 BPM concentric shell spin chase)
  - `55.0s – 80.0s`: Tidal Ripple Expansion (120 BPM concentric expanding wavefront)
  - `75.0s – 90.0s`: Rainbow Shell Spiral Finale (144 BPM vibrant chromatic wave)
- **🎆 America Grand Finale 90s (Fireworks & Marquee):**
  - `0.0s – 25.0s`: Red White & Blue Starlight (Steady patriotic sampled sparkle)
  - `20.0s – 50.0s`: Main Street Parade Wave (144 BPM traveling electrical wave)
  - `45.0s – 75.0s`: Grand Starburst Fireworks (140 BPM pyrotechnic explosions)
  - `70.0s – 90.0s`: Golden Age 1972 Theater Marquee (High-cadence 180 BPM grand finale chase)
- **🗑️ Clear All Cues:** Wipes the cue list clean so you can start from scratch.

---

## 10. Lighting Patterns & Effects Library

The simulator includes a unified library of 18 specialized algorithms available across Whole-Shirt Ambient (Tab 2), Group Creation & Docked Inspector (Tab 3), and Timed Show Cues (Tab 4):

| Effect ID | Effect Name | Description | Best Suited For |
|---|---|---|---|
| `chase` | **Chase / Wheel Spin** | Concentric or sequential single-point circulating chase with exponential decay wake. | Carriage wheels, train drivers, shell spirals |
| `pulse` / `color_match` | **Breathing Glow / Slo-Glo** | Organic sinusoidal breathing pulse that preserves true sampled artwork hues (~30-60 BPM). | Main float bodies, resting groups, warm accents |
| `write_on_off` | **Theatrical Write-On / Off** | Sequential progressive draw-on to full radiance, hold, and progressive wipe-off. | Entrances, flourish accents, musical wipes |
| `flash_slow` | **Slow Flashing / Blink** | Classical synchronized rhythmic on/off beacon blinking. | Headlights, signals, warning markers |
| `sparkle_storm` | **Sparkle Storm (Glitter)** | High-density diamond sparkle blizzard cascading across member LEDs. | Starbursts, pixie wands, climaxes |
| `steady_sparkle` | **Steady Colors + Sparkles** | Holds constant artwork color palette with occasional incandescent starlight twinkles. | Entry / ambient float scenes, resting baseline |
| `comet` | **Meteor / Comet Trail** | High-velocity white-hot comet head shooting along wiring/group perimeter with fading exponential tail. | Wheels, locomotive borders, shooting stars |
| `scanner` | **Larson Scanner (Ping-Pong Sweep)** | Dynamic back-and-forth beam sweep with smooth turnaround wakes and radiant core. | Cowls, dragon wings, sweeping searchlights |
| `color_wipe` | **Color Wipe / Progressive Fill** | 4-phase write-on fill along wiring path, radiant hold, wipe-off, and brief dark rest. | Float entrances, theatrical reveals |
| `pixie_dust` | **Pixie Dust Drift** | Shimmering starlight cascade combining traveling swell envelopes with diamond sparkle bursts. | Fairy wings, magic wands, musical crescendos |
| `filament_glow` | **Vintage 1972 Filament** | Analog micro-voltage warmth mimicking Walt Disney World's original 1972 incandescent bulbs. | Antique marquees, vintage Edison looks |
| `candle_flicker` | **Candle / Lantern Flame** | Warm amber/gold organic flame flicker with random multi-harmonic micro-jitter. | Carriage lanterns, torches, Elliott nostrils |
| `tidal_ripple` | **Tidal Ripple** | Outward-expanding and contracting concentric wavefront from group or float centroid. | Water ripples, shockwaves, radial pulses |
| `piston_chug` | **Locomotive Piston Chug** | 4-stroke mechanical cadence pulse with sharp power stroke and soft exhaust compression. | Casey Jr. boiler, train wheels, driving rhythms |
| `marquee` | **Theater Marquee Chase** | 3-phase alternating incandescent bulb chase (dots 1, 2, 3). | Outer float frames, title drum borders |
| `traveling_wave` | **Traveling Parade Wave** | Electrical parade wavefront cascading smoothly across the garment contour. | Grand finales, dynamic transitions |
| `fireworks` | **Fireworks Starburst** | 4-phase pyrotechnic explosion with center flash, outward expanding fire trails, and starlight tip crackle. | Finales, celestial bursts, chest stars |
| `rainbow_cycle` | **Rainbow Color Wave** | Flowing chromatic wave cycling across the strand or group contour. | Vibrant rainbow flourishes, electric transitions |
| `mouse_scamper` | **Scurrying Mouse (Single Dot + Tail)** | Single ultra-bright head dot darting smoothly across 2D space with a directional history tail showing where the mouse has scampered (no circular spotlight halo). | Whimsical character motion, playful roaming, high-energy flourishes |
| `flashlight` | **Flashlight / Searchlight Roam** | Continuous 2D roaming circular light pool sweeping across the float's sampled artwork like a focused searchlight. | Theatrical inspection, focused searchlights, nighttime reveals |
| `off` | **Off / Completely Unlit** | Complete blackout (0% intensity) for dramatic contrast, dormant stage cues, or unlit baseline. | Dark baseline, countdown blackouts, dormant groups |

### Ambient Baseline Tempo & Theatrical Cadence
Ambient baseline patterns operate with a calm, cinematic default tempo of **48 BPM** (adjustable from **20 to 180 BPM** via the Speed / Tempo slider in Tab 2).
- **Organic Breath Rate:** `Slo-Glo Breath` cycles at a relaxed 24 breaths/minute, mimicking a resting living creature rather than rapid strobing.
- **Continuous Directional Sweeps:** Larson scanners, comets, and tidal ripples respond proportionally to the tempo slider, allowing slow majestic glides or rapid theatrical flourishes.
- **Universal Blackout (`off`):** Selecting `🌑 All Off / Completely Dark` zeroes all LEDs with 0% current draw, enabling floats to begin dormant in total darkness until a cue or fleet routine wakes them.

### 2D Spatial Lighting Engine (Coordinate-Aware Animations)
In real-world garment wiring, LEDs are routed non-linearly across branches and contours to minimize wire tension and optimize slack. As a result, adjacent physical bulbs often have discontinuous electrical index numbers (e.g., LED #14 might sit physically next to LED #58).

To prevent animations from jumping erratically across wire branches, the simulator and firmware use a **2D Spatial Lighting Engine**:
- **Normalized Spatial Coordinates ($x, y$):** Every LED's 2D coordinate on the shirt is mapped into continuous spatial bounds.
- **Physical Progressive Fill (`color_wipe` / `write_on_off`):** Lights LEDs strictly in physical vertical order (bottom hem $\rightarrow$ chest $\rightarrow$ collar when `dir = 1`, or top-down when `dir = -1`), creating a smooth, organic fluid-fill effect regardless of electrical wiring route.
- **Directional Sweeps & Planar Waves (`traveling_wave`, `scanner`):** Larson scanner beams and traveling parade waves sweep smoothly across horizontal space along physical $X$ coordinates.
- **Centroid-Based Radial Waves (`tidal_ripple`):** Ripples expand outwardly from the true 2D physical centroid $(\bar{x}, \bar{y})$ of the float or group.
- **Zero-Overhead Microcontroller Optimization:** When flashing firmware or exporting C++, the spatial ranks and normalized coordinates are pre-computed into compact 8-bit PROGMEM flash lookup tables (`SPATIAL_RANK_Y`, `SPATIAL_X_BYTE`, `SPATIAL_Y_BYTE`, `SPATIAL_RADIUS_BYTE`). The ESP32 executes smooth 60 FPS spatial lighting sweeps with zero floating-point math overhead or memory allocation.

---

## 11. Decimal Sparkle Frequency & Starlight Twinkle

Authentic Disney parade floats use warm, incandescent filament bulbs that twinkle softly like distant stars. High sparkle rates can look like chaotic strobes.

### Fine Decimal Control (`0.0% – 10.0%`)
The **Sparkle Frequency Slider** in Section 3 supports fine decimal percentages with `0.05%` resolution:
- **`0.0%`:** Completely steady colors; zero sparkles.
- **`0.10% – 0.50%` (Recommended Starlight Twinkle):** An authentic, subtle starlight twinkle. Roughly 1 to 3 random LEDs sparkle every second across the entire costume.
- **`1.0% – 2.0%`:** A lively, playful sparkle suitable for active musical passages.
- **`5.0% – 10.0%`:** A fast-paced sparkle storm for grand finales.

*Firmware Note:* When exporting C++ code or flashing firmware, the engine uses 16-bit random thresholds (`random16()`), ensuring that decimal frequencies (like `0.25%`) translate with 100% mathematical fidelity to the microcontroller without rounding down to zero.

---

## 12. Float Management, Saving & JSON Import/Export

You can save and export complete float configurations so you never lose your LED arrangements, group definitions, or cue timelines.

### 📦 Master Fleet Parade Bundle (Export & Import All 7 Floats)
Beyond saving single float configurations, the simulator lets you export and import the **complete 7-float parade configuration** (all 7 costume float designs, LED coordinate placements, zone animation groups, standalone timeline cues, baseline ambient dynamics, and 30s fleet choreography blocks) in a single unified JSON file (`msep_fleet_parade_master.json`).

- **📥 Export Master Fleet Bundle:**
  - Authoritative location on the `🏃 Tab 5: Fleet` tab (Section 2: 7-Runner Baseline Presets & Master Fleet Suite via `📦 Export Fleet Bundle`).
  - Captures in-memory modifications from all 7 runner slots and current single-shirt editor states.
  - Generates a timestamped JSON bundle file (`msep_fleet_parade_master_YYYY-MM-DD.json`).
- **📂 Import Master Fleet Bundle with Selective-Float Modal:**
  - Click **`📂 Import Fleet Bundle`** on the Fleet tab to load any master parade JSON bundle.
  - An interactive **Import Confirmation Modal** appears displaying bundle metadata, export timestamp, parade title, and 30s choreography block count.
  - **Selective Checkbox Grid:** Select specific floats to overwrite (or use **Select All** / **Deselect All**), with real-time metrics showing LED counts, group counts, and standalone cues for each float in the bundle.
  - Toggle whether to import the master 30s fleet choreography blocks.
  - Integrated with the **Universal Undo / Redo Engine (`Ctrl+Z`)** so you can safely preview or revert applied bundles with one keystroke.

### Saving Floats (Layout Tab - Section 2) & Duplicate Protection
1. **Single Authoritative Location for Saving Floats:**
   - Float saving is consolidated strictly into **Section 2 (`💾 Save & Export Floats`)** on the Layout tab via **`💾 Save Float`** (`#saveProfileBtn`). Section 3 (`LED Layout & Wiring Route`) is kept clean for geometry and routing tools with a single `🔄 Reset Layout to Default` button.
   - Launches the dedicated **Save Float Configuration Modal** (`#savePresetModal`).
   - Displays real-time overview metrics: active float identity, physical canvas LED count (e.g. 50, 75, or 100), active animation group count, and sequenced theatrical cues.
   - **Timestamped Default Name:** The input box automatically populates with `<FloatName> <YYYY-MM-DD HH-mm>` (e.g., `Title Drum 2026-10-08 13-45`).
   - Shows live filename preview as you type (`Will save as: presets/<clean_name>.json`).
2. **Comprehensive Float State Capture:**
   - Every saved float captures:
     - Exact normalized $(x, y)$ coordinates and count of all LEDs on the canvas.
     - Sampled RGB colors, brightness, and ambient lighting parameters.
     - All float-specific animation groups (wheel rotations, rim chases, fireworks, dragon crest pulses).
     - Full theatrical show sequence cues (Parade Cue Director 90-second timeline).
     - Float metadata (float ID 1–7, name, role, tag, race bib number, accent color).
     - 3D armor plate parameters (selected plate size, width in mm, AMS filament color mappings).
3. **Duplicate File Checking & Rename Capability:**
   - The backend checks whether a preset with the target sanitized filename already exists in `presets/`.
   - If a duplicate is detected, the modal displays a red **⚠️ File Already Exists** banner with two options:
     - **Change Name:** Simply edit the float name in the input box; the filename preview updates live.
     - **⚠️ Overwrite Existing:** Click the red overwrite button to deliberately replace the file on disk.
4. **Dual Storage & Fleet Lineup Sync:**
   - Floats are saved to the server's `presets/` directory and backed up to browser `localStorage`.
   - Automatically links the saved float file to the active runner card slot in the 7-Shirt Fleet Lineup and refreshes the float selector dropdowns across the simulator.

### Exporting & Importing Configuration JSON
- **⬇ Download / Export Configuration JSON:**
  Click **"Export JSON"** (Section 2) or **"⬇ Export JSON"** (Section 3) to download a `.json` file containing the complete float configuration.
- **📂 Import Configuration JSON:**
  Click **"Import JSON"** and choose any previously saved `.json` file. The simulator instantly restores your LEDs, coordinates, groups, settings, and cues.

### Generating FastLED C++ Code
Click **"💻 Export FastLED C++ Code"** (Section 5) to open the code modal:
- Generates a complete C++ PROGMEM flash array storing the sampled color palette for all physical LEDs (`CRGB ARTWORK_PALETTE[NUM_LEDS]`).
- Auto-generates the `runAutonomousShowSequence` routine matching your active timeline cues.
- Click **"📋 Copy to Clipboard"** to paste directly into your Arduino or PlatformIO sketch!

## 13. 7-Shirt Fleet Show Creator & Preset Manager

The simulator includes a dedicated **7-Shirt Fleet Show Creator & Preset Manager** (Tab 5 in the sidebar navigation or via the top header's **"7-Shirt Fleet Lineup"** view toggle).

This feature coordinates costume profiles, LED mapping, and real-time animation synchronization across all 7 runners in the Main Street Electrical Parade fleet, while providing a powerful block-based choreography studio for authoring synchronized fleet routines.

### Baseline vs. One-Shot Fleet Routine Architecture
- **Baseline Mode (Default):** All 7 shirts continuously run their own independent float programs and animation groups (e.g., Casey Jr's spinning wheels, Cinderella's pumpkin coach flourishes, Elliott's breathing crest, patriotic starbursts).
- **One-Shot Fleet Routine Trigger:**
  - Clicking the prominent **"⚡ ACTIVATE 30s FLEET SHOW"** button (`#fleetShowActivateBtn`) or pressing the **`[Space]`** / **`[F]`** hotkeys triggers the synchronized fleet routine once.
  - The routine plays for its exact duration (e.g., 30.0 seconds), with a live phase countdown badge, active color pill indicator, and glowing canvas progress bar.
  - Upon completion, all 7 shirts automatically transition back to their regular individual float programs!
- **Early Stop / Exit:**
  - Clicking the button while the fleet show is active (which transforms into a pulsing red **"⏹ STOP FLEET SHOW (EARLY RETURN)"** button), pressing `[Space]` / `[F]`, or tapping the physical ESP32 BOOT button immediately stops the routine and returns all 7 shirts to their baseline programs.
- **Visual Rendering Cleanliness:** During fleet routine playback, all color transitions, waves, pulses, and sparkle storms are rendered strictly through the discrete addressable LED nodes on the costumes. Outer rectangular card frames and glowing bounding boxes around each shirt are omitted during playback to prevent visual clutter and keep total focus on the costume lighting.
- **Debounce Protection:**
  - The activation button and keyboard hotkeys enforce a **300ms software debounce lockout** in the simulator to prevent accidental double-triggers.
  - The physical ESP32 firmware enforces a **50ms hardware debounce** and **300ms inter-press lockout**.

---
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

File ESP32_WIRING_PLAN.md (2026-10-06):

# 🔌 ESP32 Hardware Wiring Plan & Electrical Specification
## Main Street Electrical Parade (WDW 10K) Synchronized LED Costumes

This document provides the definitive, bench-tested electrical wiring specification for the wearable ESP32 LED controllers powering our 7-runner family fleet for the Walt Disney World 10K.

---

## 1. System Overview & Component BOM

Each runner wears a self-contained, battery-powered lighting system controlling **200 addressable LEDs** (100 front chest pixels + 100 back pixels duplicated in real time):

| Component | Specification | Quantity per Runner | Notes |
| :--- | :--- | :---: | :--- |
| **Microcontroller** | ESP32-WROOM-32D / DevKit V1 (30-pin or 38-pin) | 1 | 240 MHz dual-core, onboard 2.4GHz antenna for ESP-NOW. |
| **Addressable LEDs** | WS2812B 5V "Seed / Pebble" RGBIC fairy light strings | 200 LEDs (2× 100) | Black enameled/insulated 3-conductor wire, ~1" to 2" spacing. |
| **Inline Data Resistor** | 220 Ω to 470 Ω, 1/4W resistor | 1 | Prevents voltage ringing/spikes on GPIO 16 data output. |
| **Tactile Buttons** | Momentary pushbuttons (SPST normally-open) | 2 | **Button 1:** Show Director / Wake<br>**Button 2:** Castle Photo / Sleep |
| **Power Source** | 5V USB portable power bank ($\ge 2.1\text{A}$ output, 5,000–20,000 mAh) | 1 | FastLED firmware limited to **5V, 2000mA (2.0A)** max. |
| **Power Cable** | Heavy-gauge USB-A to stripped 2-wire cable (or USB-C) | 1 | 20 AWG or 22 AWG power leads for minimal voltage drop. |
| **Connectors** | 3-pin JST-SM (Data, 5V, GND) or quick-disconnect terminals | 1–2 sets | Allows disconnecting the shirt from the electronics pouch. |

---

## 2. Complete ESP32 Pinout Assignment Table

```
                         ESP32 DevKit V1 (30-pin)
                              ┌─────────┐
                        3V3 ──┤         ├── VIN  <── +5V (From Power Bank)
                        GND ──┤         ├── GND  <── Common GND (Battery + LEDs + Buttons)
         (Show/Wake) GPIO 4 ──┤         ├── GPIO 13
                     GPIO 0 ──┤         ├── GPIO 12
                     GPIO 2 ──┤         ├── GPIO 14
                    GPIO 15 ──┤         ├── GPIO 27
                    GPIO 18 ──┤         ├── GPIO 26
                    GPIO 19 ──┤         ├── GPIO 25
                    GPIO 21 ──┤         ├── GPIO 33 ──> (Photo/Sleep) Button 2
                    GPIO 22 ──┤         ├── GPIO 32
                    GPIO 23 ──┤         ├── GPIO 35
                              └─────────┘
                                  │
                                GPIO 16 (Pin 8 right on 30-pin DevKit)
                                  │
                               [220Ω - 470Ω Resistor]
                                  │
                                  ▼
                            LED Data-In (DI)
```

| ESP32 Pin | Function | Wiring Connection | Electrical Configuration |
| :---: | :--- | :--- | :--- |
| **GPIO 16** | **LED Data Output** | In series with **220 Ω to 470 Ω resistor** $\rightarrow$ First LED Data-In (`DIN` / `DI`). | High-speed digital RMT / SPI output (FastLED driver). |
| **GPIO 4** | **Button 1 (Show Director / Wake)** | One pin to **GPIO 4**, other pin to **GND**. | Software `INPUT_PULLUP`. Reads `LOW` when pressed. |
| **GPIO 33** | **Button 2 (Castle Photo / Sleep)** | One pin to **GPIO 33**, other pin to **GND**. | Software `INPUT_PULLUP`. Reads `LOW` when pressed. |
| **GPIO 0** | **Onboard BOOT Button** | Onboard button on ESP32 DevKit (bench fallback). | Software `INPUT_PULLUP`. Operates in parallel with Button 1. |
| **GPIO 2** | **Status Indicator** | Built-in onboard blue LED. | Output: Pulses during show triggers, boot, and config. |
| **VIN / 5V** | **Primary DC Power Input** | +5V Red wire from USB Power Bank. | Powers ESP32 internal 3.3V LDO regulator and LEDs. |
| **GND** | **System Common Ground** | Connected together: ESP32 GND, Power Bank GND, LED GND, and both Button GNDs. | **Mandatory:** All components MUST share a common ground! |

---

## 3. System Electrical Schematic

```
               ┌────────────────────────────────────────────────────────┐
               │              PORTABLE USB POWER BANK                   │
               │                  (+5V DC, >= 2.1A)                     │
               └───────────────────┬────────────────┬───────────────────┘
                                   │ +5V (RED)      │ GND (BLACK)
                                   │                │
            ┌──────────────────────┴───────┐        │
            │                              │        │
            ▼                              ▼        │
    ┌──────────────┐              ┌───────────────┐ │
    │ ESP32 DevKit │              │  200-LED STRIP│ │
    │              │              │  POWER RAILS  │ │
    │   VIN / 5V ◄─┼──────────────┤ +5V           │ │
    │              │              │               │ │
    │        GND ◄─┼──────────────┼─ GND ◄────────┴─┼────────────────────────┐
    │              │              │               │                          │
    │    GPIO 16 ──┼─[220Ω-470Ω]─►│ DATA-IN (DI)  │                          │
    │              │              └───────────────┘                          │
    │              │                                                         │
    │     GPIO 4 ──┼───────┐                                                 │
    │ (Button 1)   │       │                                                 │
    │              │    ┌──┴──┐  Momentary Pushbutton                        │
    │              │    │ O O │  (Show Director / Wake)                      │
    │              │    └──┬──┘                                              │
    │              │       └─────────────────────────────────────────────────┤
    │              │                                                         │
    │    GPIO 33 ──┼───────┐                                                 │
    │ (Button 2)   │       │                                                 │
    │              │    ┌──┴──┐  Momentary Pushbutton                        │
    │              │    │ O O │  (Castle Photo / Sleep)                      │
    │              │    └──┬──┘                                              │
    │              │       └─────────────────────────────────────────────────┘
    └──────────────┘
```

---

## 4. 4-Pin Tactile Pushbutton Orientation Guide (Preventing Stuck Boots!)

> [!CAUTION]
> **Common Assembly Mistake:** Standard 6×6mm breadboard pushbuttons have **4 pins**, but only **2 electrical terminals**. The opposite pins along each wide side are permanently connected internally.

```
       CORRECT WIRING (Diagonal or True Opposites):
       
              Pin 1-A ┌──────┐ Pin 1-B  (Internally connected!)
                      │  ●   │
              Pin 2-A └──────┘ Pin 2-B  (Internally connected!)
              
       ✔ WIRE TO: Pin 1-A (GPIO) and Pin 2-A (GND)  <-- Switches when pressed!
       ❌ DO NOT WIRE TO: Pin 1-A and Pin 1-B       <-- Permanent short to GND!
```

* **The Problem:** If you wire across the internally shorted pair (e.g. Pin 1-A to GPIO and Pin 1-B to GND), the pin is held `LOW` permanently from the microsecond power is connected!
* **Firmware Protection Built-In:** The firmware contains a startup safety guard (`b1Armed` / `b2Armed`). If a pin is shorted to GND at boot, the firmware logs a warning and disables the hold timer rather than locking the costume in config mode.
* **Best Practice:** Use a multimeter in continuity mode (beep test) to verify that your two leads only beep when the button is physically clicked down! Clip or bend inward the two unused legs to prevent accidental shorts.

---

## 5. 200-LED Front & Back Topology & Daisy-Chaining

All firmware builds duplicate the front 100 chest LEDs to the back 100 LEDs in real time so the runner is illuminated from 360° along the dark Disney course:

```
  ESP32 GPIO 16 ──► [220Ω Resistor]
                          │
                          ▼
            ┌───────────────────────────┐
            │   FRONT CHEST STRAND      │
            │   LED 000 ────────► LED 099 │
            └─────────────┬─────────────┘
                          │ Data Out of LED 099
                          ▼
            ┌───────────────────────────┐
            │    BACK SHIRT STRAND      │
            │   LED 100 ────────► LED 199 │
            └───────────────────────────┘
```

### Power Injection Guidelines:
- **Voltage Drop:** Seed/pebble fairy light wire has thin conductors. Powering 200 LEDs from a single end can cause the last 30–50 LEDs to look slightly dim or reddish during white peaks.
- **T-Tap Power Bus (Recommended):** Run the +5V and GND wires in parallel directly from the battery harness to **BOTH** the start of the front strip (LED 0) and the start of the back strip (LED 100). The data line remains continuous in series (GPIO 16 $\rightarrow$ LED 0..99 $\rightarrow$ LED 100..199).

---

## 6. Bench Power Isolation Rules (Mandatory Computer Safety!)

> [!IMPORTANT]
> When uploading code or monitoring serial output via USB-C from a laptop or desktop computer:
> 1. **DISCONNECT THE BATTERY PACK:** Never plug a portable power bank into the VIN/5V rail while the ESP32 is also plugged into a computer via USB cable.
> 2. **Current Limiting:** Computer USB ports typically supply 500mA to 900mA. The ESP32 and a single test strand of LEDs will run fine for testing, but do not set full-white bursts on computer USB.
> 3. **Race Morning:** Plug only the 5V portable power bank into the costume harness. The ESP32 boots autonomously in ~1.5 seconds directly into Corral Standby Mode.

---

## 7. FastLED Power Budget & Battery Life Verification

The firmware enforces FastLED hardware power capping:
```cpp
FastLED.setMaxPowerInVoltsAndMilliamps(5, 2000); // 5V, 2.0A max limit
```

* **Quiescent Draw:** ESP32 radio active + 200 LED sleep twinkle = **~120 mA** (~0.6W).
* **Parade Baseline Draw:** Animated float programs average **~620–780 mA** (~3.5W).
* **Peak Show Draw:** 30s synchronized fleet show peaks at **~1,100–1,200 mA** (~6.0W).
* **Battery Endurance (10,000 mAh / 37 Wh Power Bank):**
  - **Delivered 5V Capacity:** ~7,000 mAh (accounting for 70% boost conversion efficiency).
  - **90-minute Corral Sleep:** $1.5\text{ hr} \times 120\text{ mA} = 180\text{ mAh}$.
  - **90-minute 10K Race Run:** $1.5\text{ hr} \times 750\text{ mA} = 1,125\text{ mAh}$.
  - **Total Consumed:** ~1,305 mAh out of 7,000 mAh available (**> 80% battery remaining at the finish line!**).

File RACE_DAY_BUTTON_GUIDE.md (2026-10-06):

# 🏃🏰 Race Day Button Field Guide & Controller Cheat Sheet
## Main Street Electrical Parade (WDW 10K) Synchronized LED Costumes

This pocket-friendly field manual explains the complete dual-button control scheme for our **7-runner family team** on race morning at the Walt Disney World 10K.

---

## 1. Quick Pocket Cheat Sheet

```
   ┌────────────────────────────────────────────────────────┐
   │                  RUNNER CONTROLLER                     │
   │                                                        │
   │    [ BUTTON 1: SHOW DIRECTOR ]     [ BUTTON 2: PHOTO ] │
   │           (GPIO 4 / BOOT)               (GPIO 33)      │
   │                                                        │
   │    • TAP: Wake / Fleet Show        • TAP: Castle Photo │
   │    • DOUBLE TAP: Roll Call         • HOLD 3s: Sleep    │
   │    • HOLD 5s: Float ID Config                          │
   └────────────────────────────────────────────────────────┘
```

---

## 2. Leader vs. Follower Roles & Lineup

| Float # | Character | Hero Colors | Runner Role | Button Authority |
| :---: | :--- | :--- | :---: | :--- |
| **01** | **The Train (Casey Jr.)** | 🔴 Warm Red, Amber, Cyan | **👑 PRIMARY LEADER** | **Full Fleet Control:** Master clock, wake all floats, trigger 30s fleet show, fleet photo mode, fleet sleep. |
| **02** | **The Title Drum** | 🟡 Gold, White, Red | 👥 Follower | **Local Control Only:** Local wake, local photo mode, local sleep. Show cues locked to Leader. |
| **03** | **The Turtle** | 🟢 Teal, Emerald, Warm White | 👥 Follower | **Local Control Only:** Local wake, local photo mode, local sleep. Show cues locked to Leader. |
| **04** | **The Snail** | 🌸 Pink, Orange, Yellow | 👥 Follower | **Local Control Only:** Local wake, local photo mode, local sleep. Show cues locked to Leader. |
| **05** | **Cinderella's Coach** | 🩵 Cyan, Pumpkin Gold, Pink | 👥 Follower | **Local Control Only:** Local wake, local photo mode, local sleep. Show cues locked to Leader. |
| **06** | **Pete's Dragon (Elliott)** | 🟢 Emerald scales, Violet, Orange | 👥 Follower | **Local Control Only:** Local wake, local photo mode, local sleep. Show cues locked to Leader. |
| **07** | **To Honor America** | 🔵 Patriotic Blue, White, Red | **🦅 CO-LEADER / REAR** | **Full Co-Leader Authority:** Commands rear pack if runners split during the race. |

---

## 3. Actionable Button Matrix (Race Day Verified)

### 👑 Leaders (**Float 1: Casey Jr.** & **Float 7: Flag & Eagle**)

| Button & Gesture | Current State | What Happens | Visual / Serial Confirmation |
| :--- | :--- | :--- | :--- |
| **Button 1 — Single Tap** (< 600ms) | 🌙 In Sleep (Standby) | ☀️ **Wakes ENTIRE FLEET** into **Solo Show Mode** (individual float animations). Tap again to start fleet show. | 🟢 Emerald green flash on all floats. |
| **Button 1 — Single Tap** (< 600ms) | 📸 In Castle Photo Mode | ☀️ **Exits Photo Mode and wakes fleet** into **Solo Show Mode**. | 🟢 Emerald green flash, starts parade. |
| **Button 1 — Single Tap** (< 600ms) | 🏃 Running in Solo Show | 🎆 **Launches 30-Second Synchronized Fleet Routine** across all 7 floats simultaneously. | 👑 Synchronized choreography blocks. |
| **Button 1 — Single Tap** (< 600ms) | 🎬 30s Show Active | ⏹ **Stops Fleet Routine early**, cleanly returning fleet to Solo Show Mode. | 🟠 Amber double-flash confirmation. |
| **Button 1 — Double Tap** (< 400ms) | 🏃 Running Awake | ⚡ **Triggers 4-Second Rapid Attendance Roll Call Wave** sequentially from Float 1 to Float 7. | 500ms hero color wave down the pack + green finale flash. |
| **Button 1 — Hold 5s** *(White meter)* | Any State | ⚪ **Enters Float ID Configuration Mode** (reassign role 1–7 in the corral). | 1s–4s white charging meter $\rightarrow$ ⚪ 3 white flashes. |
| **Button 2 — Single Tap** (< 600ms) | 🌙 In Sleep (Standby) | 📸 **Lights up ENTIRE FLEET in Castle Photo Mode** (full graphic colors). Tap again to return to sleep. | 100% steady, solid multi-color illumination. |
| **Button 2 — Single Tap** (< 600ms) | 📸 In Castle Photo Mode | 🌙 **Toggles back to previous state** (returns to Sleep if from Sleep; returns to Parade if from Show). | Returns to previous mode with zero fuss. |
| **Button 2 — Single Tap** (< 600ms) | 🏃 Running in Solo Show | 📸 **Locks ENTIRE FLEET into Castle Photo Mode** for high-shutter group photos. Tap again to resume parade. | 100% steady, solid multi-color illumination. |
| **Button 2 — Hold 3s** *(Blue meter)* | Any State | 🌙 **Drops ENTIRE FLEET into Corral Standby Mode** (<120mA). Holding $>3\text{s}$ stays locked in sleep! | 1s–2s blue meter $\rightarrow$ 🔵 3 soft indigo pulses. |

---

### 👥 Followers (**Floats 2 to 6**: Title Drum, Turtle, Snail, Cinderella, Pete's Dragon)

| Button & Gesture | Current State | What Happens | Visual / Serial Confirmation |
| :--- | :--- | :--- | :--- |
| **Button 1 — Single Tap** (< 600ms) | 🌙 In Sleep (Standby) | ☀️ **Wakes THIS COSTUME ONLY** into **Solo Show Mode** (does NOT trigger fleet show). | 🟢 Emerald green flash on your shirt. |
| **Button 1 — Single Tap** (< 600ms) | 📸 In Castle Photo Mode | ☀️ **Exits Photo Mode locally** into **Solo Show Mode**. | 🟢 Emerald green flash, starts parade. |
| **Button 1 — Single Tap** (< 600ms) | 🏃 Running Awake | 🛡️ **IGNORED:** Prevents family runners from accidentally disrupting parade show. | Animation continues smoothly without glitch. |
| **Button 1 — Double Tap** (< 400ms) | Any State | 🛡️ **IGNORED:** Roll Call broadcast is reserved for Leader. | No action. |
| **Button 1 — Hold 5s** *(White meter)* | Any State | ⚪ **Enters Float ID Configuration Mode** (reassign role 1–7 in the corral). | 1s–4s white charging meter $\rightarrow$ ⚪ 3 white flashes. |
| **Button 2 — Single Tap** (< 600ms) | 🌙 In Sleep (Standby) | 📸 **Lights up THIS COSTUME in Castle Photo Mode** (full graphic colors). Tap again to return to sleep. | 100% steady, solid multi-color illumination. |
| **Button 2 — Single Tap** (< 600ms) | 📸 In Castle Photo Mode | 🌙 **Toggles back to previous state** (returns to Sleep if from Sleep; returns to Parade if from Show). | Returns to previous mode with zero fuss. |
| **Button 2 — Single Tap** (< 600ms) | 🏃 Running in Solo Show | 📸 **Locks THIS COSTUME into Castle Photo Mode** for individual character photos. | 100% steady, solid multi-color illumination. |
| **Button 2 — Hold 3s** *(Blue meter)* | Any State | 🌙 **Drops THIS COSTUME ONLY into Corral Standby Mode** (<120mA). Holding $>3\text{s}$ stays locked in sleep! | 1s–2s blue meter $\rightarrow$ 🔵 3 soft indigo pulses. |

---

## 4. State Flow Diagram

```mermaid
stateDiagram-v2
    [*] --> Standby: Plug in USB Battery @ 3:30 AM
    
    state "🌙 Corral Standby Mode (Sleep)" as Standby {
        twinkle: 12% Dim Starlight Twinkle (< 120mA)
    }
    
    state "📸 Castle Photo Mode" as Photo {
        solid: 100% Steady Full-Color Graphic Artwork (No Flicker)
    }
    
    state "🏃 Solo Show Mode (Parade)" as Solo {
        parade: Autonomous Animated Character Floats
    }
    
    state "🎆 30-Second Theatrical Fleet Routine" as Fleet {
        sync: Wireless ESP-NOW Choreography Across All 7 Shirts
    }
    
    state "⚪ Float ID Config Mode" as Config {
        config: Tap Button 1 to cycle 1-7, 4s auto-save
    }

    Standby --> Photo: Button 2 Tap (Quick photo in corral)
    Photo --> Standby: Button 2 Tap (Returns to sleep!)
    Photo --> Solo: Button 1 Tap (Wakes into parade show!)
    
    Standby --> Solo: Button 1 Tap (Wake to parade)
    Solo --> Standby: Button 2 Hold 3s (Lock into sleep)
    Photo --> Standby: Button 2 Hold 3s (Lock into sleep)
    
    Solo --> Photo: Button 2 Tap (Photo stop along course)
    Photo --> Solo: Button 2 Tap (Resumes parade!)
    
    Solo --> Fleet: Leader Button 1 Tap
    Fleet --> Solo: 30s Timeout or Leader Button 1 Tap
    
    Standby --> Config: Button 1 Hold 5s
    Solo --> Config: Button 1 Hold 5s
    Config --> Solo: Auto-Save (4 Green Flashes)
```

---

## 5. Chronological Race Morning Playbook

### 🕞 3:30 AM — Hotel Departure & Bus Staging
1. Plug the USB battery pack into your ESP32 controller.
2. The costume boots autonomously into **🌙 Corral Standby Mode** within 1.5 seconds.
3. Verify that your chest display shows a very dim, subtle midnight starlight twinkle drawing **< 120mA**.
4. Leave the costumes in Standby while on the race bus and walking to the staging area to conserve 80%+ battery.

### 🕓 4:15 AM — Starting Corral & Pre-Race Attendance Check
1. Line up with the family in Float order:
   - **01:** 🚂 Train $\rightarrow$ **02:** 🥁 Drum $\rightarrow$ **03:** 🐢 Turtle $\rightarrow$ **04:** 🐌 Snail $\rightarrow$ **05:** 🩵 Cinderella $\rightarrow$ **06:** 🐉 Dragon $\rightarrow$ **07:** 🦅 America
2. **Leader Attendance Roll Call:** Float 1 double-taps **Button 1**.
   - Watch the wave ripple smoothly down the line from Float 1 to Float 7 (500ms per runner) and end with the double emerald green flash!
3. **Pre-Race Castle/Epcot Photos:** Tap **Button 2** once.
   - All shirts glow in full, bright, vibrant graphic artwork colors with 100% steady illumination.
   - Snap crisp, motion-blur-free team photos with Disney PhotoPass photographers.
   - Tap **Button 2** again to return immediately to battery-saving Standby!

### 🕔 5:00 AM — National Anthem & Start Wave Release
1. As the start wave approaches the launch arch, Float 1 single-taps **Button 1**.
2. All 7 costumes wake simultaneously into **🏃 Solo Show Mode** with a triumphant emerald green confirmation flash.
3. Every runner's shirt is now alive with its signature float animations (spinning wheels, flickering fire breath, chugging locomotive steam, sparkling carriages)!

### 🏃 During the 10K Course (Miles 1 to 6.2)
1. **Spectator Crowds & Overpasses:** Float 1 single-taps **Button 1** while running to trigger the dazzling **🎆 30-Second Synchronized Fleet Routine**.
2. **Disney PhotoPass Stops (In front of the Castle or Spaceship Earth):**
   - Tap **Button 2** to instantly freeze the fleet in **📸 Castle Photo Mode**.
   - Pose and smile for the camera!
   - Tap **Button 2** (or tap **Button 1**) to instantly resume the animated parade!

### 🏁 Post-Race & Finish Line Celebration
1. After collecting your runDisney 10K medals, hold **Button 2 for 3 seconds**.
2. All costumes drop back into **🌙 Corral Standby Mode** to celebrate at the post-race family reunion area without blinding fellow runners!

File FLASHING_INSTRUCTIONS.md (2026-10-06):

# ⚡ Quick Flashing Guide for Family Runners & Crew
### How to flash your ESP32 with the latest parade costume firmware in under 60 seconds

Hey everyone! If you just want to flash your ESP32 board without learning Git, Google Antigravity, or dealing with complex toolchains, this guide gives you **3 easy ways to do it**.

---

## 📥 Step 0: Download the Files (No Git or GitHub Account Needed!)

You **do not need Git installed** and you **do not need to make a repository** on your computer. You can download everything as a standard `.zip`:

1. Go to the project page: **[https://github.com/kidmd/WDW-costumes](https://github.com/kidmd/WDW-costumes)**
2. Click the green **`<> Code`** button (near the top-right) and click **`Download ZIP`**.
3. Right-click the downloaded `WDW-costumes-main.zip` file and select **`Extract All...`** (extract to any folder, like your Desktop or Downloads).
4. Plug in your ESP32 with a USB data cable, open the extracted folder, and choose your preferred flashing method below!

---

## 🚀 Method 1: The One-Click Double-Click Script (Fastest & Recommended)

No compiling, no Arduino IDE, no software configuration needed! We already pre-compiled the latest ROM binaries into the `firmware/` folder.

### On Windows:
1. Connect your ESP32 to your computer using a USB data cable.
2. Double-click **`flash_firmware.bat`** in the main project folder.
3. Press any key when prompted.
4. The script will automatically detect your ESP32 and flash the firmware in ~15 seconds.

### On Mac / Linux:
1. Connect your ESP32 via USB.
2. Double-click **`flash_firmware.command`** *(or run `./flash_firmware.command` in Terminal)*.
3. Press Enter and it flashes automatically.

> 💡 **Tip:** If the terminal says `Connecting........_____.....`, **press and hold the onboard "BOOT" button on the ESP32 for 2 seconds** until it starts writing!

---

## 🌐 Method 2: Zero-Install Web Browser Flasher (Chrome or Edge)

You can flash the ESP32 directly from your web browser using HTML5 Web Serial — **zero software or drivers to install**! You can even pick which specific runner float role you want to bake into the board:

1. Connect your ESP32 to your computer via a USB data cable.
2. Open **Google Chrome** or **Microsoft Edge**.
3. With the simulator running (`python simulator.py`), go to:
   ```
   http://localhost:8000/web_flasher.html
   ```
   *(Or click the green **"⚡ Web Flasher"** link in the top-right header of the Costume Simulator).*
4. Click on your assigned **Float Card** (e.g. 🚂 **Float 1: The Train**, 🥁 **Float 2: The Title Drum**, 🐉 **Float 6: Pete's Dragon**, etc.).
   - The flasher will automatically arm the dedicated firmware image for that character and role!
5. Click the green **"⚡ Connect & Flash Float X"** button.
6. In the browser pop-up window, select your ESP32 port (usually labeled *CP2102*, *CH340*, or *USB Serial*) and click **Connect**.
7. Click **Install** and watch the progress bar reach 100%! The board automatically reboots with that float's identity pre-configured in flash memory.

---

## 🛠️ Method 3: Arduino IDE (If You Want to Edit the Code)

If you're already familiar with the Arduino IDE and want to inspect or modify the code:

1. Open the Arduino sketch located at:
   ```
   arduino/MSEP_Costume/MSEP_Costume.ino
   ```
2. **Install FastLED Library:**
   - In Arduino IDE, click **Sketch ➔ Include Library ➔ Manage Libraries...**
   - Search for `FastLED` (by Daniel Garcia) and click **Install**.
3. **Select Board:**
   - Go to **Tools ➔ Board ➔ esp32 ➔ ESP32 Dev Module**.
   *(If you don't have the ESP32 board package installed, go to Tools ➔ Board ➔ Boards Manager, search for `esp32` by Espressif, and click Install. The sketch automatically detects and supports **both ESP32 Arduino Core 2.x and Core 3.x+** without code changes).*
4. **Select Port & Upload:**
   - Go to **Tools ➔ Port** and select your connected ESP32 COM port.
   - Click the **Upload** arrow button in the top toolbar!

---

## 💻 Method 4: PlatformIO / VS Code (For Developers)

If you have VS Code with the PlatformIO extension:
1. Open this project folder in VS Code.
2. Connect your ESP32.
3. Open a terminal and run:
   ```bash
   pio run -t upload
   ```

---

## 🔌 Hardware & Costume Operation Guide

Once your board is flashed:

### Pinout Connections & Wiring:
- **LED Data In (DIN):** Connects to **GPIO 16** (8th pin down on the right of standard ESP32 DevKits).
  - *Data Resistor:* A 220 Ω to 470 Ω resistor inline between GPIO 16 and LED DIN is recommended.
- **Button 1 (Primary Show Director):** Connect momentary tactile push button between **GPIO 4** and **GND** (internal `INPUT_PULLUP`, zero resistors needed).
  - *Note:* The onboard **BOOT button (GPIO 0)** remains active in software in parallel with Button 1 for easy bench testing!
- **Button 2 (Auxiliary / Photo & Sleep):** Connect momentary tactile push button between **GPIO 33** and **GND** (internal `INPUT_PULLUP`, zero resistors needed).
- **LED String Configuration:** Pre-configured for **200 LEDs** (100 Front + 100 Back duplicated) for full 360° visibility and battery life testing.
- **Power:** Connect a 5V USB battery bank (2.1A+ rated) to the ESP32's USB port or `5V` and `GND` pins (firmware is clamped to 2000 mA via FastLED power limiting for safety).

```
                            ┌───────────────────────────┐
                            │    ESP32 DEV CONTROLLER   │
                            └─────────────┬─────────────┘
                                          │
             ┌────────────────────────────┴────────────────────────────┐
             ▼                                                         ▼
    ┌─────────────────────────────────┐                       ┌─────────────────────────────────┐
    │      BUTTON 1 (PRIMARY)         │                       │      BUTTON 2 (AUXILIARY)       │
    │     GPIO 4 (or BOOT GPIO 0)     │                       │            GPIO 33              │
    │   "Parade Show Director"        │                       │     "Photo & Standby Switch"    │
    ├─────────────────────────────────┤                       ├─────────────────────────────────┤
    │ Pin: GPIO 4 ──[ Switch ]── GND  │                       │ Pin: GPIO 33 ──[ Switch ]── GND │
    │ Mode: INPUT_PULLUP (No resistor)│                       │ Mode: INPUT_PULLUP (No resistor)│
    └─────────────────────────────────┘                       └─────────────────────────────────┘
```

### Complete Button Gestures & Role Matrix:

| Button & Gesture | 🚂 Float 1 & Float 7 (Leader Role) | 🐌 Floats 2–6 (Follower Role) |
| :--- | :--- | :--- |
| **Button 1 — Single Tap** (< 600ms) | **If in Sleep:** Wakes ENTIRE FLEET into **Solo Show Mode** (baseline parade animations).<br>**If Awake:** Launches **30s Fleet Show Routine** (tap again during show for early stop). | **If in Sleep:** Wakes LOCALLY to **Solo Show Mode** (does NOT start fleet show).<br>**If Awake:** Toggles local sequence. |
| **Button 1 — Double Tap** (< 400ms) | ⚡ Triggers **4-Second Rapid Attendance Roll Call Wave** across entire fleet. | 💡 Ignored (Roll call wave broadcast reserved for Leader). |
| **Button 1 — Long Hold (5s)**<br>*(1s–4s white charging meter)* | ⚪ Enters **Float ID Configuration Mode** (⚪ 3 white flashes, tap to cycle Floats 1–7, 🟢 4 green auto-save flashes on 4s timeout). | ⚪ Enters **Float ID Configuration Mode** (⚪ 3 white flashes, tap to cycle Floats 1–7, 🟢 4 green auto-save flashes on 4s timeout). |
| **Button 2 — Single Tap** (< 600ms) | 📸 Puts **ENTIRE FLEET** into **Castle Photo Mode** (solid, 100% steady, zero-flicker glow). Tap again to resume parade. | 📸 Puts **LOCAL COSTUME** into **Castle Photo Mode** (solid steady glow). Tap again to resume parade. |
| **Button 2 — Double & Triple Tap** | ❌ **Disabled** (No action). | ❌ **Disabled** (No action). |
| **Button 2 — Long Hold (3s)**<br>*(1s–2s soft blue meter)* | 🌙 Puts **ENTIRE FLEET** into **Corral Standby / Sleep Mode** (broadcasts `0x50` standby packet). | 🌙 Puts **LOCAL COSTUME** into **Corral Standby / Sleep Mode**. |

---

## 🎛️ Setting Your Float Number (1 to 7) & Role (Leader / Follower)

You do **not** need to change any code to configure which float you are! Any ESP32 can be set to any float in the parade lineup using **Button 1 (GPIO 4 or BOOT GPIO 0)**, and your board permanently remembers its number in flash memory even when powered off.

### How to Configure:
1. **Hold Button 1 for 5 seconds:**
   - **Progressive Charging Meter (1s – 4s):** As you hold, crisp white LEDs light up one-by-one at each second mark (1s: 1 LED, 2s: 2 LEDs, 3s: 3 LEDs, 4s: 4 LEDs). If accidentally pressed, simply let go anytime before 5s to cancel cleanly back to normal baseline!
   - **Enter Config Mode (5s):** The LEDs will flash **white 3 times** to signal you have entered Configuration Mode.
2. **Read the Current Float Number:**
   - Look at the start of your LED strip: the first **N pixels** will light up in that float's signature color!
   - (If you don't have the LED strip plugged in, the onboard Blue LED blinks N times repeatedly).
3. **Tap Button 1 to cycle:**
   - Each short tap advances to the next float: `1 ➔ 2 ➔ 3 ➔ 4 ➔ 5 ➔ 6 ➔ 7 ➔ 1`.
4. **Auto-Save & Exit:**
   - Once you reach your float, **leave the button alone for 4 seconds**.
   - The LEDs will flash **green 4 times** to confirm it is saved!

### The 7-Runner Fleet Lineup:

| Float # | Float Name | Character Tag | Signature Color | Role |
|:---:|---|---|---|:---:|
| **01** | **The Train** | CASEY JR. | 🔴 Red | **👑 PRIMARY LEADER** (Pulls the Drum & Broadcasts timing clock) |
| **02** | **The Title Drum** | THE DRUM | 🟡 Gold / Amber | Follower |
| **03** | **The Turtle** | SPINNING TURTLE | 🟢 Teal / Green | Follower |
| **04** | **The Snail** | SPINNING SNAIL | 🌸 Pink | Follower |
| **05** | **Cinderella's Coach** | CINDERELLA | 🔵 Cyan | Follower |
| **06** | **Pete's Dragon** | ELLIOTT | 🟢 Green | Follower |
| **07** | **To Honor America** | FLAG & EAGLE | 🔴⚪🔵 Patriotic Blue | **🦅 CO-LEADER / REAR MARSHAL** (Full show & standby authority) |

> 💡 **Dual-Leader Architecture:** Float 01 is the **Primary Master Leader** (front of the pack) and Float 07 is the **Co-Leader / Rear Marshal** (rear of the pack). If the runners split on the course, Float 07 can command the rear pack independently; when running together, Float 01 takes master precedence!

## ❓ Troubleshooting

| Issue | Quick Fix |
|---|---|
| **Board not detected / no COM port** | 1. Ensure your cable is a **USB data cable** (many cheap phone cables only carry power, not data).<br>2. Install the standard USB-to-UART driver for your chip ([CP210x Driver](https://www.silabs.com/developers/usb-to-uart-bridge-vcp-drivers) or [CH340 Driver](https://sparks.gogo.co.nz/ch340.html)). |
| **Flashing gets stuck on "Connecting..."** | Press and hold the **BOOT button** on the ESP32 board for 2 seconds while the script is connecting, then release it. |
| **LEDs stay dark after flashing** | Verify LED strand direction (data must flow from the ESP32 into the arrow/input end of the WS2812B string, not the output end). |
| **Colors look swapped (e.g. green instead of red)** | WS2812B strands use `RGB` or `GRB` color order. The firmware is calibrated for `RGB` by default. |

---
*Questions or need a different float preset? Check `SIMULATOR_USER_GUIDE.md`.*  
*Heading out for race weekend? Make sure to review the complete **[`RACE_DAY_PACKING_CHECKLIST.md`](RACE_DAY_PACKING_CHECKLIST.md)** for power bank readiness, spare ESP32s, and corral countdown procedures!*

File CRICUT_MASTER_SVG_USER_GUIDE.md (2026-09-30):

# ✂️ Cricut Master SVG Cut Guide for MSEP Mesh Pinnie Costumes
### Step-by-Step Instructions for Cricut Design Space (Brother's Quick-Start Guide)

This guide walks through exactly how to take the exported **Master SVG file** (e.g., `petes_dragon_cricut_full_artwork_with_6x3mm_slots.svg` or any float's cut file) and cut it on a Cricut machine with pre-aligned $6.0\,\text{mm} \times 3.0\,\text{mm}$ LED pill holes.

---

## 🛠️ What You Need
1. **Cricut Machine:** Cricut Explore (3 / Air 2) or Cricut Maker (3 / original).
2. **Cricut Design Space:** Official software on Mac or PC (free).
3. **Materials:**
   - **Heat Transfer Vinyl (HTV / Iron-On):** 
     - Mat 1: Emerald Green (Body)
     - Mat 2: Hot Pink / Magenta (Hair, Wings, & Spines)
     - *(Optional White/Orange for details depending on float)*
   - **Cricut StandardGrip Mat** (Green mat).
   - **Weeding Hook / Tweezers**.
   - **Heat Press / Home Iron / Cricut EasyPress** + Parchment Paper or Teflon Sheet.
   - **Mesh Pinnie Running Vest**.

---

## 📋 Step-by-Step Cricut Workflow

### Step 1: Upload the SVG File
1. Open **Cricut Design Space** on your computer and start a **New Project**.
2. Click the **Upload** button on the left sidebar, then click **Upload Image**.
3. Drag & drop the downloaded `petes_dragon_cricut_full_artwork_with_6x3mm_slots.svg` file (or click Browse to locate it).
4. Click **Upload** to save it to your library, select the thumbnail, and click **Add to Canvas**.

---

### Step 2: Set the Final Chest Width
1. With the design selected on the canvas, check the top toolbar for **Width (W)** and **Height (H)**.
2. Ensure the padlock icon between Width and Height is **LOCKED** (keeps the artwork proportional).
3. Set the **Width to ~7.2 inches** (or whatever chest width fits the mesh vest). Cricut will automatically adjust the height proportionally (~10.2 inches), and all 100 pill slots will scale in exact alignment.

---

### Step 3: Organize & "Attach" the Cutouts (The Most Important Step!)
When the SVG loads, Cricut sees distinct layers in the **Layers Panel** on the right:
- **`Layer_1_Green_Vinyl`:** Green Body & Legs
- **`Layer_2_Pink_Vinyl`:** Pink Hair Crest, Wings & Spines
- **`Layer_LED_Pill_Slots_6x3mm`:** The 100 Pill Slots ($6\times 3\,\text{mm}$)
- **`Layer_0_Registration_Crosshairs`:** 4-Corner alignment marks

**To ensure Cricut cuts the holes directly into the vinyl shapes:**
1. Click **Ungroup** at the top of the Layers panel to separate the groups.
2. Select the **Green Body** layer and the **Green Pill Slots**, then click the **Attach** (paperclip icon) at the bottom of the Layers panel. *(This locks the holes to the green vinyl so the blade cuts them out of the green sheet in their exact spots).*
3. Select the **Pink Features** (hair/wings/spines) and the **Pink Pill Slots**, then click **Attach**.

---

### 🎯 Pro-Tip: How the 4-Corner Alignment Markers Work (Registration Marks)

The 4 crosshairs in the corners (`Layer_0_Registration_Crosshairs`) are optional but give you **sub-millimeter layering precision**:

#### 1. Does the Cricut Machine Scan Them?
- **No optical scanning is needed.** The Cricut blade physically cuts 4 tiny crosshairs into the corners of each vinyl sheet if you attach them to your layers.

#### 2. The 2 Big Benefits:
- **Prevents Cricut Scrambling Pieces:** If you attach the 4 corner marks to the Pink layer AND to the Green layer, Cricut will not try to pack the pink pieces into the top corner to save material. It preserves the exact spacing between the pink hair up top and the pink tail spines at the bottom!
- **Zero-Guesswork Heat Pressing:**
  1. When pressing the **Green Body**, place a tiny piece of blue painter's tape or heat-resistant tape under each of the 4 corner crosshairs on the vest. Press for 10s. The green crosshairs will stick to the tape (not the shirt).
  2. When pressing the **Pink Accents**, simply look through the clear carrier sheet and line up the **pink crosshairs directly on top of the green crosshairs on the tape**.
  3. All hair, wings, and spines will snap into perfect anatomical alignment. Peel off the tape and crosshairs when finished!

*(Note: If your brother prefers to eyeball the alignment naturally, simply click the **eye icon** next to `Layer_0_Registration_Crosshairs` in Cricut Design Space to hide them before clicking Make It).*

---

### Step 4: Click "Make It" & Mirror for HTV / Iron-On
1. Click the green **Make It** button in the top-right corner.
2. Cricut will automatically sort the project onto **2 Cutting Mats**:
   - **Mat 1 (Green):** Green Body with its pre-aligned holes.
   - **Mat 2 (Pink):** Pink Hair, Wings, and Spines with their pre-aligned holes.
3. ⚠️ **CRITICAL HTV RULE:** On the left mat preview screen, **turn the "Mirror" toggle ON for EVERY mat!** 
   *(Heat transfer vinyl is always cut face-down through the adhesive side, so mirroring ensures it faces the correct way when ironed onto the shirt).*

---

### Step 5: Cut and Weed
1. Place the **Green HTV** onto your green Cricut grip mat, **SHINY CLEAR PLASTIC CARRIER SHEET DOWN** (matte vinyl facing UP).
2. Select **Everyday Iron-On** or **SportFlex Iron-On** as your material in Design Space.
3. Load the mat into the Cricut and press the flashing **Go (Cricut Logo)** button.
4. When finished, unload the mat and repeat for the **Pink HTV** mat.
5. **Weed the Vinyl:** Use your weeding tool or tweezers to peel away the excess background vinyl **and pop out the tiny 6×3mm pill slots**. You will be left with the clean vinyl shapes on the clear carrier sheet, with the pill slots completely cut out!

---

### Step 6: Iron / Heat Press onto the Mesh Vest
1. Lay the mesh pinnie vest flat on an ironing board or heat press mat.
2. **First Press (Green Base):**
   - Place the green body on the chest (approx. 2" below the neckline).
   - Cover with parchment paper or a Teflon sheet.
   - Press with an EasyPress or home iron at **305°F–315°F (150°C–155°C)** for **10–12 seconds** with medium pressure.
   - Let cool slightly (warm peel) and peel off the clear plastic carrier sheet.
3. **Second Press (Pink Accents):**
   - Lay the pink hair crest, wings, and tail spines over the green body (they overlap naturally in their exact registration spots).
   - Cover with parchment paper and press for **10–12 seconds**.
   - Peel off the clear plastic carrier sheet.
4. **Final Cure Press:** Cover the entire completed graphic with parchment paper and press firmly for **15 seconds** to permanently fuse the vinyl into the polyester mesh.

---

## 🧵 Step 7: Weaving the 100-LED Fairy Light Strand
Once the vinyl is ironed on:
1. **Start from the Inside:** Pass the LED strand starting near the lower-left hem / waist where the battery pack will sit.
2. **Weave Each LED:** 
   - Push the resin pebble LED from **inside the shirt ➔ through the mesh & vinyl pill slot ➔ to the outside**.
   - Lay the LED flat in the slot.
   - Push the wire **back into the next hole ➔ to the inside of the shirt** to travel behind the vest to the next position.
3. **Result:** All 100 LEDs shine brightly on the outside of the shirt with zero visible wire clutter on the front, and the flexible mesh pinnie remains lightweight, breathable, and comfortable for the 10K run!

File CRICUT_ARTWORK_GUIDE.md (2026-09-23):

# 🎨 Cricut Heat Transfer Vinyl (HTV) Costume Artwork Guide
### Vector Design Suite for Main Street Electrical Parade (WDW 10K Costumes)

This guide details the complete vector artwork suite designed specifically for cutting with a **Cricut** (Maker, Explore, or Joy Xtra) or **Silhouette** vinyl cutter.

All designs are clean, multi-layered SVG cut files with zero microscopic islands, ensuring easy weeding and durable adhesion on stretchy, moisture-wicking technical running shirts.

---

## 📁 File Locations & Visual Catalog

All cut files are located in the repository at:
```
assets/cricut_svg/
├── casey_jr_train.svg          (Float 01 - The Train / Casey Jr.)
├── title_drum.svg              (Float 02 - The Title Drum)
├── spinning_turtle.svg         (Float 03 - The Spinning Turtle)
├── spinning_snail.svg          (Float 04 - The Spinning Snail)
├── cinderella_coach.svg        (Float 05 - Cinderella's Coach)
├── petes_dragon.svg            (Float 06 - Pete's Dragon / Elliott)
├── honor_america_eagle.svg     (Float 07 - To Honor America / Flag & Eagle)
└── cricut_catalog.html         (Interactive Visual Catalog & Color Mat Inspector)
```
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

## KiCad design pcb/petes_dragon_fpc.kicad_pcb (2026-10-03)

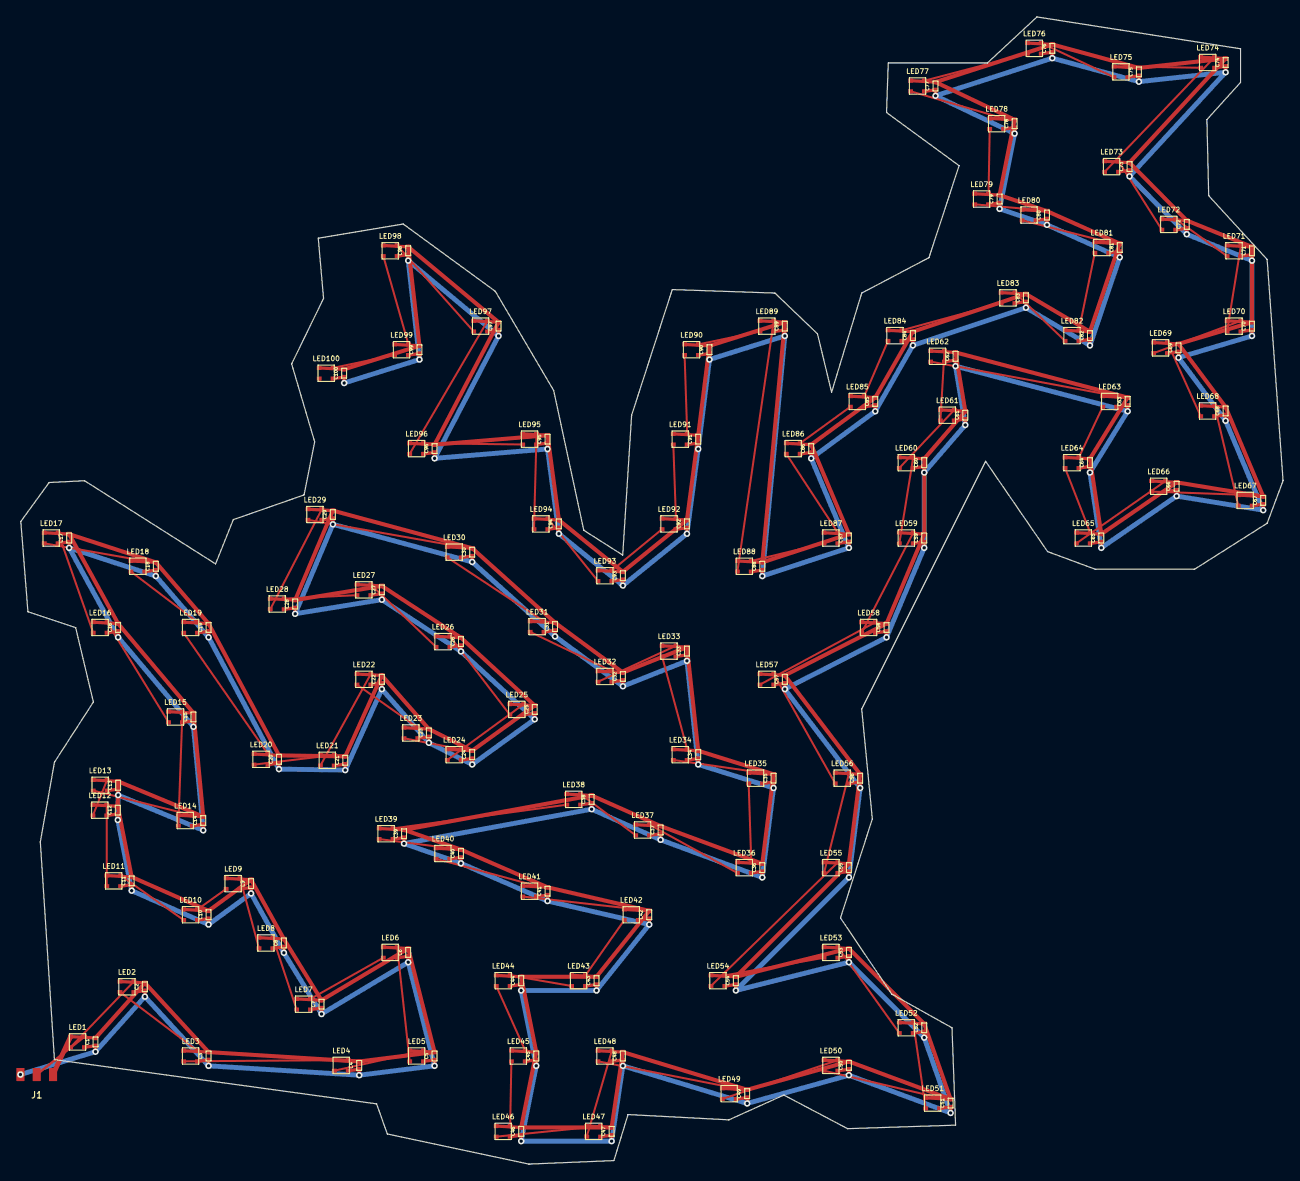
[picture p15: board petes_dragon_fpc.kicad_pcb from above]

Board: 2 copper layers, 154.6 x 140.5 mm, 201 parts (0 on the bottom side), 102 nets.

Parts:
C1, C2, C3, C4, C5, C6, C7, C8, C9, C10, C11, C12, C13, C14, C15, C16, C17, C18, C19, C20, C21, C22, C23, C24, C25, C26, C27, C28, C29, C30, C31, C32, C33, C34, C35, C36, C37, C38, C39, C40, C41, C42, C43, C44, C45, C46, C47, C48, C49, C50, C51, C52, C53, C54, C55, C56, C57, C58, C59, C60, C61, C62, C63, C64, C65, C66, C67, C68, C69, C70, C71, C72, C73, C74, C75, C76, C77, C78, C79, C80, C81, C82, C83, C84, C85, C86, C87, C88, C89, C90, C91, C92, C93, C94, C95, C96, C97, C98, C99, C100: 100nF; C_0402_1005Metric
J1: JST-PH-3P; JST_PH_S3B-PH-SM4-TB_1x03-1MP_P2.00mm_Horizontal
LED1, LED2, LED3, LED4, LED5, LED6, LED7, LED8, LED9, LED10, LED11, LED12, LED13, LED14, LED15, LED16, LED17, LED18, LED19, LED20, LED21, LED22, LED23, LED24, LED25, LED26, LED27, LED28, LED29, LED30, LED31, LED32, LED33, LED34, LED35, LED36, LED37, LED38, LED39, LED40, LED41, LED42, LED43, LED44, LED45, LED46, LED47, LED48, LED49, LED50, LED51, LED52, LED53, LED54, LED55, LED56, LED57, LED58, LED59, LED60, LED61, LED62, LED63, LED64, LED65, LED66, LED67, LED68, LED69, LED70, LED71, LED72, LED73, LED74, LED75, LED76, LED77, LED78, LED79, LED80, LED81, LED82, LED83, LED84, LED85, LED86, LED87, LED88, LED89, LED90, LED91, LED92, LED93, LED94, LED95, LED96, LED97, LED98, LED99, LED100: WS2812B-2020; LED_WS2812B_PLCC4_2.0x2.0mm

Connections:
+5V: C1.1, C2.1, C3.1, C4.1, C5.1, C6.1, C7.1, C8.1, C9.1, C10.1, C11.1, C12.1, C13.1, C14.1, C15.1, C16.1, C17.1, C18.1, C19.1, C20.1, C21.1, C22.1, C23.1, C24.1, C25.1, C26.1, C27.1, C28.1, C29.1, C30.1, C31.1, C32.1, C33.1, C34.1, C35.1, C36.1, C37.1, C38.1, C39.1, C40.1, C41.1, C42.1, C43.1, C44.1, C45.1, C46.1, C47.1, C48.1, C49.1, C50.1, C51.1, C52.1, C53.1, C54.1, C55.1, C56.1, C57.1, C58.1, C59.1, C60.1, C61.1, C62.1, C63.1, C64.1, C65.1, C66.1, C67.1, C68.1, C69.1, C70.1, C71.1, C72.1, C73.1, C74.1, C75.1, C76.1, C77.1, C78.1, C79.1, C80.1, C81.1, C82.1, C83.1, C84.1, C85.1, C86.1, C87.1, C88.1, C89.1, C90.1, C91.1, C92.1, C93.1, C94.1, C95.1, C96.1, C97.1, C98.1, C99.1, C100.1, J1.1, LED1.1, LED2.1, LED3.1, LED4.1, LED5.1, LED6.1, LED7.1, LED8.1, LED9.1, LED10.1, LED11.1, LED12.1, LED13.1, LED14.1, LED15.1, LED16.1, LED17.1, LED18.1, LED19.1, LED20.1, LED21.1, LED22.1, LED23.1, LED24.1, LED25.1, LED26.1, LED27.1, LED28.1, LED29.1, LED30.1, LED31.1, LED32.1, LED33.1, LED34.1, LED35.1, LED36.1, LED37.1, LED38.1, LED39.1, LED40.1, LED41.1, LED42.1, LED43.1, LED44.1, LED45.1, LED46.1, LED47.1, LED48.1, LED49.1, LED50.1, LED51.1, LED52.1, LED53.1, LED54.1, LED55.1, LED56.1, LED57.1, LED58.1, LED59.1, LED60.1, LED61.1, LED62.1, LED63.1, LED64.1, LED65.1, LED66.1, LED67.1, LED68.1, LED69.1, LED70.1, LED71.1, LED72.1, LED73.1, LED74.1, LED75.1, LED76.1, LED77.1, LED78.1, LED79.1, LED80.1, LED81.1, LED82.1, LED83.1, LED84.1, LED85.1, LED86.1, LED87.1, LED88.1, LED89.1, LED90.1, LED91.1, LED92.1, LED93.1, LED94.1, LED95.1, LED96.1, LED97.1, LED98.1, LED99.1, LED100.1
DATA_1: J1.2, LED1.4
DATA_2: LED1.2, LED2.4
DATA_3: LED2.2, LED3.4
DATA_4: LED3.2, LED4.4
DATA_5: LED4.2, LED5.4
DATA_6: LED5.2, LED6.4
DATA_7: LED6.2, LED7.4
DATA_8: LED7.2, LED8.4
DATA_9: LED8.2, LED9.4
DATA_10: LED9.2, LED10.4
DATA_11: LED10.2, LED11.4
DATA_12: LED11.2, LED12.4
DATA_13: LED12.2, LED13.4
DATA_14: LED13.2, LED14.4
DATA_15: LED14.2, LED15.4
DATA_16: LED15.2, LED16.4
DATA_17: LED16.2, LED17.4
DATA_18: LED17.2, LED18.4
DATA_19: LED18.2, LED19.4
DATA_20: LED19.2, LED20.4
DATA_21: LED20.2, LED21.4
DATA_22: LED21.2, LED22.4
DATA_23: LED22.2, LED23.4
DATA_24: LED23.2, LED24.4
DATA_25: LED24.2, LED25.4
DATA_26: LED25.2, LED26.4
DATA_27: LED26.2, LED27.4
DATA_28: LED27.2, LED28.4
DATA_29: LED28.2, LED29.4
DATA_30: LED29.2, LED30.4
DATA_31: LED30.2, LED31.4
DATA_32: LED31.2, LED32.4
DATA_33: LED32.2, LED33.4
DATA_34: LED33.2, LED34.4
DATA_35: LED34.2, LED35.4
DATA_36: LED35.2, LED36.4
DATA_37: LED36.2, LED37.4
DATA_38: LED37.2, LED38.4
DATA_39: LED38.2, LED39.4
DATA_40: LED39.2, LED40.4
DATA_41: LED40.2, LED41.4
DATA_42: LED41.2, LED42.4
DATA_43: LED42.2, LED43.4
DATA_44: LED43.2, LED44.4
DATA_45: LED44.2, LED45.4
DATA_46: LED45.2, LED46.4
DATA_47: LED46.2, LED47.4
DATA_48: LED47.2, LED48.4
DATA_49: LED48.2, LED49.4
DATA_50: LED49.2, LED50.4
DATA_51: LED50.2, LED51.4
DATA_52: LED51.2, LED52.4
DATA_53: LED52.2, LED53.4
DATA_54: LED53.2, LED54.4
DATA_55: LED54.2, LED55.4
DATA_56: LED55.2, LED56.4
DATA_57: LED56.2, LED57.4
DATA_58: LED57.2, LED58.4
DATA_59: LED58.2, LED59.4
DATA_60: LED59.2, LED60.4
DATA_61: LED60.2, LED61.4
DATA_62: LED61.2, LED62.4
DATA_63: LED62.2, LED63.4
DATA_64: LED63.2, LED64.4
DATA_65: LED64.2, LED65.4
DATA_66: LED65.2, LED66.4
DATA_67: LED66.2, LED67.4
DATA_68: LED67.2, LED68.4
DATA_69: LED68.2, LED69.4
DATA_70: LED69.2, LED70.4
DATA_71: LED70.2, LED71.4
DATA_72: LED71.2, LED72.4
DATA_73: LED72.2, LED73.4
DATA_74: LED73.2, LED74.4
DATA_75: LED74.2, LED75.4
DATA_76: LED75.2, LED76.4
DATA_77: LED76.2, LED77.4
DATA_78: LED77.2, LED78.4
DATA_79: LED78.2, LED79.4
DATA_80: LED79.2, LED80.4
DATA_81: LED80.2, LED81.4
DATA_82: LED81.2, LED82.4
DATA_83: LED82.2, LED83.4
DATA_84: LED83.2, LED84.4
DATA_85: LED84.2, LED85.4
DATA_86: LED85.2, LED86.4
DATA_87: LED86.2, LED87.4
DATA_88: LED87.2, LED88.4
DATA_89: LED88.2, LED89.4
DATA_90: LED89.2, LED90.4
DATA_91: LED90.2, LED91.4
DATA_92: LED91.2, LED92.4
DATA_93: LED92.2, LED93.4
DATA_94: LED93.2, LED94.4
DATA_95: LED94.2, LED95.4
DATA_96: LED95.2, LED96.4
DATA_97: LED96.2, LED97.4
DATA_98: LED97.2, LED98.4
DATA_99: LED98.2, LED99.4
DATA_100: LED99.2, LED100.4
GND: C1.2, C2.2, C3.2, C4.2, C5.2, C6.2, C7.2, C8.2, C9.2, C10.2, C11.2, C12.2, C13.2, C14.2, C15.2, C16.2, C17.2, C18.2, C19.2, C20.2, C21.2, C22.2, C23.2, C24.2, C25.2, C26.2, C27.2, C28.2, C29.2, C30.2, C31.2, C32.2, C33.2, C34.2, C35.2, C36.2, C37.2, C38.2, C39.2, C40.2, C41.2, C42.2, C43.2, C44.2, C45.2, C46.2, C47.2, C48.2, C49.2, C50.2, C51.2, C52.2, C53.2, C54.2, C55.2, C56.2, C57.2, C58.2, C59.2, C60.2, C61.2, C62.2, C63.2, C64.2, C65.2, C66.2, C67.2, C68.2, C69.2, C70.2, C71.2, C72.2, C73.2, C74.2, C75.2, C76.2, C77.2, C78.2, C79.2, C80.2, C81.2, C82.2, C83.2, C84.2, C85.2, C86.2, C87.2, C88.2, C89.2, C90.2, C91.2, C92.2, C93.2, C94.2, C95.2, C96.2, C97.2, C98.2, C99.2, C100.2, J1.3, LED1.3, LED2.3, LED3.3, LED4.3, LED5.3, LED6.3, LED7.3, LED8.3, LED9.3, LED10.3, LED11.3, LED12.3, LED13.3, LED14.3, LED15.3, LED16.3, LED17.3, LED18.3, LED19.3, LED20.3, LED21.3, LED22.3, LED23.3, LED24.3, LED25.3, LED26.3, LED27.3, LED28.3, LED29.3, LED30.3, LED31.3, LED32.3, LED33.3, LED34.3, LED35.3, LED36.3, LED37.3, LED38.3, LED39.3, LED40.3, LED41.3, LED42.3, LED43.3, LED44.3, LED45.3, LED46.3, LED47.3, LED48.3, LED49.3, LED50.3, LED51.3, LED52.3, LED53.3, LED54.3, LED55.3, LED56.3, LED57.3, LED58.3, LED59.3, LED60.3, LED61.3, LED62.3, LED63.3, LED64.3, LED65.3, LED66.3, LED67.3, LED68.3, LED69.3, LED70.3, LED71.3, LED72.3, LED73.3, LED74.3, LED75.3, LED76.3, LED77.3, LED78.3, LED79.3, LED80.3, LED81.3, LED82.3, LED83.3, LED84.3, LED85.3, LED86.3, LED87.3, LED88.3, LED89.3, LED90.3, LED91.3, LED92.3, LED93.3, LED94.3, LED95.3, LED96.3, LED97.3, LED98.3, LED99.3, LED100.3

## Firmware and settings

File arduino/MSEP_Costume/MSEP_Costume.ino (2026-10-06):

#include <Arduino.h>
#include <FastLED.h>
#include <WiFi.h>
#include <WiFiUdp.h>
#include <esp_now.h>
#include <esp_arduino_version.h>
#include <Preferences.h>
#include "soc/soc.h"
#include "soc/rtc_cntl_reg.h"

#if __has_include("costume_config.h")
#include "costume_config.h"
#endif

#if __has_include("float_config.h")
#include "float_config.h"
#endif

#if __has_include("wifi_config.h")
#include "wifi_config.h"
#endif

#if __has_include("fleet_palettes.h")
#include "fleet_palettes.h"
#endif

// ============================================================================
// HARDWARE & PIN DEFINITIONS
// ============================================================================
#define DATA_PIN            16      // 8th pin down on the right
#define LED_TYPE            WS2812B
#ifndef COLOR_ORDER
#define COLOR_ORDER         RGB     // Calibrated hardware color order (Red, Green, Blue)
#endif
#define STATUS_LED_PIN      2       // Onboard Blue LED

#ifndef FRONT_LEDS
#define FRONT_LEDS          100     // 100 LEDs on front of costume shirt
#endif

#ifndef BACK_LEDS
#define BACK_LEDS           100     // 100 LEDs on back of costume shirt
#endif

#ifndef NUM_LEDS
#define NUM_LEDS            200     // 200 total LEDs (100 front + 100 back)
#endif
#define MAX_LEDS_CAPACITY   256     // Buffer capacity supporting 200 LEDs
#ifndef MAX_BRIGHTNESS
#define MAX_BRIGHTNESS      60      // Bench/wearable safe brightness
#endif
#define MAX_MILLIAMPS       2000    // 2.0A limit for 200 LEDs on wearable power bank

CRGB leds[MAX_LEDS_CAPACITY];

// Duplicate front 100 LEDs to back 100 LEDs so entire 200-LED costume illuminates identically
inline void duplicateFrontToBack() {
    for (int i = 0; i < FRONT_LEDS && (FRONT_LEDS + i) < NUM_LEDS && (FRONT_LEDS + i) < MAX_LEDS_CAPACITY; i++) {
        leds[FRONT_LEDS + i] = leds[i];
    }
}

Preferences preferences;

// 7-Runner Fleet Metadata & Signature Colors
struct FloatMeta {
    const char* name;
    const char* tag;
    CRGB color;
};

const FloatMeta FLEET_ROSTER_INFO[7] = {
    { "The Train",      "LEADER",     CRGB(230, 40, 50)   }, // Float 1 (Red)
    { "Title Drum",     "FOLLOWER",   CRGB(255, 180, 20)  }, // Float 2 (Gold/Amber)
    { "The Turtle",     "FOLLOWER",   CRGB(40, 200, 180)  }, // Float 3 (Teal)
    { "The Snail",      "FOLLOWER",   CRGB(255, 20, 140)  }, // Float 4 (Pink)
    { "Cinderella",     "FOLLOWER",   CRGB(50, 180, 240)  }, // Float 5 (Cyan)
    { "Pete's Dragon",  "FOLLOWER",   CRGB(0, 255, 100)   }, // Float 6 (Green)
    { "Flag & Eagle",   "FOLLOWER",   CRGB(60, 120, 255)  }  // Float 7 (Patriotic Blue)
};

// ============================================================================
// WI-FI & UDP LIVE STREAMING STATE
// ============================================================================
WiFiUDP udp;
bool isLiveStreaming = false;
uint32_t lastStreamPacketTime = 0;

#ifndef UDP_STREAM_PORT
#define UDP_STREAM_PORT 4210
#endif

// ============================================================================
// KNOWN MAC ADDRESSES FOR THE FLEET (Milestone 2)
// ============================================================================
const char* MAC_LEADER_FLOAT1   = "B0:CB:D8:C8:49:84"; // Board 1: The Train (Leader)
const char* MAC_FOLLOWER_FLOAT2 = "A4:F0:0F:64:33:A0"; // Board 2: Title Drum (Follower)

struct __attribute__((packed)) ParadeSyncPacket {
    uint8_t  magic;          // 0xEE verification byte
    uint8_t  mode;           // 0: Marquee, 1: Sparkle, 2: Twinkle, 3: Traveling Wave
    uint32_t masterMillis;   // Synchronized timebase (ms)
    uint8_t  activeFloat;    // For traveling wave (1 to 7)
    uint8_t  waveHead;       // 0-49 pixel position of traveling wave
};

ParadeSyncPacket currentPacket;
bool isLeader = false;
uint8_t myFloatNumber = 2;

volatile bool packetReceived = false;
uint32_t lastPacketTime = 0;
uint32_t localSyncTime = 0;
uint32_t lastLocalTick = 0;

uint8_t broadcastMac[] = {0xFF, 0xFF, 0xFF, 0xFF, 0xFF, 0xFF};

// HARDWARE BUTTON DEFINITIONS
#define BUTTON_1_PIN        4       // Primary Show Director button (External tact switch to GND)
#define BUTTON_2_PIN        33      // Auxiliary Photo / Sleep button (External tact switch to GND)
#define BUTTON_BOOT_PIN     0       // BOOT button on standard ESP32 DevKit (Fallback in parallel with Button 1)
#define SHOW_LOOP_MS        90000   // 90-second autonomous theatrical sequence
#define FLEET_ROUTINE_TOTAL_MS 30000 // Auto-updated for 30s Grand Electrical Parade Show (30.0s)
#define RAPID_ROLL_CALL_TOTAL_MS 4000 // 4.0-second Rapid Attendance Roll Call (500ms x 7 floats + 500ms unison finale)

enum StandaloneShowMode {
    SHOW_MODE_AUTONOMOUS_SEQUENCE = 0,
    SHOW_MODE_FLEET_SYNC          = 1,
    SHOW_MODE_FLEET_30S_ROUTINE   = 2,
    SHOW_MODE_RAPID_ROLL_CALL     = 3,
    SHOW_MODE_CORRAL_STANDBY      = 4,
    SHOW_MODE_PHOTO_STATIC        = 5   // 📸 Castle Photo Mode: solid steady hero illumination
};

inline bool isButton1Down() {
    return (digitalRead(BUTTON_1_PIN) == LOW) || (digitalRead(BUTTON_BOOT_PIN) == LOW);
}

inline bool isButton2Down() {
    return (digitalRead(BUTTON_2_PIN) == LOW);
}

StandaloneShowMode currentStandaloneMode = SHOW_MODE_CORRAL_STANDBY;
StandaloneShowMode previousStandaloneMode = SHOW_MODE_AUTONOMOUS_SEQUENCE;
uint32_t fleetRoutineStartTime = 0;
uint8_t fleetRoutineCycle = 0;
uint32_t rapidRollCallStartTime = 0;
uint32_t autonomousShowStartTime = 0;

void broadcastFleetRoutinePacket(uint8_t mode, uint32_t masterMillis) {
    ParadeSyncPacket packet;
    packet.magic = 0xEE;
    packet.mode = mode; // 0x30 = Start/Sync 30s Routine, 0x00 = Stop early, 0x50 = Standby, 0x51 = Wake
    packet.masterMillis = masterMillis;
    packet.activeFloat = myFloatNumber;
    packet.waveHead = 0;
    esp_now_send(broadcastMac, (uint8_t*)&packet, sizeof(packet));
}

void broadcastStandbyPacket(uint8_t mode) {
    ParadeSyncPacket packet;
    packet.magic = 0xEE;
    packet.mode = mode; // 0x50 = Standby, 0x51 = Wake
    packet.masterMillis = millis();
    packet.activeFloat = myFloatNumber;
    packet.waveHead = 0;
    esp_now_send(broadcastMac, (uint8_t*)&packet, sizeof(packet));
}

void broadcastPhotoModePacket(uint8_t mode) {
    ParadeSyncPacket packet;
    packet.magic = 0xEE;
    packet.mode = mode; // 0x46 = Photo Mode ON, 0x47 = Photo Mode OFF
    packet.masterMillis = millis();
    packet.activeFloat = myFloatNumber;
    packet.waveHead = 0;
    esp_now_send(broadcastMac, (uint8_t*)&packet, sizeof(packet));
}

void renderCastlePhotoMode() {
    uint8_t floatIdx = (myFloatNumber >= 1 && myFloatNumber <= 7) ? (myFloatNumber - 1) : 0;

#if defined(HAS_CUSTOM_PALETTE) && HAS_CUSTOM_PALETTE
    #if defined(COMPILED_FLOAT_ID)
    if (myFloatNumber == COMPILED_FLOAT_ID) {
        for (int i = 0; i < FRONT_LEDS && i < MAX_LEDS_CAPACITY; i++) {
            leds[i] = ARTWORK_PALETTE[i];
        }
        duplicateFrontToBack();
        return;
    }
    #else
    for (int i = 0; i < FRONT_LEDS && i < MAX_LEDS_CAPACITY; i++) {
        leds[i] = ARTWORK_PALETTE[i];
    }
    duplicateFrontToBack();
    return;
    #endif
#endif

#if defined(HAS_DEFAULT_FLOAT_PALETTES) && HAS_DEFAULT_FLOAT_PALETTES
    for (int i = 0; i < FRONT_LEDS && i < MAX_LEDS_CAPACITY; i++) {
        leds[i] = DEFAULT_FLOAT_PALETTES[floatIdx][i];
    }
#else
    CRGB heroColor = FLEET_ROSTER_INFO[floatIdx].color;
    fill_solid(leds, FRONT_LEDS, heroColor);
#endif

    duplicateFrontToBack();
}

void renderCorralStandby(uint32_t t) {
    // Ultra-low power starlight shimmer (<120mA draw) with visible midnight float-glow
    uint8_t floatIdx = (myFloatNumber >= 1 && myFloatNumber <= 7) ? (myFloatNumber - 1) : 0;
    CRGB baseColor = FLEET_ROSTER_INFO[floatIdx].color;
    
    // Clearly visible deep midnight base glow (25% float color)
    CRGB dimBase = CRGB(
        max((int)(baseColor.r * 0.25), 10),
        max((int)(baseColor.g * 0.25), 10),
        max((int)(baseColor.b * 0.25), 10)
    );
    fill_solid(leds, FRONT_LEDS, dimBase);

    // Calm, very slow (~5s period), sparse starlight twinkle on ~5% of LEDs
    CRGB subtleWarm = CRGB(
        min(255, dimBase.r + 45),
        min(255, dimBase.g + 38),
        min(255, dimBase.b + 20)
    );

    for (int i = 0; i < FRONT_LEDS; i++) {
        uint8_t wave = sin8((t / 20) + (i * 47)); // very slow (~5.1s cycle), scattered pixels
        if (wave > 242) { // only top ~5% peak
            uint8_t blendAmt = (wave - 242) * 19; // 0..247 smooth ramp
            leds[i] = blend(dimBase, subtleWarm, blendAmt);
        }
    }
}

// ============================================================================
// PRE-RACE CORRAL ROLL CALL & RADAR IDENTIFY FLASH
// ============================================================================
void triggerIdentifyFlash() {
    uint8_t fIdx = (myFloatNumber >= 1 && myFloatNumber <= 7) ? (myFloatNumber - 1) : 0;
    CRGB color = FLEET_ROSTER_INFO[fIdx].color;
    Serial.printf("[RADAR] ✨ Identify Flash triggered for Float %d: %s (%s)!\n", 
                  myFloatNumber, FLEET_ROSTER_INFO[fIdx].name, FLEET_ROSTER_INFO[fIdx].tag);
    for (int f = 0; f < 3; f++) {
        fill_solid(leds, NUM_LEDS, color);
        FastLED.show();
        digitalWrite(STATUS_LED_PIN, HIGH);
        delay(120);
        fill_solid(leds, NUM_LEDS, CRGB::Black);
        FastLED.show();
        digitalWrite(STATUS_LED_PIN, LOW);
        delay(100);
    }
}

void broadcastIdentifyPacket(uint8_t targetFloat) {
    ParadeSyncPacket packet;
    packet.magic = 0xEE;
    packet.mode = 0x42; // Identify Flash Command
    packet.masterMillis = millis();
    packet.activeFloat = targetFloat;
    packet.waveHead = 0;
    esp_now_send(broadcastMac, (uint8_t*)&packet, sizeof(packet));
}

void broadcastRapidRollCallPacket() {
    ParadeSyncPacket packet;
    packet.magic = 0xEE;
    packet.mode = 0x44; // 0x44 = 4s Rapid Attendance Roll Call
    packet.masterMillis = 0;
    packet.activeFloat = myFloatNumber;
    packet.waveHead = 0;
    esp_now_send(broadcastMac, (uint8_t*)&packet, sizeof(packet));
}

void startRapidRollCall(uint32_t now) {
    if (currentStandaloneMode != SHOW_MODE_RAPID_ROLL_CALL) {
        previousStandaloneMode = currentStandaloneMode;
    }
    currentStandaloneMode = SHOW_MODE_RAPID_ROLL_CALL;
    rapidRollCallStartTime = now;
    Serial.printf("[ROLL CALL] ⚡ 4-Second Rapid Attendance Roll Call started! (Initiator: Float %d)\n", myFloatNumber);
}

void renderRapidRollCall(uint32_t elapsedMs) {
    if (elapsedMs < 3500) {
        // Individual float slots: 0 to 6 (500ms each)
        uint8_t activeSlot = elapsedMs / 500; // 0..6
        uint8_t activeFloat = activeSlot + 1; // 1..7

        if (myFloatNumber == activeFloat) {
            // It's our turn! Illuminate brightly in our float's signature color
            CRGB color = FLEET_ROSTER_INFO[activeSlot].color;
            fill_solid(leds, FRONT_LEDS, color);
        } else {
            // Other floats stay completely dark so active runner is spotlighted!
            fill_solid(leds, FRONT_LEDS, CRGB::Black);
        }
    } else if (elapsedMs < 4000) {
        // Unison finale: Double Emerald Green flash across all 7 floats!
        uint32_t finaleMs = elapsedMs - 3500;
        if ((finaleMs < 200) || (finaleMs >= 300 && finaleMs < 500)) {
            fill_solid(leds, FRONT_LEDS, CRGB(0, 255, 80)); // Electric Emerald Green
        } else {
            fill_solid(leds, FRONT_LEDS, CRGB::Black);
        }
    } else {
        fill_solid(leds, FRONT_LEDS, CRGB::Black);
    }

    duplicateFrontToBack();
    FastLED.show();
}
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
void loop() {
    uint32_t now = millis();

    // ========================================================================
    // 1. DUAL HARDWARE BUTTON CONTROLLER (Button 1: GPIO 4/0, Button 2: GPIO 33)
    // ========================================================================

    // --- 0. STARTUP SAFETY GUARD & PIN ARMING ---
    // Prevents entering Float ID Config or Standby if pins are grounded/shorted at power-on.
    // Pins must be read as HIGH (released) at least once before arming press/hold detection.
    static bool b1Armed = false;
    static bool b2Armed = false;
    static uint32_t lastStuckWarning = 0;

    bool b1Raw = isButton1Down();
    bool b2Raw = isButton2Down();

    if (!b1Armed) {
        if (!b1Raw) {
            b1Armed = true;
            Serial.println("[BUTTON] Button 1 armed (pin released HIGH).");
        } else if (now - lastStuckWarning > 2500) {
            lastStuckWarning = now;
            Serial.printf("[HARDWARE WARNING] Button 1 is grounded LOW at boot (GPIO %d or BOOT GPIO %d)! Check wiring for short to GND.\n",
                          BUTTON_1_PIN, BUTTON_BOOT_PIN);
        }
    }

    if (!b2Armed) {
        if (!b2Raw) {
            b2Armed = true;
            Serial.println("[BUTTON] Button 2 armed (pin released HIGH).");
        } else if (now - lastStuckWarning > 2500) {
            lastStuckWarning = now;
            Serial.printf("[HARDWARE WARNING] Button 2 is grounded LOW at boot (GPIO %d)! Check wiring for short to GND.\n",
                          BUTTON_2_PIN);
        }
    }

    // --- BUTTON 1: PRIMARY SHOW DIRECTOR (GPIO 4 + BOOT GPIO 0) ---
    // - Leader Single Tap: In sleep -> Wakes fleet into Solo Show Mode; While awake -> Toggle 30s fleet routine
    // - Follower Single Tap: In sleep -> Wakes locally into Solo Show Mode; While awake -> Local sequence
    // - Leader Double Tap (< 400ms): 4-Second Rapid Attendance Roll Call (Mode 0x44)
    // - Long Hold (>= 5.0s): Float ID Configuration Mode (1s-4s white charging meter)
    static bool b1WasPressed = false;
    static uint32_t b1DownTime = 0;
    static bool b1LongHoldHandled = false;
    static uint8_t b1PendingTaps = 0;
    static uint32_t b1FirstTapReleaseTime = 0;

    bool b1Pressed = b1Armed && b1Raw;

    if (b1Pressed && !b1WasPressed) {
        b1WasPressed = true;
        b1DownTime = now;
        b1LongHoldHandled = false;
        Serial.println("[BUTTON 1] Press detected (LOW)...");
    } else if (b1Pressed && b1WasPressed) {
        uint32_t holdElapsed = now - b1DownTime;
        if (!b1LongHoldHandled) {
            if (holdElapsed >= 5000) {
                b1LongHoldHandled = true;
                b1PendingTaps = 0;
                handleFloatConfigMode();
                b1WasPressed = false;
                return;
            } else if (holdElapsed >= 1000) {
                // Progressive charging indicator (1 to 4 LEDs lit in crisp white)
                uint8_t chargeCount = (holdElapsed / 1000);
                if (chargeCount > 4) chargeCount = 4;

                for (int i = 0; i < FRONT_LEDS; i++) {
                    leds[i] = (i < chargeCount) ? CRGB(255, 255, 255) : CRGB::Black;
                }
                duplicateFrontToBack();
                FastLED.show();
                return;
            }
        }
    } else if (!b1Pressed && b1WasPressed) {
        b1WasPressed = false;
        uint32_t pressDuration = now - b1DownTime;
        Serial.printf("[BUTTON 1] Released (duration: %u ms)\n", pressDuration);

        if (pressDuration >= 1000 && !b1LongHoldHandled) {
            Serial.printf("[BUTTON 1] Hold aborted after %u ms -> returning to baseline with zero changes.\n", pressDuration);
        }

        if (!b1LongHoldHandled && pressDuration >= 50 && pressDuration < 600) {
            if (b1PendingTaps == 1 && (now - b1FirstTapReleaseTime <= 400)) {
                // DOUBLE TAP DETECTED
                b1PendingTaps = 0;
                if (isLeader) {
                    startRapidRollCall(now);
                    broadcastRapidRollCallPacket();
                    Serial.println("[LEADER] ⚡ 4-Second Rapid Attendance Roll Call started via Button 1 double-tap!");
                } else {
                    Serial.printf("[FOLLOWER] Float %d Button 1 double tap ignored (Roll call wave reserved for Leader).\n", myFloatNumber);
                }
            } else {
                b1PendingTaps = 1;
                b1FirstTapReleaseTime = now;
            }
        }
    }

    // Evaluate Button 1 single tap once double-tap window expires (400ms)
    if (b1PendingTaps > 0 && !b1Pressed && (now - b1FirstTapReleaseTime > 400)) {
        b1PendingTaps = 0;

        if (currentStandaloneMode == SHOW_MODE_CORRAL_STANDBY || currentStandaloneMode == SHOW_MODE_PHOTO_STATIC) {
            if (isLeader) {
                // Leader: Wake ENTIRE FLEET into Solo Show Mode (parade baseline, does NOT start 30s fleet routine)
                previousStandaloneMode = SHOW_MODE_AUTONOMOUS_SEQUENCE;
                currentStandaloneMode = SHOW_MODE_AUTONOMOUS_SEQUENCE;
                autonomousShowStartTime = now;

                fill_solid(leds, NUM_LEDS, CRGB(0, 255, 80)); // Emerald Green flash
                FastLED.show();
                digitalWrite(STATUS_LED_PIN, HIGH);
                delay(150);
                fill_solid(leds, NUM_LEDS, CRGB::Black);
                FastLED.show();
                digitalWrite(STATUS_LED_PIN, LOW);

                broadcastPhotoModePacket(0x47); // Disengage photo mode if active across fleet
                broadcastStandbyPacket(0x51);   // Wake entire fleet into solo show mode
                Serial.println("[LEADER] ☀️ Button 1 Tap -> Woke ENTIRE FLEET into Solo Show Mode! (Tap again while awake to start 30s Fleet Show)");
            } else {
                // Follower: Wake LOCALLY to baseline solo show animation (do NOT start theatrical fleet routine)
                previousStandaloneMode = SHOW_MODE_AUTONOMOUS_SEQUENCE;
                currentStandaloneMode = SHOW_MODE_AUTONOMOUS_SEQUENCE;
                autonomousShowStartTime = now;

                fill_solid(leds, NUM_LEDS, CRGB(0, 255, 80)); // Emerald Green flash
                FastLED.show();
                digitalWrite(STATUS_LED_PIN, HIGH);
                delay(150);
                fill_solid(leds, NUM_LEDS, CRGB::Black);
                FastLED.show();
                digitalWrite(STATUS_LED_PIN, LOW);

                Serial.printf("[FOLLOWER] Float %d Single Tap -> Woke locally into Solo Show Mode.\n", myFloatNumber);
            }
        } else if (isLeader) {
            // Leader active toggle
            if (currentStandaloneMode == SHOW_MODE_FLEET_30S_ROUTINE || currentStandaloneMode == SHOW_MODE_RAPID_ROLL_CALL) {
                currentStandaloneMode = SHOW_MODE_AUTONOMOUS_SEQUENCE;
                broadcastFleetRoutinePacket(0x00, 0);
                Serial.println("[LEADER] Early stop triggered via Button 1 -> returning to baseline.");

                for (int f = 0; f < 2; f++) {
                    fill_solid(leds, NUM_LEDS, CRGB(255, 140, 0));
                    FastLED.show();
                    digitalWrite(STATUS_LED_PIN, HIGH);
                    delay(120);
                    fill_solid(leds, NUM_LEDS, CRGB::Black);
                    FastLED.show();
                    digitalWrite(STATUS_LED_PIN, LOW);
                    delay(80);
                }
            } else {
                fleetRoutineCycle++;
                fleetRoutineStartTime = now;
                previousStandaloneMode = currentStandaloneMode;
                currentStandaloneMode = SHOW_MODE_FLEET_30S_ROUTINE;
                broadcastFleetRoutinePacket(0x30, 0);
                Serial.printf("[LEADER] 30s Fleet Show started via Button 1! (Cycle #%u)\n", fleetRoutineCycle);
            }
        } else {
            // Follower active: Button 1 is ignored while awake (only wake-up from Standby and 5s Hold Config are processed)
            Serial.printf("[FOLLOWER] Float %d Button 1 tap ignored while awake (wake-up only; fleet show reserved for Leader).\n", myFloatNumber);
        }
    }

    // --- BUTTON 2: AUXILIARY / PHOTO & STANDBY SWITCH (GPIO 33) ---
    // - Leader Single Tap: Toggle Castle Photo Mode across ENTIRE FLEET
    // - Follower Single Tap: Toggle Castle Photo Mode LOCALLY only
    // - Double & Triple Taps: Disabled
    // - Long Hold (>= 3.0s): Leader puts ENTIRE FLEET into Corral Standby; Follower puts local costume into Corral Standby
    static bool b2WasPressed = false;
    static uint32_t b2DownTime = 0;
    static bool b2HoldHandled = false;

    bool b2Pressed = b2Armed && b2Raw;
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

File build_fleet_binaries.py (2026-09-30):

import os
import sys
import subprocess
import shutil
import json

BASE_DIR = os.path.dirname(os.path.abspath(__file__))
INCLUDE_DIR = os.path.join(BASE_DIR, "include")
FIRMWARE_DIR = os.path.join(BASE_DIR, "firmware")
PIO_BUILD_DIR = os.path.join(BASE_DIR, ".pio", "build", "esp32dev")

FLOATS = [
    {"id": 1, "name": "The Train", "role": "LEADER", "tag": "CASEY JR."},
    {"id": 2, "name": "The Title Drum", "role": "FOLLOWER", "tag": "THE DRUM"},
    {"id": 3, "name": "The Spinning Turtle", "role": "FOLLOWER", "tag": "TURTLE"},
    {"id": 4, "name": "The Spinning Snail", "role": "FOLLOWER", "tag": "SNAIL"},
    {"id": 5, "name": "Cinderella's Coach", "role": "FOLLOWER", "tag": "COACH"},
    {"id": 6, "name": "Pete's Dragon", "role": "FOLLOWER", "tag": "ELLIOTT"},
    {"id": 7, "name": "To Honor America", "role": "FOLLOWER", "tag": "FLAG & EAGLE"},
]

def write_float_config(float_id):
    os.makedirs(INCLUDE_DIR, exist_ok=True)
    config_file = os.path.join(INCLUDE_DIR, "float_config.h")
    content = f"""#ifndef FLOAT_CONFIG_H
#define FLOAT_CONFIG_H

// Auto-generated dedicated float identity
#ifndef COMPILED_FLOAT_ID
#define COMPILED_FLOAT_ID {float_id}
#endif

#endif // FLOAT_CONFIG_H
"""
    with open(config_file, "w", encoding="utf-8") as f:
        f.write(content)

def build_binary(float_id=0):
    write_float_config(float_id)
    cmd = [sys.executable, "-m", "platformio", "run"]
    res = subprocess.run(cmd, cwd=BASE_DIR, capture_output=True, text=True)
    if res.returncode != 0:
        print(f"[ERROR] Build failed for Float {float_id}:\n{res.stderr or res.stdout}")
        return False
    
    os.makedirs(FIRMWARE_DIR, exist_ok=True)
    # Copy bootloader and partitions
    src_bl = os.path.join(PIO_BUILD_DIR, "bootloader.bin")
    src_pt = os.path.join(PIO_BUILD_DIR, "partitions.bin")
    src_fw = os.path.join(PIO_BUILD_DIR, "firmware.bin")

    if os.path.exists(src_bl):
        shutil.copy2(src_bl, os.path.join(FIRMWARE_DIR, "bootloader.bin"))
    if os.path.exists(src_pt):
        shutil.copy2(src_pt, os.path.join(FIRMWARE_DIR, "partitions.bin"))
    
    bin_name = f"firmware_float{float_id}.bin" if float_id > 0 else "firmware.bin"
    target_fw = os.path.join(FIRMWARE_DIR, bin_name)
    shutil.copy2(src_fw, target_fw)

    # Manifest
    float_name = "Generic / Auto"
    for f in FLOATS:
        if f["id"] == float_id:
            float_name = f"{f['name']} ({f['role']})"
            break

    manifest = {
        "name": f"MSEP Costume - {float_name}",
        "version": "1.0.0",
        "new_install_prompt_erase": False,
        "builds": [
            {
                "chipFamily": "ESP32",
                "parts": [
                    {"path": "bootloader.bin", "offset": 4096},
                    {"path": "partitions.bin", "offset": 32768},
                    {"path": bin_name, "offset": 65536}
                ]
            }
        ]
    }
    manifest_name = f"manifest_float{float_id}.json" if float_id > 0 else "manifest.json"
    manifest_path = os.path.join(FIRMWARE_DIR, manifest_name)
    with open(manifest_path, "w", encoding="utf-8") as f:
        json.dump(manifest, f, indent=2)

    print(f"[OK] Successfully built Float {float_id} -> {bin_name} & {manifest_name}")
    return True

def build_all():
    print("==================================================")
    print(" Building MSEP Costume ROM Binaries for All Floats")
    print("==================================================")
    # Generic build first
    build_binary(0)
    for flt in FLOATS:
        build_binary(flt["id"])
    print("==================================================")
    print(" Finished building all 7 float ROM binaries!")
    print("==================================================")

if __name__ == "__main__":
    if len(sys.argv) > 1 and sys.argv[1].isdigit():
        build_binary(int(sys.argv[1]))
    else:
        build_all()

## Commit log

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2026-09-16 Enhance stage LED color saturation (vivid hot pink wings, flame orange hair, emerald body) and fix unlit LEDs
    [main.cpp, simulator.py]
2026-09-16 Fix rebuild dependency tracking, add port readiness check, and fix sparkle rate threshold
    [main.cpp, simulator.py]
2026-09-16 Calibrate hardware color order to RGB, implement USB brownout protection, and add decaying starlight sparkle engine
    [main.cpp, simulator.py]
2026-09-16 revert: restore Milestone 2 fleet synchronization firmware pending fairy lights arrival
    [main.cpp]
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2026-09-22 fix: disable browser caching and add direct onclick handler for Wi-Fi settings
    [simulator.py]
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2026-09-22 fix: synchronize follower traveling wave locally at 60 FPS from master clock
    [main.cpp]
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2026-09-23 fix: Reliable button mode switching with LED flash indicators and custom artwork palette
    [MSEP_Costume.ino, main.cpp]
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2026-09-24 fix(firmware): support ESP32 Arduino Core 2.x and 3.x+ for ESP-NOW receive callback
    [MSEP_Costume.ino, main.cpp]
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2026-09-27 fix: prevent baseline show from overwriting 1-4s white charging meter LEDs
    [MSEP_Costume.ino, main.cpp]
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2026-09-28 fix: smooth corral standby starlight shimmer and calibrate visible midnight base glow
    [MSEP_Costume.ino, main.cpp]
2026-09-28 fix: slow down corral standby, reduce active leds, and soften shimmer brightness
    [MSEP_Costume.ino, main.cpp]
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2026-09-28 fix: correct cue effect mapping - color_match and pulse now correctly map to breathe (eff=1)
    - Python cue_effect_map: color_match->1, pulse->1, flash_slow->7, sparkle_storm->8
    - Firmware: add effect 5 (solid/no sparkle), 7 (slow blink), 8 (sparkle storm) handlers
    - Previously: pulse->7 and color_match->0 both silently fell to steady_sparkle default
    - Mirror changes in arduino/MSEP_Costume/MSEP_Costume.ino per Rule 5
    [MSEP_Costume.ino, main.cpp, simulator.py]
2026-09-28 fix: remove background sparkles from breathing glow show cue
    - Breathing cue (eff == 1) was overlaying COSTUME_SPARKLE_RATE (1.5%), overwhelming the smooth brightness fade and making it look like pure sparkles.
    - Synchronized change to src/main.cpp and arduino/MSEP_Costume/MSEP_Costume.ino per Rule 5.
    [MSEP_Costume.ino, main.cpp]
2026-09-28 fix: adjust breathing pulse depth and tempo for dramatic visual contrast
    - Changed beatsin8 min brightness from 120 (47% brightness) to 20 (8% brightness).
    - Set tempo to full BPM instead of BPM/2 for crisp, noticeable pulsation.
    - Mirrored changes between src/main.cpp and arduino/MSEP_Costume/MSEP_Costume.ino per Rule 5.
    [MSEP_Costume.ino, main.cpp]
2026-09-28 fix: implement relative show clock and hardware-accelerated sinf breathing pulse
    - Added autonomousShowStartTime so timeline starts at 0.0s the instant the costume is woken from Corral Standby.
    - Replaced frozen FastLED beatsin8 with hardware-accelerated sinf(normTime * 2 * PI), matching app.js evalGlobalPattern.
    - Dynamic pulse sweeps smoothly from 15% dim to 100% radiant full brightness at exact speedBpm.
    - Mirrored changes in arduino/MSEP_Costume/MSEP_Costume.ino per Rule 5.
    [MSEP_Costume.ino, main.cpp]
2026-09-28 feat: implement Feature 10 - Timeline Hover-Scrubbing & Cue Quantization Grid Snapping
    - Hover-scrubbing engine: displays cyan ghost needle + floating tooltip, previewing canvas lighting in real time.
    - Live grid snapping: selector (Off, 0.5s, 1.0s, 2.0s) & 🎯 Quantize button integrated with Undo/Redo stack.
    - Trim & Drag Snapping: cue start/end trimming automatically snaps boundaries to gridSnapInterval.
    - Verified syntax with node -c simulator/app.js (SUCCESS) and bumped to app.js?v=52.
2026-09-28 fix: implement missing global cue animation effects across simulator and firmware
    - Added global handlers in app.js evalGlobalPattern for: flash_slow, write_on_off, sparkle_storm, rainbow_cycle, off.
    - Added firmware handlers in src/main.cpp and arduino/MSEP_Costume/MSEP_Costume.ino for eff 9 (write_on_off) and eff 10 (rainbow_cycle).
    - Updated simulator.py cue_effect_map with distinct codes.
    - Bumped version to app.js?v=53.
    [MSEP_Costume.ino, main.cpp, simulator.py]
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2026-09-30 fix: route /api/build_fleet_binaries in do_GET and use POST method in app.js
    [simulator.py]
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2026-10-01 fix: route static assets and bump simulator cache version to v=68
    [simulator.py]
2026-10-01 fix: bind pixie dust, candle flicker, sparkle storm, and filament glow directly to tempo speed slider
    [MSEP_Costume.ino, main.cpp]
2026-10-03 fix: calibrate mouse scamper to single-point head with directional strand tail
    [MSEP_Costume.ino, main.cpp]
2026-10-03 fix: calibrate mouse scamper to true 2D spatial coordinates with directional history tail
    [MSEP_Costume.ino, main.cpp]
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2026-10-03 feat: add transparent Pete's dragon asset and turnkey Flex PCB demo suite
    [petes_dragon_bom.csv, petes_dragon_fpc.kicad_pcb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]
2026-10-03 fix: calibrate PCB preview and layout coordinates to 1:1 coincident alignment with dragon artwork
    [petes_dragon_fpc.kicad_pcb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]
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2026-10-03 fix(pcb): enforce boundary-constrained routing to prevent traces leaving PCB outline
    [petes_dragon_fpc.kicad_pcb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]
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2026-10-03 fix(pcb): format kicad_pcb with KiCad 5 module syntax for EasyEDA Standard compatibility
    [petes_dragon_fpc.kicad_pcb]
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2026-10-04 feat: add 3D wire snap-retention clips, LED snap collars, and spool posts to TPU panel
    [petes_dragon_tpu_panel.scad]
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2026-10-04 fix(3d-panel): resolve geometry offset bug, clean continuous wire channels, non-colliding clips, and border eyelets
    [petes_dragon_tpu_panel.scad]
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2026-10-04 fix: export complete mechanical assembly (panel, snap clips, trench beds, well walls) in STL
2026-10-04 fix: attach exportGroup to scene and compute updateMatrixWorld before STL parsing
2026-10-04 feat: generate 100% watertight manifold binary STL with true physical trenches and retention snap clips
    [petes_dragon_tpu_panel.stl]
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2026-10-05 feat(3d-panel): 1mm LED pocket floor recess with 3mm collar walls and 2mm table clearance
    [petes_dragon_tpu_panel.scad, petes_dragon_tpu_panel.stl]
2026-10-05 fix(3d-panel): fix stacked debossed digits, align horizontal collars matching preset, and fit clean dragon silhouette
    [petes_dragon_tpu_panel.scad, petes_dragon_tpu_panel.stl]
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2026-10-05 fix(3d-panel): sleek 45-deg eyelets without 2mm straight section or pointy ledges
    [petes_dragon_tpu_panel.scad, petes_dragon_tpu_panel.stl]
2026-10-05 fix(3d-panel): pure smooth circular outside eyelets with zero points or sharp corners
    [petes_dragon_tpu_panel.scad, petes_dragon_tpu_panel.stl]
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2026-10-05 fix(3d-panel): correct front/back Z-orientation and align non-mirrored dragon graphic across STL, ViewSTL, and previewer
    [petes_dragon_tpu_panel.stl]
2026-10-05 fix(3d-panel): correct debossed number glyph orientation for natural left-to-right reading from underside
    [petes_dragon_tpu_panel.scad, petes_dragon_tpu_panel.stl]
2026-10-05 docs: clarify Snapmaker U1 build volume as 270x270mm and bed margins
2026-10-05 feat: integrate TPU 3D preview modal, live STL compilation, 2x2mm window mode, and collar collision avoidance
    [simulator.py]
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2026-10-05 fix: resolve unclosed modal tags and wire preview TPU button directly with cache invalidation
    [petes_dragon_tpu_panel.stl, tpu_panel.stl]
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2026-10-05 fix: enforce artwork boundary containment clamping in TPU PBD solver for zero-spill Front and Back panels
    [petes_dragon_tpu_panel.scad, petes_dragon_tpu_panel.stl, tpu_panel.stl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]
2026-10-05 fix: auto-recompile TPU STLs when preview detects stale layout signature for active graphic
    [petes_dragon_tpu_panel.scad, petes_dragon_tpu_panel.stl, tpu_panel.stl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]
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2026-10-05 fix: clean up Three.js scene meshes and guard async modal loading to prevent graphic layering artifacts
    [petes_dragon_tpu_panel.scad, petes_dragon_tpu_panel.stl, tpu_panel.stl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]
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2026-10-05 fix: make right eyeglass opening transparent while keeping blue shell section and all linework intact
    [petes_dragon_tpu_panel.scad, petes_dragon_tpu_panel.stl, tpu_panel.stl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]
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2026-10-06 fix: add cold-boot button arming safety guard and hardware diagnostic banner
    [MSEP_Costume.ino, main.cpp]
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2026-10-06 fix: resolve undefined buttons and ensure all 7 floats visible on deploy page
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2026-10-06 fix: restore organic Pete's Dragon silhouette contour and calibrate 8.0-inch chassis width
    [petes_dragon_tpu_panel.scad, petes_dragon_tpu_panel.stl, tpu_panel.stl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]
2026-10-06 fix: restore full green body and black linework in color inlays; add selectable LED numbers option
    [petes_dragon_tpu_panel.scad, petes_dragon_tpu_panel.stl, tpu_panel.stl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]
2026-10-06 fix: resolve LED numbers toggle recompile caching and signature synchronization
    [petes_dragon_tpu_panel.scad, petes_dragon_tpu_panel.stl, tpu_panel.stl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]
2026-10-06 fix: synchronize include_led_numbers specs persistence and canvas number toggle isolation
    [petes_dragon_tpu_panel.scad, petes_dragon_tpu_panel.stl, tpu_panel.stl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]
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2026-10-06 feat: selectable clip grooves, top nubs, bottom wire portal, and led numbers deboss fix
    [petes_dragon_tpu_panel.scad, petes_dragon_tpu_panel.stl, tpu_panel.stl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]
2026-10-07 fix: top nubs geometry enhancement (0.70mm protrusion, flush with rim, clean wire notches) and underside lighting
    [petes_dragon_tpu_panel.scad, petes_dragon_tpu_panel.stl, tpu_panel.stl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]
2026-10-07 feat: add 2mm wire retention roof with 45deg chamfer, fix modal toggle reselection and slicer cache busting
    [petes_dragon_tpu_panel.stl, tpu_panel.stl, tpu_panel_back.stl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]
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2026-10-07 fix(3d-panel): resolve missing top nubs on Turtle and synchronize server process and stale-guard
    [petes_dragon_tpu_panel.scad, petes_dragon_tpu_panel.stl, tpu_panel.stl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]
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2026-10-07 fix(3d-panel): eliminate pointy corner artifacts on eyelets using pure CrossSection circle extrusion
    [petes_dragon_tpu_panel.stl, petes_dragon_tpu_panel_lid.stl, tpu_panel.stl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]
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2026-10-07 fix(snail): revert default snail artwork to original and fix layout dropdown switching
    - Restored presets/spinning_snail.json to original artwork with graphicType 'spinning_snail'
    - Pointed spinning_snail in simulator/app.js directly back to assets/spinning_snail.png
    - Restored 3d_panels/active_artwork.png to original snail
    - Fixed dropdown event handler and presetFileMap so selecting Float 4 immediately restores original artwork on canvas
    - Retained simplified version as an optional test option (spinning_snail_simplified)
    - Updated PROJECT_PROGRESS.md
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2026-10-08 fix(3d-panel): flush lid screw boss landings and relieve alignment ridge around chassis pillars
    [petes_dragon_tpu_panel_lid.stl, tpu_panel_back_lid.stl, tpu_panel_back_multicolor.3mf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]
2026-10-08 fix(3d-panel): deep eyelet gusset wall anchors and remove LED well wire notch overhang
    [petes_dragon_tpu_panel.stl, tpu_panel.stl, tpu_panel_back.stl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]
2026-10-08 fix(assets): 2 gold-outlined wheels, clean gold poles, gold square flag, and roof dome on title drum
2026-10-08 fix(assets): align Title Drum wheel positions, open cab window, and add streamer flagpole
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2026-10-08 fix: lock btf strip led zoom scaling to 1:1 with canvas and artwork
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2026-10-09 feat: 10mm TPU chassis (+1mm wire room), 1.8mm sockets, 3mm lateral clip clearance, tangent orientation, and 3.4mm round windows
    [petes_dragon_tpu_panel.scad, petes_dragon_tpu_panel.stl, petes_dragon_tpu_panel_lid.stl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]
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2026-10-09 fix: constrain led scatter and presets strictly to character artwork
    [tpu_panel_back_multicolor.3mf, tpu_panel_front_multicolor.3mf]
2026-10-09 fix: scale led pill slots and tpu collar shadows proportionally to plate size
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2026-10-09 feat: circular aperture 3D carryover, 5mm channel clearance & live red drag feedback, bridge clearance, and clean monolithic arches
    [petes_dragon_tpu_panel.scad, petes_dragon_tpu_panel.stl, petes_dragon_tpu_panel_lid.stl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]
2026-10-09 refactor: update side clearance to 3.0mm and maintain 5.0mm channel opening corridor
    [petes_dragon_tpu_panel.stl, tpu_panel.stl, tpu_panel_back.stl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]
2026-10-09 fix: update wire channel opening clearance from 5mm to 3mm and update warning badges
    [petes_dragon_tpu_panel.stl, tpu_panel.stl, tpu_panel_back.stl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]
2026-10-09 feat: implement 2.5mm capsule Euclidean clearance rule and fix false-positive red warnings on layout canvas
    [petes_dragon_tpu_panel.scad, petes_dragon_tpu_panel.stl, petes_dragon_tpu_panel_lid.stl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]
2026-10-09 fix: focus clearance checking strictly on wire entrances and remove side-wall red tabs
2026-10-09 fix: synchronize horizontal channel alignment between layout screen and 3d preview
    [petes_dragon_tpu_panel.scad, petes_dragon_tpu_panel.stl, petes_dragon_tpu_panel_lid.stl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]
2026-10-09 fix: resolve 3D preview modal loading hang and duplicate event triggers
    [petes_dragon_tpu_panel.stl, tpu_panel.stl, tpu_panel_back.stl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]
2026-10-09 fix: enforce horizontal collar orientation across 3D compilation pipeline and preview
    [petes_dragon_tpu_panel.scad, petes_dragon_tpu_panel.stl, tpu_panel.stl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]
2026-10-09 fix: enforce round optical aperture precedence in 3D preview and update STLs
    [petes_dragon_tpu_panel.stl, tpu_panel.stl, tpu_panel_back.stl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]
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2026-10-09 fix: render strain relief bridges independently of wiring toggle and enable by default
2026-10-09 fix: map strain relief bridges 1:1 to 3D STL plate positions and remove outside badge icons
    [tpu_panel_back_multicolor.3mf, tpu_panel_front_multicolor.3mf]
2026-10-09 feat: implement strict clearance-aware LED placement and relaxation solver to prevent 2mm/2.5mm collar warnings
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2026-10-09 fix: ensure layout aperture selection carries over to 3D preview and STL exports
    [petes_dragon_tpu_panel.scad, petes_dragon_tpu_panel.stl, petes_dragon_tpu_panel_lid.stl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]
2026-10-09 fix(3d-preview): synchronize live layout canvas with 3D model and add instant recompile button
    [petes_dragon_tpu_panel.scad, petes_dragon_tpu_panel.stl, tpu_panel.stl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]
2026-10-09 fix(3d-models): compile fresh STLs with separated LED 37 and 38 collars
    [petes_dragon_tpu_panel.scad, petes_dragon_tpu_panel.stl, petes_dragon_tpu_panel_lid.stl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]
2026-10-09 fix(numbering): synchronize 2D layout canvas bulb numbering to 1-indexed (1 to N) matching 3D engraved plate numbers
    [petes_dragon_tpu_panel.scad, petes_dragon_tpu_panel.stl, petes_dragon_tpu_panel_lid.stl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]
2026-10-09 fix(preview): replace undefined round() with toFixed(1) in loadTpuModalData
    [petes_dragon_tpu_panel.scad, petes_dragon_tpu_panel.stl, tpu_panel.stl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]
2026-10-09 fix(alignment): eliminate PBD solver coordinate drift so LED lights align 1:1 with 3D aperture holes
    [petes_dragon_tpu_panel.scad, petes_dragon_tpu_panel.stl, petes_dragon_tpu_panel_lid.stl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]
2026-10-09 fix(save): enable direct 1-click float saving in sidebar with instant disk write and feedback
    [petes_dragon_tpu_panel.scad, petes_dragon_tpu_panel.stl, petes_dragon_tpu_panel_lid.stl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]
2026-10-09 fix(simulator): dynamically update timestamp and filename on float save
    [petes_dragon_tpu_panel.scad, petes_dragon_tpu_panel.stl, tpu_panel.stl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]
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2026-10-11 feat: enforce 5mm perimeter wall keep-out clearance for LED placement
2026-10-11 fix: evaluate 5mm perimeter wall clearance against true 3D STL panel contour
2026-10-11 fix: evaluate 5mm perimeter clearance against LED well wire entrance sides
2026-10-11 fix: pre-filter candidate pool to prevent perimeter wall violations and enforce 2.0mm collar bridge clearance rule
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2026-10-11 fix: restore plate size and target LED count on preset loading
2026-10-11 fix: align Pete's Dragon 100-LED preset to 245mm Large plate with 0 perimeter warnings
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2026-10-13 fix(simulator): use live per-float silhouette contour when redistributing LEDs
2026-10-13 fix(simulator): restore Pete's Dragon 100/80-LED distribution and 3D TPU spec clearance
2026-10-14 fix: ensure transparent dragon default, fix startup drum graphic, and fix initial float led distribution
2026-10-14 fix(3d-panel): eliminate perimeter wall collar artifacts, safe-clamp LED wells, and compile large 5-color Turtle armor
2026-10-14 feat: align 2D/3D strain relief bridges, portal notch tab clearance, and dual-side LED visibility
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2026-10-15 docs: add Snapmaker U1 5-color PLA printing guide and strategy comparison
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2026-10-15 fix: resolve JavaScript syntax error and center camera in SWIFTVEST 3D assembly viewer
2026-10-15 docs: document SWIFTVEST 3D assembly viewer bug fix
2026-10-15 feat: redesign SWIFTVEST attachment with ultra-compact hidden rear C-clips
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2026-10-15 feat: resolve screw hole orientation and add anti-slip locking tunnel for SWIFTVEST clip
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2026-10-16 fix: export native RS-274X Gerbers and fix KiCad 5 closed outline for JLCPCB quote viewer
2026-10-16 fix: update WS2812B-2020 LCSC part number to C965555 in BOM
2026-10-16 fix: update BOM part number to in-stock WS2812B-2020-V6 (C52917434)
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2026-10-18 fix: enforce pure flat 16x16 matrix 3D plate with 3.4mm windows and 4 corner sewing holes
2026-10-18 fix: export 3MF as unified multi-part parent assembly and fix float color slot names
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2026-10-18 fix: ensure all 256 LEDs illuminate in standby mode without duplicateFrontToBack blackout
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2026-10-20 fix: position 16x16 matrix alignment lip on backside with 2mm wall width and additive Z height
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2026-10-24 fix(3d-panels): lock 16x16 matrix STL bounding centers and align 3mm lenses coaxially with LEDs
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2026-10-24 fix(3d-modal): fix blank 3d preview modal, enable multithreaded server and parallel stl loading
2026-10-24 fix(3d-plate): eliminate edge antennae whiskers using shared apex corner registration anchors
2026-10-24 fix(3d-plate): encapsulate lens registration anchor inside faceplate to eliminate protruding corner pole
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2026-10-27 fix(3d-clips): correct bed orientation, resize to ~3.0mm wire & add 5-slot test gauge comb
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2026-10-30 fix: synchronize simulator 16x16 matrix with physical 3d-printed cutouts and update presets
2026-10-30 fix: preserve Pete's Dragon artwork colors during show cues and scale backlight LEDs to 50% brightness
2026-10-30 fix: resolve ESP32 COM port suspension, verify physical upload, and lock COM5 in platformio.ini
2026-10-30 fix: calibrate GRB color order, window/backlight indexing & USB soft-start for 16x16 matrix
2026-10-31 feat: robust float preset saving and loading pipeline with load button and deep clone cache
    - Add dedicated [Load] button (#loadPresetBtn) adjacent to presetSelect on Layout tab
    - Reorganize preset dropdown into categorized optgroups (Defaults, Disk, Browser)
    - Add active preset confirmation badge (#presetLoadedBadge) with file tooltip
    - Enforce deep cloning in getPresetDataForRunner and applyProfileData to prevent cache tainting
    - Preserve 16x16 Matrix hardware mode when loading official baseline presets
    - Guard scatterLedsOnGraphic so fairy light scattering never executes in matrix mode
    - Synchronize activeSingleShirtRunnerSlot to loaded floatId without lineup corruption
    - Add microsecond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
2026-11-04 feat: overhaul Lightning Bug graphic with stubby proportions, big head, simple legs, and short fat red tail
2026-11-04 fix: set active Lightning Bug graphic to transparent polygon float trace
2026-11-04 fix: recolor area between legs to green on Lightning Bug graphic
2026-11-04 fix: recolor wing facet to blue, tail triangle to yellow, and antennae gap to transparent
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2026-11-04 style: turn antenna base stalk yellow and smooth red cap outer contour on Lightning Bug
2026-11-04 style: smooth neck line, wing/tail junction, front foot, eye, smile, and face silhouette on Lightning Bug
2026-11-04 style: round off top corners of all three green legs on Lightning Bug
2026-11-04 style: smooth tail silhouette, foot bottom, baseline, wing seam, and cap bottom on Lightning Bug
2026-11-04 style: smooth antenna base divider, red tail curve, tail tip border, and tip edge on Lightning Bug
2026-11-04 feat: 16x16 face-down 3D panels with 0.4mm clear backing, 2mm frame, 0.0mm lip, and Snapmaker U1 Nozzle 3 pause mapping
2026-11-04 fix(3d-panel): correct face-down print chirality with bed X-mirroring and align modal front view
2026-11-04 fix(3d-panel): guarantee 100% preservation of all layout windowed LEDs across all colors and fireworks
2026-11-04 fix(3d-panel): resolve Snapmaker Orca 3MF XML parsing error and sanitize assembly metadata
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2026-11-05 fix(warm-white): calibrate brightness to match physical backlights and improve sparkle contrast
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2026-11-05 fix(3d-panel): restore 2mm black shelf gap and continuous solid foundation under 2mm frame wall
2026-11-05 feat(lightning-bug): add bold black curly filigree scrollwork to wing matching MSEP float
2026-11-05 feat(lightning-bug): add spinning beanie propeller, extended cap, and segmented tail
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2026-11-06 feat: harmonize lightning bug character linework and fix 3D solid plate dynamic naming
2026-11-06 fix: clean hat border artifacts, restore wing-to-body line, and harmonize vertical chest divider
2026-11-06 feat: add curved wing divider and Disney eye catchlight to lightning bug (discard Option 4 antennae)
2026-11-06 feat: add organic bowed wing curve and Disney dimple smile to lightning bug
2026-11-06 fix: revert artificial wing alterations and dimple smile; restore authentic wing from Photoshop 3 with eye sparkle
2026-11-06 fix: restore bottom of wing 100% to Photoshop 3 version without artificial black bridge
2026-11-06 feat: add subtle Disney smile dimple tick to bug right / frame left on Photoshop 4 base
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2026-11-06 fix: true 5-point vector stars and universal fine-layer calibration on Dopey medal
2026-11-06 fix: calibrate all 6 engraved stars to strictly point straight UP in 3D CAD space
2026-11-06 fix: eliminate background corrugated texture while preserving all Dopey, camera, runner, and lettering relief
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2026-11-07 feat: enable live color sliders, add Revert button, and mount inspector in Layout tab
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2026-11-07 feat: implement 562-LED closed loop simulation, multi-track timeline, and front-back view flip
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2026-11-09 feat(3d_panels): add 1.0mm flat and recessed snap test coupons for KAM snaps
2026-11-09 feat(3d_panels): generate full all-black 16x16 test panel with 1.0mm recessed snap tabs
2026-11-09 feat(3d_panels): add deeper recessed snap tabs (0.6mm and 0.4mm floors) for high-tension snaps
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2026-11-10 feat(simulator): add selectable KAM snap tabs and recessed floor thickness controls (0.6mm, 0.8mm, 1.0mm, or None)
    - Integrated selectable KAM snap wing tabs and counterbore wells into Simulator Layout tab and 3D preview modal toolbar
    - Support 0.6mm, 0.8mm (default standard), 1.0mm solid floor thickness, and None (standard flush 176mm plate with sewing holes)
    - Automatic background watertight 3D compilation with live Three.js modal re-render and 2D canvas workbench backdrop visualization
    - Synchronized SIMULATOR_USER_GUIDE.md and PROJECT_PROGRESS.md
2026-11-11 fix: calibrate panel test for 562 LEDs, resolve sparkle PRNG harmonic resonance, and align 562 solo parade modes
2026-11-11 fix(panel_test): apply R<->G swap to fairy strands 1 and 2 to match RGB pebble diodes with GRB matrix panels
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2026-11-11 fix(flasher): force 562-LED full costume mode in simulator flasher and mirror back panel at index 281
2026-11-11 fix: restore RGB fairy swap for 3-3-3 Red/White/Blue and enforce 151 active matrix LEDs
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2026-11-13 fix: increase Wi-Fi STA timeout to 8s and expand UDP stream buffer to 2048 bytes for 562-LED frames
2026-11-13 fix: match Photo Mode fairy triplet palette and apply Hardware LED Output to fairy baseline
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2026-11-13 fix: persist Hardware LED Output in localStorage (default 100%) instead of letting float presets reset it to 80%
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2026-11-13 fix: stream and render independent back 16x16 matrix for 562-LED waterfall progression
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2026-11-13 fix: flow flag_ripple from eagle down the flag and respect custom progressions
